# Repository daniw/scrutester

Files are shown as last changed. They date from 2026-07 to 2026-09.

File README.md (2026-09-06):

# Scrutester
Battery powered tester for electrical inspection in formula student. 

## Functions
* Voltage source 0 .. 60V, 1A max
* Current source 0 .. 10A, 5V max
* Milliohm resistance measurement with 4 wire connection, 1A measurement current
* Isolation resistance measurement with adjustable test voltage up to 1000V DC
* Voltmeter &pm; 1000V
* Amperemeter &pm; 10A
* Charging from output terminals

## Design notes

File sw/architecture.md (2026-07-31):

# BatSource — Firmware Architecture

> Lives in this repo (moved from the older `bat_Source` checkout) so it travels
> with the code it describes. If you change firmware structure, change this file
> in the same commit.

## 1. Hardware Platform

### Microcontroller
**STM32G474VET6** (Arm Cortex-M4, 170 MHz)
- Selected for its High-Resolution Timer (HRTIM, 217 ps resolution) needed for precise converter PWM
- 512 KB flash, 128 KB SRAM
- 5× ADC, 2× DAC, HRTIM, I2C, SPI, UART, QUADSPI, RTC

### Key External ICs

| IC | Role | Interface |
|----|---|---|
| BQ76905 (TI) | Battery Management System — 4-cell LiFePO₄ monitoring, protection, passive balancing | I2C4 (0x08) |
| ADS131M04 (TI) | 4-ch precision sigma-delta ADC for isolation current measurement | SPI3 |
| LMG2100R044 ×2 (TI) | GaN half-bridge drivers for primary buck-boost converter | HRTIM GPIO |
| 1EDN7512B | Gate driver for HV flyback primary switch | HRTIM GPIO |
| W25N01GV | 1 Gbit QSPI NAND flash — menu icon store, intended for data logging | QUADSPI |
| ZD24C02B | 2 kbit I2C EEPROM for calibration / ID data | I2C4 (0x50) |
| TCA9554 (PCA9554) | I2C I/O expander — hardware ID reading | I2C4 (0x20) |
| LP5817 / LP5816 | LED drivers — status LEDs and LCD backlight on UI board | I2C4 (0x2D / 0x2C) |
| OPT3004 | Ambient light sensor — automatic backlight control | I2C4 (0x44) |
| LCD (240×320 TFT) | Display — sunlight-readable, replaces original OLED | SPI4 (bit-banged) |

### Battery
4× Tenpower IFR26700-45HE LiFePO₄ cells in series (~14.4 V nominal, 56.96 Wh).
The BQ76905 monitors each cell, measures pack current via a 5 mΩ shunt, and controls charge/discharge MOSFETs.

---

## 2. Power Conversion Topology

### Primary Converter (LV — PS1-1BA)
- **Topology**: 4-switch synchronous buck-boost
- **Switches**: 2× LMG2100R044 GaN half-bridges (44 mΩ R_DS(on), 35 A rated)
- **Switching frequency**: 1 MHz (high-speed mode) / 50 kHz (low-speed mode)
- **Modes**: Battery charging, 60 V voltage out, 10 A current out, resistance measurement

### Secondary / HV Converter (PS1-1BA)
- **Topology**: Isolated flyback (final design)
- **Purpose**: Generate up to 500 V for insulation resistance testing
- **Primary switch**: 200 V MOSFET driven by 1EDN7512B gate driver
- **Transformer**: Custom RM5 core, 8-turn primary
- **Control**: PWM via HRTIM at 350 kHz, RCD snubber on primary switch node

### Output Stage
- Output relays K1/K2/K3 for galvanic isolation between measurement paths
- Gas discharge tubes (GDT) for transient suppression on output terminals
- Shrouded 4 mm safety jacks (Stäubli SLB4-F6.3)

---

## 3. Firmware Architecture

### Design Pattern
Bare-metal, **event-driven**, single-threaded. No RTOS.

```
┌──────────────────────────────────────────────┐
│                   main()                     │
│   peripheral init → main loop                │
│                                              │
│   while(1) {                                 │
│     cli_loop();                              │
│     process_event(event_Get());              │
│     HAL_Delay(1);                            │
│   }                                          │
└──────────────────────────────────────────────┘
         │
         ▼
┌────────────────────┐    ┌────────────────────────────┐
│   Event Queue      │    │  ADC1 DMA-complete ISR     │
│   (64 entries)     │    │  ~25 kHz (CTRL_FREQ)       │
│   event.h/.c       │    │  adc_convert_fast_data()   │
│                    │    │  ctrl_main_ctrl()          │
└────────────────────┘    └────────────────────────────┘
         │
         ▼
┌─────────────────────────────┐
│  State Machine (20 ms tick) │
│  statemachine.h/.c          │
│  Dispatches to mode modules │
└─────────────────────────────┘
```

### Event System (`event.h` / `event.c`)
- Circular queue of 64 `EVENT_STRUCT` items
- Each event carries: type (`EVENTS` enum), optional callback pointer, optional argument
- ISRs and peripheral callbacks post events; the main loop drains them
- `event_Add()` reserves, fills and publishes a slot inside one critical
  section. This is deliberate: filling then publishing lock-free is **not** safe
  here, because reading `head` and filling the slot are separate steps, and a
  producer preempted between them can clobber a slot another producer has
  already published.

| Event | Trigger |
|---|---|
| `EVENT_IIC_RX/TX` | I2C DMA transfer complete |
| `EVENT_IIC_ERROR` | I2C NACK / bus error |
| `EVENT_EEPROM_READ` | EEPROM read complete |
| `EVENT_EEPROM_TIMEOUT` | EEPROM no-response |
| `EVENT_SM_STEP` | State-machine timer tick (20 ms) |
| `EVENT_BMS_TIMER` | BMS polling timer (1 s) |

### State Machine (`statemachine.h` / `statemachine.c`)
Step period: **20 ms** (`STATEMACHINE_STEP_PERIOD_mS`), driven from TIM2 via the
software timer list in `timer.c`. Handles UI menu navigation, output enable
logic, and the protection interlock.

| Mode | Description |
|---|---|
| `STATEMACHINE_IDLE` | Startup / menu navigation |
| `STATEMACHINE_MODE_60V_OUT` | 60 V regulated voltage output (hold OUT to enable) |
| `STATEMACHINE_MODE_10A_OUT` | 10 A regulated current output (hold OUT to enable) |
| `STATEMACHINE_MODE_RESISTANCE_1A` | Milliohmmeter, 1 A pulsed excitation |
| `STATEMACHINE_MODE_RESISTANCE_1mA` | Ohmmeter, 1 mA excitation |
| `STATEMACHINE_MODE_ISOMETER` | Insulation resistance test (HV flyback active) |
| `STATEMACHINE_MODE_VOLTMETER` | Passive voltage measurement |
| `STATEMACHINE_MODE_AMPMETER` | Passive current measurement (SEK half-bridge shorted) |
| `STATEMACHINE_MODE_SETTINGS` | Settings menu |
| `STATEMACHINE_MODE_SHUTDOWN` | Controlled power-down sequence |
| `STATEMACHINE_MODE_CHARGE` | Internal battery charging — auto-entered from IDLE when a 15–24 V supply is detected, not user-selectable |

Settings sub-modes (`statemachine_settings_modes_t`): `MENU`, `BMS`,
`DISPLAY`, `CALIBRATION`, `ABOUT`.

Per-mode data (control mode, relay/shunt mask, enable GPIO, entry flags, ADC
trigger) is centralised rather than duplicated across `statemachine.c`,
`ctrl_main.c`, `adc.c` and `aux_io_ctrl.c` — see `mode_table.c`.

### Control Loop (`ctrl_main.h/c`, `ctrl_PID_control.h/c`)

Executed from the **ADC1 DMA-complete interrupt**, not directly from HRTIM.
The chain is: HRTIM timer period → HRTIM ADC trigger (with post-scaler) → ADC
conversion → DMA → `HAL_ADC_ConvCpltCallback()`, which acts only for `hadc1`
and decimates by 2 (`adc_interrupt_cnt`). With the converter at 1 MHz and an
HRTIM ADC post-scaler of ÷20, that lands at **25 kHz = `CTRL_FREQ`**.

`CTRL_FREQ` is what every integral gain and startup ramp is scaled by, so any
change to switching frequency or post-scaler changes the effective loop tuning.

**PID controller** (`ctrl_PID_control.h`): generic P/I/D with integrator-
clamping anti-windup and configurable saturation limits. The D term is compiled
out (`NO_D_PART`); all loops run as PI.

**Tunable loops** — `ctrl_pid_table[]` in `ctrl_main.c` is the single source of
truth. Each row carries the live controller, its EEPROM-backed calibration
fields, its defaults and its duty saturation limits. `ctrl_main_init()`,
`config_store_setDefaults()` and the CLI's `setPI` / `saveEEPROM` /
`readEEPROM` all iterate it, so adding a loop means adding one row.

| # | Name | Used for |
|---|---|---|
| 0 | Buck | Buck voltage (resistance modes) |
| 1 | Boost | 60 V output |
| 2 | Current | 10 A output |
| 3 | BoostIoutLimit | Output current limiter on the boost path |
| 4 | ChargeCurrent | CC phase of charging |
| 5 | ChargeVoltage | CV tail of charging |
| 6 | HVVoltage | ISOMETER HV flyback voltage |
| 7 | HVCurrent | ISOMETER leakage-current limiter |

**Key parameters** (`ctrl_param.h`):

| Parameter | Value |
|---|---|
| `CTRL_FREQ` | 25 000 Hz |
| `CTRL_PARAM_SW_FREQ_HIGH` | 1 000 000 Hz |
| `CTRL_PARAM_SW_FREQ_LOW` | 50 000 Hz |
| `CTRL_PARAM_SW_FREQ_HV` | 350 000 Hz |
| `CTRL_PARAM_CHARGE_CURRENT_mA` | 1000 mA |
| `CTRL_PARAM_CHARGE_END_VOLTAGE_mV` | 14 200 mV (3550 mV × 4) |
| `CTRL_PARAM_CHARGE_TAPER_CURRENT_mA` | 225 mA |

> **Note**: PID gains remain initial/placeholder values. No tuning has been
> performed — see Known Issues.

### Charging (CC/CV)
Auto-entered from IDLE when the terminal voltage is 15–24 V, no BMS fault is
latched, and the pack is below the end voltage minus a restart margin. Runs
constant-current until the end voltage, then latches (one-way) into a
constant-voltage tail. The cycle completes once the pack is at the end voltage
**and** current has tapered below `CTRL_PARAM_CHARGE_TAPER_CURRENT_mA`.

---

## 4. Peripheral Map

### ADC
| Instance | DMA | Role |
|---|-----|---|
| ADC1 | DMA1_Channel2 | `I_OUT` — **carries the control loop** |
| ADC2 | DMA1_Channel3 | `V_TERM` |
| ADC3 | DMA1_Channel4 | `V_IN` |
| ADC4 | DMA1_Channel5 | `V_OUT` / `V_HV` (channel switched per mode) |
| ADC5 | DMA1_Channel1 | 12-channel scan: rails, NTCs, VBAT, VREFINT; plus an injected group for `I_ISO` / `I_BAT` |

ADC5 uses 256× hardware oversampling with 4-bit right shift (effective 16-bit result).

`adc_configure_mode()` re-points triggers and channels per operating mode.
HRTIM ADC triggers: TRG1 ← Timer B (PRIM, ÷20), TRG2 ← Timer C (HV, ÷15),
TRG3 ← Timer E (SEK, ÷20).

**Concurrency**: `adc_data.raw` is DMA-written and declared `volatile`.
`adc_data.converted` is computed in the ISR into a private instance and copied
into the globally visible one as a single snapshot under a critical section,
once per state-machine tick (`adc_snapshot_converted()`), so main-context
readers never see a torn mix of two sample instants. `ctrl_main_ctrl()` takes
`const ADC_CONVERTED_DATA *` so it cannot reach for raw or calibration fields
that the ISR-side instance does not populate.

### Interrupt Priorities (`irq_priority.h`)
`HAL_Init()` sets `NVIC_PRIORITYGROUP_4` and `__NVIC_PRIO_BITS` is 4, so all
four bits are preemption priority (range 0–15, no subpriority). Lower = more
urgent.

| Tier | Value | IRQs |
|---|---|---|
| `IRQ_PRIO_CTRL_LOOP` | 0 | DMA1_Channel2 (ADC1) — the control loop, and only this |
| `IRQ_PRIO_EXT_ADC` | 4 | Other ADC DMA channels, SPI3 + its DMA, EXTI2 (ADS131M04 DRDY) |
| `IRQ_PRIO_AUX` | 8 | I2C4, SPI4/LCD, TIM2 (state machine), TIM6 |

SysTick stays at 15 (`TICK_INT_PRIORITY`).

Because the control loop can now preempt `statemachine_step()`,
`ctrl_main_stop_control()` clears `mode` **before** disabling PWM and
`ctrl_main_start_ctrl()` assigns `mode` **last**. That ordering is load-bearing
— a preempting tick must see either `CTRL_MODE_OFF` or a fully configured mode,
never a half-built one.

### DAC
| Channel | Signal | Purpose |
|---|---|---|
| DAC1_CH1 (PA4) | `VREF_2_UC` | Analog reference voltage |
| DAC1_CH2 (PA5) | `I_1A_REF` | 1 A current reference for resistance mode; driven as a 1 Hz / 50 % square wave via TIM6 so the milliohm reading can be gated to the on-phase |

### I2C (I2C4: SCL=PC6, SDA=PC7)
All slaves share one bus. Transactions are queued and asynchronous (DMA +
event-driven); the queue is guarded against the I2C ISR and drops with
`ERROR_IIC_OVF` when full rather than blocking.

### SPI
- **SPI3** (PA10/11/12, CS=PA15): ADS131M04 external ADC. DRDY_N interrupt on PD2; Sync/Reset on PD0.
- **SPI4** (PE2–6): LCD display — software bit-bang due to PCB layout constraint.

### HRTIM
| Macro | Timer | `sTimerxRegs[]` index | Role |
|---|---|---|---|
| `HRTIM_CHANNEL_PRIM` | Timer B | 1 | Primary buck-boost |
| `HRTIM_CHANNEL_HV` | Timer C | 2 | HV flyback |
| `HRTIM_CHANNEL_SEK` | Timer E | 4 | Secondary winding |
| `HRTIM_CHANNEL_ALL` | — | 0xFF (sentinel) | "all channels", disable only |

`hrtim_set_freq()` and `hrtim_set_duty()` reject invalid channels and clamp the
period / compare value to `[0x60, 0xFFDF]`, the window the HRTIM imposes.

### UART (USART2: TX=PD5, RX=PD6)
CLI debug interface — calibration, diagnostics, parameter read/write. Polled,
no interrupt. Includes a keyboard-control mode (`control`) that drives the
on-device encoder/buttons from the terminal, for UI work without the display
board attached.

### QUADSPI
W25N01GV NAND flash (CS=PA2, CLK=PA3, IO=PA6/7/PB0/1). Holds the menu icon
store (`icon_store.c`, seeded from `icon_seed_data.c` via the `flashIcons` CLI
command). Data logging not yet wired up.

### Key GPIO Groups
| Group | Signals | Notes |
|---|---|---|
| Converter control | `CONV_CTRL_EN`, `CONV_CTRL_PRIM_L/H`, `CONV_CTRL_SEC_L/H`, `HV_CTRL_PRIM/EN` | Enable/disable half-bridge legs |
| Output switching | `OUT_SEL_ISO`, `OUT_SEL_HV`, `SHUNT_EN`, `SHUNT_ISO_EN` | Route signal paths, driven per mode from `mode_table[]` |
| Protection | `OVP_N`, `OVP_RESET`, `OCP_N`, `DISCHARGE_N` | Latch reset and discharge control |
| BMS | `BMS_CTRL_WAKEUP` (PF9) | Wake BQ76905 from low-power state |
| UI inputs | `BUTTON_ESC` (PD4), `BUTTON_OUT` (PB9), `BUTTON_OK` (PE1), `ENCODER_A/B` | User controls |
| UI detect | `UI_PRESENT` | Detects whether display board is connected |

---

## 5. Configuration, Calibration and Protection

### Persistent config (`config_store.c`, `eeprom.c`)
Versioned layout on the 256-byte I2C EEPROM: an 8-byte header (`psvn`), a
16-byte `hardware_data` block (serial number) and a 192-byte `calibration`
block, each with its own CRC32. A block is adopted only if its CRC checks out,
so a corrupt block falls back to defaults rather than leaving garbage in a live
calibration value. Loaded at boot before `adc_init()` and `ctrl_main_init()`.

Holds ADC offset/gain trims for six internal channels plus their external-ADC
counterparts, all 16 PID gains, pack capacity, and the 1 A reference DAC code.

### Calibration (`calibration.c`)
Six calibratable channels (`V_TERM`, `V_SENS`, `V_OUT`, `V_HV`, `I_OUT`,
`I_ISO`), each with a zero step and an optional gain step. Reachable from both
the Settings > Calibration screen and the CLI (`zeroCal`, `gainCal`,
`setOffset`, `setGain`). Persists immediately on each step.

### Protection (`protection.c`)
Polled once per state-machine tick. Classifies the four external NTC
temperatures into OK / WARNING / ERROR with hysteresis, and latches the `OVP_N`
and `OCP_N` hardware fault pins as ERROR. `OCP_N` is only evaluated in ISOMETER
mode, where it is meaningful.

An ERROR-level fault forces the converter output off from `statemachine_step()`
regardless of mode. Button-gated modes require the OUT button to be released
and pressed again before resuming; CHARGE drops back to IDLE and re-enters on
its own if the supply is still present.

---

## 6. Source Module Reference

| File (Core/Src/) | Role |
|---|---|
| `main.c` | Peripheral init, main event loop |
| `statemachine.c` | 11-mode FSM, UI navigation, protection interlock |
| `mode_table.c` | Per-mode descriptor table — single source of truth for mode data |
| `ctrl_main.c` | Control mode dispatch, per-mode PI loops, PID registry |
| `ctrl_PID_control.c` | Generic PI with integrator-clamping anti-windup |
| `adc.c` | ADC config per mode, scaling, ISR conversion + snapshot |
| `protection.c` | OVP/OCP and temperature supervision |
| `config_store.c` | Versioned, CRC'd EEPROM configuration store |
| `eeprom.c` | ZD24C02B I2C EEPROM driver |
| `calibration.c` | Per-channel offset/gain calibration |
| `event.c` | 64-entry event queue |
| `timer.c` | Software millisecond timers on TIM2 |
| `list.c` | Fixed-pool list used by `timer.c` |
| `error.c` | Error code ring buffer (persistence not implemented) |
| `bq76905.c` | BMS driver (I2C, voltage/current/temp, balancing, SoC) |
| `ads131m04.c` | External 4-ch ADC driver (SPI, CRC, gain config) |
| `hrtim.c` | HRTIM init, frequency/duty helpers, SEK short for AMPMETER |
| `dac.c` | DAC reference output, 1 Hz square wave for milliohm mode |
| `temp_conv.c` | NTC resistance → temperature conversion |
| `display.c` | Screen layout and rendering (calls µGUI) |
| `menu.c` | Menu tree: order, names, accent colours, procedural icons |
| `icon_store.c` | Menu icon bitmaps in QSPI flash, with procedural fallback |
| `input.c` | Encoder/button abstraction with debounce; HW or CLI-simulated |
| `ui_ctrl.c` | Status LEDs and ambient-adaptive backlight |
| `opt3004.c` | Ambient light sensor |
| `lp581x.c` | LP5816/LP5817 LED driver |
| `driver_pca9554.c` | I/O expander for hardware ID reading |
| `w25n01gv.c` | QSPI NAND flash driver |
| `cli.c` | UART command parser (calibration / diagnostics / keyboard control) |
| `aux_io_ctrl.c` | Relay and GPIO output helpers |

---

## 7. Build and Verification

Built with STM32CubeIDE (managed build, `-Os`). The bundled ARM toolchain lives
under `/opt/st/stm32cubeide_*/plugins/…gnu-tools-for-stm32.*/tools/bin/`.

There is no unit test harness and no host build. The automated check available
is **`sw/bat_source/tools/check.sh`**, which syntax-compiles every
`Core/Src/*.c` with `-Wall -Wextra` using the same flags as `.cproject` and
diffs the diagnostics against `tools/warnings.baseline`. New warnings fail;
resolved ones are reported as progress. `--update` regenerates the baseline.

Run it after every change. It compares on (file, diagnostic text) and ignores
line numbers, so unrelated edits above a warning do not perturb it. It does not
link, so section sizes and stack headroom still need a full CubeIDE build.

---

## 8. Error Handling

**Error codes** (`error.h`):

| Code | Cause |
|---|---|
| `ERROR_IIC_READCONF` | I2C config read failed |
| `ERROR_IIC_INIT` | I2C init failed |
| `ERROR_IIC_SELFTEST` | I2C self-test failed |
| `ERROR_IIC_OVF` | I2C queue overflow |
| `ERROR_TTC_OVF` | Timer queue overflow |
| `ERROR_EVENT_OVF` | Event queue overflow |
| `ERROR_EEPROM_TIMEOUT` | EEPROM did not acknowledge |

Errors are queued but **not persisted** — `error_Write()` is an unimplemented
stub. The queue is guarded against ISR / main-context races.

**Hardware protection layers:**
1. **BMS** (BQ76905) — over/under-voltage, over-current, over-temperature per cell; watchdog
2. **OCP latch** — analog overcurrent detection via shunt; blocks gate driver via `OCP_N`
3. **OVP crowbar** — shorts converter secondary when output voltage exceeds threshold; latch requires explicit `OVP_RESET`
4. **Active discharge** — MOSFET Q18 safely dissipates stored energy on shutdown
5. **Firmware** — `protection.c` plus the interlock in `statemachine_step()` (see §5)

---

## 9. UI & Display

- **Display**: 240×320 TFT LCD, driven via µGUI + custom LCD driver (`Library/LCD/`)
- **Backlight**: LP5816 LED driver, brightness faded toward an OPT3004-derived target
- **Controls**: Rotary encoder (quadrature) + 3 pushbuttons (ESC, OUT, OK), debounced in `input.c`
- **Icons**: bitmaps from QSPI flash when available, procedural vector glyphs otherwise
- **Display boards**: Isolated supply from a forward converter on PS1-1BA; PS1-2BA carries the display, encoder, and LED driver ICs

---

## 10. Known Issues & Open Items

| # | Area | Issue |
|---|---|---|
| 1 | Power-on | Inrush current (~26 A) triggers BMS overcurrent at startup — precharge circuit needs redesign |
| 2 | GaN drivers | Bootstrap capacitor discharge limits maximum converter on-time at low duty cycles |
| 3 | I2C | Level shifter outputs 2.4 V instead of 3.3 V — marginal for some slaves |
| 4 | Current meas. | ~100 mA noise floor on instrumentation amp output |
| 5 | Isolation meas. | 129 µA offset on isolation current channel (op-amp input leakage) |
| 6 | Voltage ref | Reference rail requires output load capacitor for stability |
| 7 | PID tuning | **All PID gains are placeholder values; no tuning has been performed.** This matters more than it used to: the HV loops previously defaulted to zero gain, which silently disabled ISOMETER. They now default to real (untuned) values, so ISOMETER will actually drive the flyback. Treat the first run as a bench bring-up. |
| 8 | ISOMETER ADC | `adc_configure_mode()` does not assign the shared hadc1..4 trigger for ISOMETER, so its control-loop rate inherits whatever mode ran before it — while `CTRL_FREQ`-scaled gains assume 25 kHz. Deferred pending bench validation. |
| 9 | Ohmmeter ADC | `RESISTANCE_1mA`'s case label in `adc_configure_mode()` is commented out, so it gets no ADC trigger **and** no hadc4 configure/start — yet its buck loop regulates on `converted.v_out`, which hadc4 supplies. Deferred pending bench validation. |
| 10 | Charge thresholds | The CC→CV latch tests the internal, uncalibrated `v_in`, while cycle termination tests the BMS `StackVoltage`. Same threshold, two different sensors. |
| 11 | Calibration UI | The Settings > Calibration screen re-runs `adc_configure_mode()` and blocking delays every tick, and does not restore the previous mode's ADC routing on exit. |
| 12 | Data logging | QSPI flash driver exists and holds the icon store, but logging is not wired into the application |
| 13 | Error log | `error_Write()` is an unimplemented stub, so queued errors are discarded |

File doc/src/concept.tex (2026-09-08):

\section{Concept}
\label{sec:concept}

\subsection{Charging}
The user must be able to recharge the internal energy source. Multiple concepts are discussed: 

\begin{itemize}
    \item Integrated power supply with mains connector
        \\
        The device is connected to mains for charging. The integrated power supply provides the protective insulation. 
    \item Charging through output plugs
        \\
        A DC voltage is applied to the output pins when the device is switched of, which powers the charger. No insulation is necessary, because no electrically conductive parts are exposed. 
    \item Wireless charging
        \\
        The charger is powered with an alternating magnetic field that is applied from outside the device enclosure, similar to Qi chargers for phones. This might lead to a increased heat output when charging inside the storage enclosure. 
    \item External power supply with integrated charger
        \\
        An external power supply provides the power for charging. Depending on the selected connector type, protective insulation on the charging input or output port might be required. 
\end{itemize}

\subsection{Energy source}
To select an energy source, the following requirements have to be considered: 
\begin{itemize}
    \item \ReqRef{R:Battery} (Internally powered)
    \item \ReqRef{R:Bat_Replace} (Battery replacable)
    \item \ReqRef{R:Endurance} (Runtime)
    \item \ReqRef{R:60V} (Output voltage in voltage mode)
    \item \ReqRef{R:60V_Current} (Output current in voltage mode)
    \item \ReqRef{R:BSPD_Current} (Output current in current mode)
    \item \ReqRef{R:BSPD_Voltage} (Output voltage in current mode)
\end{itemize}

Based on these requirements, the power (\autoref{eq_bat_pow_req}) and energy (\autoref{eq_bat_energy_req}) requirements can be extracted by using an estimated overall efficiency of 0.8. 
\begin{align}
    P_{volt_{max}}
    = U_{volt_{max}} \cdot I_{volt_{max}}
    = \qty{60}{\volt} \cdot \qty{1}{\ampere}
    = \qty{60}{\watt}
\end{align}
\begin{align}
    P_{current_{max}}
    = U_{current{max}} \cdot I_{current{max}}
    = \qty{5}{\volt} \cdot \qty{10}{\ampere}
    = \qty{50}{\watt}
\end{align}
\begin{align}
    \label{eq_bat_pow_req}
    P_{Bat_{max}}
    = \dfrac{max\left(P_{volt_{max}}, P_{current_{max}}\right)}{\eta}
    = \dfrac{\qty{60}{\watt}, \qty{50}{\watt}}{\qty{0.8}{}}
    = \qty{75}{\watt}
\end{align}
\begin{align}
    \label{eq_bat_energy_req}
    E_{Bat_{max}}
    = P_{Bat_{max}} \cdot t_{run}
    = \qty{75}{\watt} \cdot \qty{0.5}{\hour}
    = \qty{37.5}{\watt\hour}
\end{align}

\begin{itemize}
    \item Lead
        \\
        Heavy, low power density, availability questionable due to new european battery regulation
    \item NiMH
        \\
    \item LiIon
        \\
        Very high power- and energy density
    \item LiFePO4
        \\
        High power- and energy density
\end{itemize}

\ReqRef{R:Bat_Replace} requires the battery to be replacable without the need of special tools. For PCB-mounted batteries, a socket should be used, as soldering is considered as using special tools. 

\subsection{User interface}
The user must be able to set the operation mode and adjust the output current. The output voltage and current should be shown to the user. \\
If the cover of the enclosure is transparent, the display can be placed inside the enclosure, which allows for an inherent water proof construction. 

\subsubsection{User interaction}
\begin{itemize}
     \item Touch control
        \\
        Multiple touch sensors can be implemented that can be actuated through the enclosure. No tactile feedback is provided unless an additional actuator is implemented. 
    \item Hall sensors with external magnet
        \\
        Hall sensors can be integrated inside the enclosure which can be actuated by a magnet from outside the enclosure, which would inherently provide ingress protection. A magnet is needed to operate the device, which must always be kept close to the device and there is no tactile feedback as well. 
    \item Buttons / switches
        \\
        Depending of the type of button / switch selected, this provides feedback to the user. The buttons / switches must include ingress protection as they protrude through the enclosure. 
    \item Rotary encoder
        \\
        A rotary encoder with integrated push-button can be used. This solution will provide feedback to the user. The encoder must include ingress protection for water. 
\end{itemize}

\subsubsection{Display type}
\begin{itemize}
     \item 7-segment
        \\
    \item 13-segment
        \\
    \item Alphanumeric
        \\
    \item Dot marix
        \\
    \item Graphical
        \\
\end{itemize}

\subsubsection{Display technology}
\begin{itemize}
     \item \acs{LED}
        \\
        A \ac{LED} display is self-illuminating and therefore especially good readable in low-light conditions. For readability in sunlight, the brightness of the display must be sufficiently high. An automatic adjustment of the brighness might be beneficial. 
    \item \acs{LCD}
        \\
        \acp{LCD}
    \item \acs{TFT}
        \\
    \item \acs{OLED}
        \\
    \item \acs{VFD}
        \\
    \item E-paper display
        \\
\end{itemize}

\subsubsection{Calibration}
\ReqRef{R:Calibration} requires a means to calibrate the output values of the tester. Therefore a communication interface must be implemented to allow sending and receiving commands and measurement values. 

\begin{itemize}
    \item User interface
        \\
        The values are entered through the user interface. This eliminates the need for additional hardware for the calibration procedure. 
    \item Wired connection
        \\
        A wired conections (\ac{USB}, RS232, Ethernet) allows easy connection to the device, but might require additional galvanic isolation between the interface and the output terminals. 
    \item Optical
        \\
        An optical interface (eg. IRDa) allows for wireless communication with inherent galvanic insulation. As it requires line-of-sight to the device, it can not be accessed from large distances or connected to the wrong device, when handling multiple devices. 
    \item Radio
        \\
        Radio communication (Wifi, Bluetooth, \ldots) allows for wireless communication with inherent galvanic insulation. The range allows for a very flexible setup for calibration. 
    \item Magneto-optic
        \\
        An assymmetric interface with a magnetic field for one direction and optical communication for the oposite direction allows for wireless communication with inherent galvanic insulation. As this would be a custom interface, the implementation will require more effort. The magnetic field might interfere with the measurements during calibration. 
\end{itemize}

\FloatBarrier
\subsection{Mechanical Design}
\todo[inline]{Check which parts belong to the hardware / mechanical section rather than concept}

\subsubsection{Enclosure}
An off-the-shelf enclose CSACTT04 manufactured by Camdenboss is used to house all components. The variant with a transparent lid is used. 

\subsubsection{Battery}
The battery cells are mechanically mounted using a battery holder that is produced using additive manufacturing. \todo{better word for 3D-printing?} 
Nickel strips are spot-welded to the cell tabs and soldered into the PCB. The nickel strips have a width of \qty{6}{\milli\meter} and a thickness of \qty{0.3}{\milli\meter}. 
The battery holder and the \ac{PCB} are mounted to the mounting posts of the enclosure using four screws. 

\subsubsection{Output terminals}
Shrouded \qty{4}{\milli\meter} plugs SLB4-F6.3 produced by Stäubli are used for the output terminals. Due to space constraints on the main PCB, the plugs are moved outside the enclosure by \qty{100}{\milli\meter} \todo{Add actual spacing} by an additively manufactured spacer. The spacer is glued to the enclosure. \todo{Specify glue?} The plugs need to be pushed into the spacer from the outside and fastened from the inside. Because the original tool \todo{better name?} is too long for use inside the enclosure, a custom nut is manufactured to tighten the plugs. 

\subsubsection{User interface}
The user interface PCB is mounted to the lid of the enclosure using screws and spacers. The buttons must be mounted to the lid before soldering them on the PCB. 

\subsubsection{Ingress protection}

\FloatBarrier
\subsection{EMI Concept}

\FloatBarrier
\subsection{Interfaces}

\FloatBarrier
\subsection{Cost estimation}
\todo[inline]{Check if the table is still required and remove it if not needed any longer. Otherwise consider updating it. }
%\STautoround*{2}

% Output Converter: 
% - Inductor Boost 22uH, Buck 820nH-1.3uH
% Think abour PCB integrated winding --> Check 10A capability
% L =1.50 Fr
% MOSFETs: ca 1Fr pro Stück

% Enclosure (CHDX6-321C): 8.85

%% Alternative zu Display: 
% - 4x 7-Segment: 1.- mit Schieberegister 0.80 Fr und ein paar LEDs --> 2.20Fr

%% Alternative zum teueren Halter: 
% 36-246-ND Benötigt 2 pro Zelle -> 1.00 Fr pro Akku

\nprounddigits2
\begin{table}[h!]
    \centering
    \begin{spreadtab}{{zebratabular}{p{0.27\linewidth}lN{3}{2}n{5}{2}p{0.4\linewidth}}}
        \rowcolor{gray}
        @ Component                     & @ Qty & @ Cost    & @ Total cost              & @ Comment \\
        \rowcolor{gray}
        @                               & @     & @{[CHF]}  & @{[CHF]}                  & @  \\
        @ Battery                       & 4     & 3.00      & [-2,0]*[-1,0]   & @ LiFePO4 26650 \\
        @ Battery holder                & 4     & 3.00      & [-2,0]*[-1,0]   & @ Alternative: 36-246-ND $\to$ 2.00 CHF \\
        @ BMS                           & 1     & 1.00      & [-2,0]*[-1,0]   & @ TI BQ77905 \\
        @ ON/OFF controller             & 1     & 1.00      & [-2,0]*[-1,0]   & @  \\
        @ Output converter              & 1     & 6.00      & [-2,0]*[-1,0]   & @ Boost Inductor: \qty{22}{\micro\henry}, Buck Inductor: \qty{820}{\nano\henry} \ldots \qty{1.3}{\micro\henry}, consider PCB-integrated winding (check 10A capability), L = 1.50CHF, MOSFET: 1 CHF per piece \\
        @ Internal supply               & 1     & 3.00      & [-2,0]*[-1,0]   & @  \\
        @ Voltage measurement           & 2     & 0.30      & [-2,0]*[-1,0]   & @  \\
        @ Current measurement           & 2     & 0.80      & [-2,0]*[-1,0]   & @  \\
        @ Output terminal               & 2     & 3.50      & [-2,0]*[-1,0]   & @ Stäubli 23.3000-21 / 23.3000-22 or Stäubli 23.3060-21 / 23.3060-22 \\
        @ Cables                        & 1     & 0.10      & [-2,0]*[-1,0]   & @  \\
        @ Overvoltage protection        & 1     & 0.50      & [-2,0]*[-1,0]   & @  \\
        @ Reverse polarity protection   & 1     & 3.00      & [-2,0]*[-1,0]   & @ Fuse: 3AB, 3AG ($\frac{1}{4}$" x $1 \frac{1}{4}$") \\
        @ Discharge                     & 1     & 2.00      & [-2,0]*[-1,0]   & @  \\
        @ Microcontroller               & 1     & 3.00      & [-2,0]*[-1,0]   & @  \\
        @ Voltage reference             & 1     & 1.00      & [-2,0]*[-1,0]   & @  \\
        @ Display                       & 1     & 5.00      & [-2,0]*[-1,0]   & @ E-paper, Alternative to display: 4x 7-segment with shift-register and some leds $\to$ 2.20 CHF \\
        @ Button                        & 1     & 4.00      & [-2,0]*[-1,0]   & @ 7346710 \\
        @ Rotary encoder                & 1     & 2.00      & [-2,0]*[-1,0]   & @ Bourns PAC18R / Bourns 3315 \\
        @ LED                           & 1     & 0.20      & [-2,0]*[-1,0]   & @  \\
        @ Enclosure                     & 1     & 8.85      & [-2,0]*[-1,0]   & @ CHDX6-321C \\
        @ Label                         & 1     & 2.00      & [-2,0]*[-1,0]   & @  \\
        @ Seal                          & 1     & 0.00      & [-2,0]*[-1,0]   & @  \\
        @ Lightguide                    & 1     & 0.10      & [-2,0]*[-1,0]   & @  \\
        @ PCB                           & 1     & 1.30      & [-2,0]*[-1,0]   & @  \\
        @                               & 0     & 0.00      & [-2,0]*[-1,0]   & @  \\
        \rowcolor{gray}
        @ Total                         &       &           & sum(d2:[0,-1])            & @
    \end{spreadtab}
    \caption{Cost estimation}
    \label{tab:cost_estimation}
\end{table}

\subsection{Standards}

\subsubsection{IEC 61010-2-34}
SAFETY REQUIREMENTS FOR ELECTRICAL EQUIPMENT FOR MEASUREMENT, CONTROL, AND LABORATORY USE – Part 2-034: Particular requirements for measurement equipment for insulation resistance and test equipment for electric strength

\FloatBarrier

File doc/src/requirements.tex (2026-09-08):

\section{Requirements}

\subsection{Functional requirements}
\begin{table}[h!]
    \begin{ReqTable}
    \ReqHeader
    \ReqItem{R:Battery}{The tester is internally powered. The internal energy source can be recharged. }
    \ReqItem{R:Charger}{The device includes a charger. }
    \ReqItem{R:Charger_enclosure}{The device can be charged inside the storage enclosure. }
    \ReqItem{R:Bat_Status}{An indicator provides information about the state of charge. }
    \ReqItem{R:Bat_Replace}{The internal energy source can be easily replaced using basic tools. Screwdrivers and pliers are considered basic tools. A soldering iron is considered a special tool, therefore no soldering must be required to replace the energy source. }
    \ReqItemMM{R:Chargingtime}{Charging time: }{}{$\qty{4}{\hour}$}
    \ReqItemMM{R:Endurance}{Runtime at maximum power output: }{$\qty{30}{\min}$}{}
    \ReqItem{R:60V}{Output mode to provide 60V}
    \ReqItemMM{R:60V_Tolerance}{Allowed deviation from target voltage in voltage mode: }{}{$\qty{1}{\percent}$}
    \ReqItemMM{R:60V_Current}{Output current in voltage mode: }{$\qty{1}{\ampere}$}{}
    \ReqItem{R:BSPD}{Output mode to provide an adjustable current}
    \ReqItemMM{R:BSPD_Current}{Maximum output current in current mode}{$\qty{10}{\ampere}$}{}
    \ReqItemMM{R:BSPD_Tolerance}{Allowed deviation from target output current in current mode: }{}{$\qty{1}{\percent}$}
    \ReqItemMM{R:BSPD_Voltage}{Maximum output voltage in current mode}{$\qty{5}{\volt}$}{}
    \ReqItem{R:Output}{The output terminals must be shrouded \qty{4}{\milli\meter} jacks. }
    \ReqItem{R:Calibration}{A means to calibrate the output values is provided. }
    \ReqItemMM{R:Temp_Operation}{Operating temperature}{\qty{0}{\celsius}}{\qty{50}{\celsius}}
    \ReqItemMM{R:Temp_Storage}{Storage temperature}{\qty{0}{\celsius}}{\qty{50}{\celsius}}
    \end{ReqTable}
\end{table}
\todo[inline]{Define operational temperature range.}
\todo[inline]{Define storage temperature range.}

%\clearpage

\subsection{Safety requirements}
\begin{table}[h!]
    \begin{ReqTable}
    \ReqHeader
    \ReqItem{R:Iso}{The device must provide galvanic isolation between the charging port and the output terminals. }
    \ReqItem{R:Overvolt}{The device must not be permanently damaged when connected to \qty{600}{\volt}. }
    \ReqItemMM{R:Overvolt_CAT}{Overvoltage category}{CAT III \qty{600}{\volt}}{}
    \ReqItem{R:Short}{A short circuit of the battery or the charging port must be prevented. }
    \ReqItem{R:Overcurrent}{An overcurrent protection for the battery must be included. }
    \ReqItem{R:BMS}{The battery must be protected against deep-discharge, over-charge, overcurrent and over-temperature. }
    \ReqItemMM{R:Rain}{The device must be able to operate in rain. The enclosure fulfills an ingress protection of at least: }{IP54}{}
    \end{ReqTable}
\end{table}

\clearpage

\subsection{Optional requirements}
\begin{table}[h!]
    \begin{ReqTable}
    \ReqHeader
    \ReqItem{R:Disp}{Output voltage and / or current are displayed}
    \ReqItem{R:Disp_bright}{Display is readable in bright sunlight}
    \ReqItem{R:Disp_dark}{Display is readable in low-light conditions}
    \ReqItem{R:Res}{A constant current with low ripple is provided to measure low-value resistance. }
    \ReqItemMM{R:Res_current}{Measurement current range}{\qty{0}{\ampere}}{\qty{1}{\ampere}}
    \ReqItem{R:Res_kelvin}{Additional measurement inputs allow the measurement of resistor values using the 4-wire connection method (Kelving connection). }
    \ReqItem{R:Iso}{Insulation resistance measurement mode}
    \ReqItemMM{R:Iso_voltage}{Insulation resistance measurement test voltage}{\qty{50}{\volt}}{\qty{500}{\volt}}
    \end{ReqTable}
\end{table}

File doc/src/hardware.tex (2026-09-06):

\section{Hardware}

\FloatBarrier

\subsection{Overview}
\label{sec_hw_overview}
\begin{itemize}
    \item Block diagram
\end{itemize}

\FloatBarrier

\subsection{Battery}
\label{sec_battery}
For the cell chemistry, a \ac{LFP} battery is selectedi. This due to its rather high energy and power density and especially due to the safer handling compared with \ac{LiIon} and \ac{LiPo} batteries.  

To select a suitable cell, a market analysis is performed. 
\begin{table}[h!]
    %\begin{spreadtab}{{zebratabular}{p{0.27\linewidth}lN{3}{2}n{5}{2}p{0.4\linewidth}}}
    \begin{spreadtab}{{zebratabular}{llllllllllllll}}
        \rowcolor{gray}
        @Manufacturer,  Type                & @$C_{typ}$                & @$I_{max}$            & @Cells    & @$P_{max}$        & @$W_{max}$                 & @Cost per device & @Runtime      \\
        @Lithium Werks, ANR26650            & @\qty{2.6}{\ampere\hour}  & @\qty{50}{\ampere}    & @5        & @\qty{500}{\watt} & @\qty{40}{\watt\hour}      & @35.75           & @\qty{32}{\minute}    \\
        @JGNE,          HTPFR26650          & @\qty{3.0}{\ampere\hour}  & @\qty{30}{\ampere}    & @5        & @\qty{375}{\watt} & @\qty{46.4}{\watt\hour}    & @17.70           & @\qty{37.12}{\minute} \\
        @JGNE,          HTCFR26650          & @\qty{3.6}{\ampere\hour}  & @\qty{10.2}{\ampere}  & @4        & @\qty{375}{\watt} & @\qty{45.44}{\watt\hour}   & @8.60            & @\qty{36.352}{\minute} \\
        @JGNE,          HTCFR26650          & @\qty{3.8}{\ampere\hour}  & @\qty{11.4}{\ampere}  & @4        & @\qty{114}{\watt} & @\qty{48}{\watt\hour}      & @10.76           & @\qty{38.4}{\minute} \\
        @JGNE,          JGCFR26650-4\ldots  & @\qty{4.0}{\ampere\hour}  & @\qty{12}{\ampere}    & @3        & @\qty{90}{\watt}  & @\qty{37.92}{\watt\hour}   & @8.97            & @\qty{30.336}{\minute} \\
        @Tenpower,      IFR26700-45HE       & @\qty{4.5}{\ampere\hour}  & @\qty{9}{\ampere}     & @4        & @\qty{90}{\watt}  & @\qty{56.96}{\watt\hour}   & @7.80            & @\qty{45.568}{\minute} \\
        @Tenpower,      IFR26700-40HE       & @\qty{4.0}{\ampere\hour}  & @\qty{8}{\ampere}     & @4        & @\qty{80}{\watt}  & @\qty{50.56}{\watt\hour}   & @7.40            & @\qty{40.448}{\minute} \\
    \end{spreadtab}
    \caption{Cell selection}
    \label{tab_cell_selection}
\end{table}
The IFR26700-45HE made by Tenpower is selected as a compromise between low cost and reasonable margin in runtime and output power. 4 cells in series are used. The cells are mounted using custom cell holders. Nickel tabs are spot-welded to the cells and soldered to the \ac{PCB}. 
\todo[inline]{Description of cell holder}

\begin{figure}[h!]
    \centering
    
    \caption{\acs{BMS} - battery cells}
    \label{fig_bat_cells}
\end{figure}

The schematic is prepared for a configuration with 5 cells in series. To enable the 5S configuration, BAT5 to BAT9 are set to fitted, the text C3 is replaced with a matching net label and the connection between C2 and C3 is removed. If both, 4S and 5S should be possible with the same \ac{PCB}, BAT2 is replaced with the design item id BAT\_LFP-26700-4.5AH-2NEG. It includes an extra pad, which is shorted to the negative cell connection using the cell tab by bending it and soldering it to both pads. This extra pad is used to short BAT7, which is not used in 4S configuration. \autoref{fig_bat_2neg} demonstrates the use of this third pad. 
\begin{figure}[h!]
    \centering
    
    \caption{Visualisation of third pad which is bridged by the negative cell tab}
    \label{fig_bat_2neg}
\end{figure}

\FloatBarrier

\subsection{Battery Management System}
\label{sec_bms}
The battery must be protected against deep-discharge, over-charge, overcurrent and overtemperature. (\ReqRef{R:BMS})
This is implemented with the battery monitor and protector BQ76905. It is powered directly from the batteries and can be configured through its \ac{I2C} interface. The cells are connected to the battery monitor with a \qty{100}{\ohm} resistor for overcurrent protection. These resistors also limit the balancing current. 
\begin{align}
    I_{Bal} 
    = \dfrac{U_{Bal}}{R_{Bal}} 
    = \dfrac{n_{Bal} \cdot U_{cell}}{2 \cdot R_C + n_{Bal} \cdot R_{CB}}
    = \dfrac{n_{Bal} \cdot U_{cell}}{2 \cdot \qty{100}{\ohm} + n_{Bal} \cdot R_{CB}}
\end{align}
\begin{align}
    I_{Bal_{typ}} 
    = \dfrac{n_{Bal_{typ}} \cdot U_{cell_{typ}}}{2 \cdot R_C + n_{Bal_{typ}} \cdot R_{CB_{typ}}}
    = \dfrac{1 \cdot \qty{3.65}{\volt}}{2 \cdot \qty{100}{\ohm} + 1 \cdot \qty{93}{\ohm}}
    = \qty{12.46}{\milli\ampere}
\end{align}
\begin{align}
    I_{Bal_{min}} 
    = \dfrac{n_{Bal_{min}} \cdot U_{cell_{min}}}{2 \cdot R_C + n_{Bal_{min}} \cdot R_{CB_{max}}}
    = \dfrac{1 \cdot \qty{2.0}{\volt}}{2 \cdot \qty{100}{\ohm} + 1 \cdot \qty{200}{\ohm}}
    = \qty{5}{\milli\ampere}
\end{align}
\begin{align}
    I_{Bal_{max}} 
    = \dfrac{n_{Bal_{max}} \cdot U_{cell_{max}}}{2 \cdot R_C + n_{Bal_{max}} \cdot R_{CB_{min}}}
    = \dfrac{4 \cdot \qty{3.65}{\volt}}{2 \cdot \qty{100}{\ohm} + 4 \cdot \qty{53}{\ohm}}
    = \qty{35.44}{\milli\ampere}
\end{align}
\begin{align}
    P_{R_{C_{max}}} = I_{Bal_{max}} ^{2} \cdot R_{C} = \qty{35.44}{\milli\ampere} ^{2} \cdot \qty{100}{\ohm} = \qty{125.6}{\milli\watt}
\end{align}
All signals directly connected to the battery cells are assigned to the netclass BAT to enforce a minimum clearance. A capacitor with a value of \qty{100}{\nano\farad} is connected to each cell voltage measurement for filtering as recommended by the datasheet \cite{TI:BQ76905}. \autoref{fig_bms_volt} shows the cell connection to the \ac{BMS}. 

\begin{figure}[h!]
    \centering
    
    \caption{\acs{BMS} - battery voltage measurement}
    \label{fig_bms_volt}
\end{figure}

The temperature of the battery is measured with a \qty{10}{\kilo\ohm} \ac{NTC} thermistor with a B value of \qty{3380}{\kelvin}. The \ac{BMS} includes a pull-up resistor with a value of \qty{20}{\kilo\ohm}, therefore no external pull-up resistor is necessary. The temperature sensor is soldered to the bottom side of the PCB and glued to the cells using thermally conductive adhesive. A \qty{1}{\nano\farad} capacitor is connected in parallel to the thermistor for filtering. For testing purpose, an \ac{SMD} thermistor is placed on the PCB as well, which can be activated by bridging the solder-jumper J1. The temperature sensor is shown in \autoref{fig_bms_temp}. 

\begin{figure}[h!]
    \centering
    
    \caption{\acs{BMS} - battery temperature measurement}
    \label{fig_bms_temp}
\end{figure}

The \ac{BMS} can be woken up from deepsleep or shutdown mode by a rising edge on the pins TS or VC0. In order to allow the microcontroller to wake up the \ac{BMS}, a \ac{GPIO} pin is connected to the TS pin through a protection circuit (\autoref{fig_bms_wakeup}), which keeps the voltage on the TS pin within the absolute maximum ratings of \qty{2.1}{\volt}. \cite{TI:BQ76905}

\begin{figure}[h!]
    \centering
    
    \caption{\acs{BMS} - wakeup protection circuit}
    \label{fig_bms_wakeup}
\end{figure}

The battery current is measured with a \qty{5}{\milli\ohm} shunt resistor. The signal is filtered (2x \qty{100}{\ohm}, \qty{100}{\nano\farad}) and connected to the battery monitor. The voltage across the shunt resistor is also amplified by a difference amplifier and connected to the \ac{ADC} of the microcontroller for current control during battery charging. 

\begin{figure}[h!]
    \centering
    
    \caption{\acs{BMS} - current measurement for overcurrent protection and fuel gauge}
    \label{fig_bms_current_bms}
\end{figure}

\begin{figure}[h!]
    \centering
    
    \caption{\acs{BMS} - current measurement for the charge controller}
    \label{fig_bms_current_uc}
\end{figure}

The CHG and DSG signals connected to the on/off controller instead of directly controlling \acp{MOSFET}. As the low side is not switched, no \ac{I2C} isolator or level shifter is needed. 
The \ac{BMS} is supplied from the batteries through the pins BAT and REGSRC. Both pins are bypassed with a \qty{1}{\micro\farad} capacitor and individually connected to the top of the stack (\verb!VBAT!) through a shottky diode and a \qty{10}{\ohm} series resistor. The output of the internal voltage regulator (REGOUT) is made available for powering standby operations like buttons for powering on or an \ac{RTC} with a voltage of \qty{3.3}{\volt}. A standby battery voltage (\verb!VBAT_STBY!) is provided for the on/off controller. This voltage is available as long as all battery parameters are within the allowed range. 

\begin{figure}[h!]
    \centering
    
    \caption{\acs{BMS} - power supply}
    \label{fig_bms_power}
\end{figure}

\FloatBarrier

\subsection{On/off controller}
\label{sec_onoff}
The \ac{MOSFET} Q6 blocks any charging current to the battery when the \ac{BMS} does not allow charging. Q5 prevents discharge of the batteries and is the main power switch for the device. A precharge circuit is implemented parallel to Q5 to limit the inrush current. The precharge current is set to \qty{100}{\milli\ampere}. (\autoref{eq_i_precharge})The precharge current runs through the resistors R22 $\ldots$ R25. The \ac{BJT} Q4 pulls the gate of Q5 up when the voltage across the resistors reaches the base-emiter voltage of aproximately \qty{0.65}{\volt}. \autoref{fig_onoff_switch} shows the mains switch \acp{MOSFET} and the precharge circuit. 
\begin{align}
    \label{eq_i_precharge}
    I_{precharge} = \dfrac{U_{BE} \cdot n_{R_{Precharge}}}{R_{Precharge}}
    = \dfrac{\qty{0.65}{\volt} \cdot 4}{\qty{27}{\ohm}} = \qty{96.3}{\milli\ampere}
\end{align}

\begin{figure}[h!]
    \centering
    
    \caption{On/off controller - highside switch with precharge circuit}
    \label{fig_onoff_switch}
\end{figure}

The charging \ac{MOSFET} Q6 is directly controlled by the \ac{BMS} through the signal \verb!BMS_ON_OFF.CHG!, which is level-shifted and inverted with Q17. The discharging \ac{MOSFET} Q5 can be enabled by the signal \verb!UI_ON_OFF.ON! (Q14), which is active when any of the on-enabled buttons (see \secref{sec_ui}\todo{Consider more precise reference to buttons}) is pressed. The microcontroller is able to keep the device running by the signal \verb!ON_REQ! (Q15) which should be set high immediatelly after boot. To turn the device off, the microcontroller sets the signal \verb!ON_REQ! low. The on logic is only activated through Q16, when the signal \verb!BMS_ON_OFF.DSG! is active. After enabling the device, the precharge circuit is activated through R40. The gate voltage of the precharge \ac{MOSFET} Q3 is monitored by Q11. When precharge is completed, the current limiter is inactive, which causes the gate voltage to drop to 0, which enables the main \ac{MOSFET} Q5 through the level-shifter Q11 and Q10. 

\begin{figure}[h!]
    \centering
    
    \caption{On/off controller - logic}
    \label{fig_onoff_logic}
\end{figure}

\FloatBarrier

To disable the device when the microcontroller is unable to turn off the device, an emergency shut-off is implemented as shown in \autoref{fig_onoff_emergency_off}. Pressing the ESC button pulls the signal BUTTON\_OFF high. This charges the capacitor C17 through the level-shifter Q13, Q9. The comparator U3 compares the voltage across the capacitor with half of the supply voltage and disables the \ac{MOSFET} Q5 and the precharge Q3 through the level shifters Q12, Q7 and Q8. The comparator is primarilly supplied from the output of the on/off controller VIN through the diode D5. To keep the \ac{MOSFET} disabled until the ESC button is released, the comparator is also supplied with the BUTTON\_OFF signal through D7. Without that secondary supply, the ESC button would turn on the device when the supply of the comparator is discharged. 

\begin{figure}[h!]
    \centering
    
    \caption{On/off controller - emergency off circuit}
    \label{fig_onoff_emergency_off}
\end{figure}

\FloatBarrier

\subsection{Low voltage converter}
\label{sec_lv_converter}
\begin{itemize}
    \item Converter design
    \item Component selection
    \item Charging operation
\end{itemize}

Multiple output voltages are generated by the low voltage converter depending on the operating mode of the device. As the converter is also used to charge the battery from a voltage applied to the terminals, it must be bidirectional. All operating modes, in which the low voltage converter is runngin are listed in \autoref{tab_lv_conv_modes}. 
\begin{table}[h!]
    \begin{zebratabular}{llllp{0.25\textwidth}}
        \rowcolor{gray}
        operating mode          & input voltage             & output voltage            & output current                & remarks \\
        battery charging        & \qtyrange{5}{60}{\volt}   & \qtyrange{8}{14.4}{\volt} & \qtyrange{0}{4.5}{\ampere}    & reversed direction \\
        voltage supply          & \qtyrange{8}{14.4}{\volt} & \qtyrange{0}{60}{\volt}   & \qtyrange{0}{1}{\ampere}      & - \\
        current supply          & \qtyrange{8}{14.4}{\volt} & \qtyrange{0}{5}{\volt}    & \qtyrange{0}{10}{\ampere}     & - \\
        resistance measurement  & \qtyrange{8}{14.4}{\volt} & \qtyrange{0}{5}{\volt}    & \qtyrange{0}{1}{\ampere}      & current controlled by linear current controller \\
        current measurement     & n/a                       & \qty{0}{\volt}            & \qtyrange{0}{10}{\ampere}     & secondary half-bridge shorted to minimize voltage drop across terminals \\
        overvoltage protection  & n/a                       & \qty{0}{\volt}            & \qtyrange{0}{10}{\ampere}     & secondary half-bridge shorted to lower power dissipation in crowbar \\
    \end{zebratabular}
    \caption{Operating modes of the low voltage converter}
    \label{tab_lv_conv_modes}
\end{table}

The low voltage converter is a 4-switch buck-boost converter. It is supplied from the battery voltage directly after the on/off controller. The power stage is build with two \ac{GaN} half bridges LMG2100R044 from Texas Instuments. The LMG2100R044 continains two \ac{GaN} \acp{FET} with gate driver. They offer a typical $R_{DS_{ON}}$ of \qty{44}{\milli\ohm}, a maximum supply voltage of \qty{90}{\volt} and a maximum continuous drain current of \qty{35}{\ampere}. The half bridges are connected by an inductor. The input and output are stabilized with ceramic capacitors. The converter is operated at a switching frequency of \qty{1}{\mega\hertz}. 
\todo[inline]{Design of inductor and DC-link capacitors}
The integrated low side gate driver is supplied with \qty{5}{\volt}. The high side gate driver is supplied by an integrated bootstrap diode, which charges the bootstrap capacitor C39 / C40. The discharge of the bootstrap capacitor limits the maximum on-time of the high-side switch as by \autoref{eq_bootstrap_ton}. 
\begin{align}
    \label{eq_lv_conv_sup_bypass}
    C_{VCC} 
    \geq \dfrac{2 \cdot Q_{G} + Q_{RR}}{\Delta V} 
    = \dfrac{2 \cdot \qty{9.3}{\nano\coulomb} + \qty{2}{\nano\coulomb}}{\qty{100}{\milli\volt}} 
    = \qty{206}{\nano\farad}
\end{align}
\begin{align}
    \label{eq_bootstrap}
    C_{BST} = \dfrac{Q_{G} + Q_{RR} + I_{HB} \cdot t_{ON_{max}}}{\Delta V}
\end{align}
\begin{align}
    \label{eq_bootstrap}
    t_{ON_{max}} 
    = \dfrac{C_{BST} \cdot \Delta V - Q_{G} - Q_{RR}}{I_{HB}}
    = \dfrac{\qty{1}{\micro\farad} \cdot \qty{100}{\milli\volt} - \qty{9.3}{\nano\coulomb} - \qty{2}{\nano\coulomb}}{\qty{4.5}{\milli\ampere}}
    = \qty{19.7}{\micro\second}
\end{align}
The control signals are blocked by an enable logic which stops the converter from running when the enable signal from the microcontroller is missing or when the \ac{OVP} latch is active. The \ac{OVP} latch only blocks the primary side. This allows the microcontroller to activte both \acp{FET} on the secondary stage in shoot-through to prevent overheating of the thyristor during continuous crowbar activation. This is possible as the gate driver of the half bridge does not include any shoot-through protection. See \secref{sec_ovp} for detailed operation of the crowbar. The secondary half bridge is olso activated in shoot-through for current measurement. The measurement funcionallity is explained in \secref{sec_meas}. The half bridge with the enable logic is shown in \autoref{fig_lv_conv_powerstage}. 

\begin{figure}[h!]
    \centering
    
    \caption{Low voltage converter - power stage with logic}
    \label{fig_lv_conv_powerstage}
\end{figure}

When the converter is not in use, the output can be discharged with the discharge circuit shown in \autoref{fig_lv_conv_discharge}. The current through the discharge \ac{MOSFET} Q18 is measured with the shunt resistor R59 and controlled by the \ac{BJT} Q20. The discharge circuit can be deactivated with the signal \verb!DISCHARGE/! and Q19. 
\begin{align}
    \label{eq_lv_discharge_current}
    I_{Dsg} 
    = \dfrac{V_{Q20_{BE}}}{R59}
    = \dfrac{\qty{0.6}{\volt}}{\qty{30}{\ohm}}
    = \qty{20}{\milli\ampere}
\end{align}
\begin{align}
    \label{eq_lv_discharge_power}
    P_{Dsg_{max}} 
    = I_{Dsg} \cdot V_{LV_{max}}
    = \dfrac{V_{Q20_{BE}}}{R59} \cdot V_{LV_{max}}
    = \dfrac{\qty{0.6}{\volt}}{\qty{30}{\ohm}} \cdot \qty{60}{\volt}
    = \qty{1.2}{\watt}
\end{align}
\begin{figure}[h!]
    \centering
    
    \caption{Low voltage converter - discharge}
    \label{fig_lv_conv_discharge}
\end{figure}

The temperature of the inductor and the two half bridges are measured with the \ac{NTC} thermistors R54, R55 and R56 as per \autoref{fig_lv_conv_temperature}. \autoref{f:temp_ntc} The thermistors are placed as close as possible to the components which are measured. 
\begin{align}
    \label{f:temp_ntc}
    R_{NTC} 
    = R_{N} \cdot e^{B \cdot \left(\dfrac{1}{\vartheta} - \dfrac{1}{\vartheta_{N}}\right)}
    = \qty{10}{\kilo\ohm} \cdot e^{\qty{3380}{\kelvin} \cdot \left(\dfrac{1}{\vartheta} - \dfrac{1}{\qty{25}{\celsius}}\right)}
\end{align}
\begin{align}
    V_{NTC} 
    = V_{Ref} \cdot \dfrac{R_{NTC}}{R_{pullup} + R_{NTC}}
    = V_{Ref} \cdot \dfrac{R_{NTC}}{\qty{10}{\kilo\ohm} + R_{NTC}}
\end{align}
\begin{align}
    \dfrac{V_{NTC}}{V_{Ref}}
    = \dfrac{R_{NTC}}{R_{pullup} + R_{NTC}}
    = \dfrac{1}{\dfrac{R_{pullup}}{R_{NTC}} + 1}
\end{align}
\begin{align}
    \dfrac{V_{Ref}}{V_{NTC}} - 1
    = \dfrac{R_{pullup}}{R_{NTC}}
\end{align}
\begin{align}
    R_{NTC}
    = \dfrac{R_{pullup}}{\dfrac{V_{Ref}}{V_{NTC}} - 1}
\end{align}
\begin{align}
    \vartheta
    = \dfrac{1}{\dfrac{1}{\vartheta_{N}} + \dfrac{ln\left(\dfrac{R_{NTC}}{R_{N}}\right)}{B}}
    = \dfrac{1}{\dfrac{1}{\vartheta_{N}} + \dfrac{ln\left(\dfrac{R_{pullup}}{\left(\dfrac{V_{Ref}}{V_{NTC}} - 1\right) \cdot {R_{N}}}\right)}{B}}
\end{align}

\begin{figure}[h!]
    \centering
    
    \caption{Low voltage converter - temperature measurement}
    \label{fig_lv_conv_temperature}
\end{figure}

\FloatBarrier

\subsection{High voltage converter}
\label{sec_hv_converter}
\begin{itemize}
    \item Topology
    \item Converter design
    \item Component selection
    \item Transformer design
\end{itemize}

Insulation resistance measurement requires a test voltage of \qty{500}{\volt}. This voltage is generated by the high voltage converter. It is a flyback converter as shown in \autoref{fig_hv_conv}. A \ac{MOSFET} (Q21) drives the primary side of the transformer. It has a breakdown voltage of \qty{200}{\volt}, which is required due to the genereated reverse voltage of the flyback converter. The ringing of the switch node is reduced with a RCD \todo{Is RCD the correct name for this kind of snubber?} snubber consisting of a shottky diode (D9), which charges a capacitor (C22) with the energy of the overshoot and a resistor (R62), which discharges the capacitor within a switching cycle. 
A gate driver 1EDN7512B is used to drive the switching \ac{MOSFET}. The gate driver includes an inverting and a non-inverting input. The non-inverting input is used for the \ac{PWM} to drive the \ac{MOSFET}. The inverting input is used to block the converter from operating, when no enable signal is present, or when an overcurrent is detected. For a detailed description of the overcurrent detection see \secref{sec_ocp}. 
\begin{figure}[h!]
    \centering
    
    \caption{High voltage converter}
    \label{fig_hv_conv}
\end{figure}

The transformer is custom-made and includes one primary winding, three secondary windings and a PCB with rectification, dc-link capacitors and discharge resistors. 
The transformer is based on a RM5 coil former with two chambers \todo{check teminlology} and ferrite core set. The primary winding is wound on the lower half of the coil former and has 8 turns \todo{Check transformer terminology (coil, winding, turn, $\ldots$)} of enameled \todo{Check spelling} wire with a diameter of \qty{0.5}{\milli\meter}. The secondary windings have 80 turns each of enameled wire and are connected to the transformer PCB PS1-100, which includes a rectifier diode with a blocking voltage of \qty{1}{\kilo\volt}, a \qty{33}{\nano\farad} capacitor and a discharge resistor with a total resistance of \qty{30}{\mega\ohm} for each secondary winding. The capacitors are connected in series, which allows the use of diodes with a blocking voltage equal to the output voltage. 
The three dc link capacitors are connected in series. 
\begin{figure}[h!]
    \centering
    
    \caption{High voltage converter - flyback transformer \acs{PCB}}
    \label{fig_hv_convtrafo_pcb}
\end{figure}

The output current is limited by a \ac{MOSFET} in linear operation for user safety. The minimum required output current can be determined from the \ac{FSG} rules. \cite[EV 1.2.1]{FSG:Rules_2026} The rules state a minimum isolation resistance of \qty{500}{\ohm\per\volt}, which results in a current of \qty{2}{\milli\ampere}. 

\begin{align}
R_{Lim} \leq \dfrac{V_{Z_{min}} - V_{GS_{th_{max}}}}{I_{Lim}}
    = \dfrac{\qty{12.35}{\volt} - \qty{5.0}{\volt}}{\qty{2}{\milli\ampere}}
    = \qty{3.675}{\kilo\ohm}
    \to \qty{3.6}{\kilo\ohm}
\end{align}
\begin{align}
I_{Lim_{min}} = \dfrac{V_{Z_{min}} - V_{GS_{th_{max}}}}{R_{Lim_{max}}}
    = \dfrac{\qty{12.35}{\volt} - \qty{5.0}{\volt}}{1.01 \cdot \qty{3.6}{\kilo\ohm}}
    = \qty{2.021}{\milli\ampere}
\end{align}
\begin{align}
I_{Lim_{max}} = \dfrac{V_{Z_{max}} - V_{GS_{th_{min}}}}{R_{Lim_{min}}}
    = \dfrac{\qty{13.65}{\volt} - \qty{2.5}{\volt}}{0.99 \cdot \qty{3.6}{\kilo\ohm}}
    = \qty{3.129}{\milli\ampere}
\end{align}

\begin{figure}[h!]
    \centering
    
    \caption{High voltage converter - current limiter}
    \label{fig_hv_conv_i_lim}
\end{figure}

\FloatBarrier

\subsection{Overvoltage protection}
\label{sec_ovp}

The low voltage converter is protected by a crowbar, implemented with a thyristor (D14) which is triggered by a zener diode (D13). 
\todo[inline]{Calculation of trigger voltage, tested: \qty{79.8}{\volt}}

\begin{figure}[h!]
    \centering
    
    \caption{Overvoltage protection - crowbar}
    \label{fig_overvoltage_prot_crowbar}
\end{figure}

The current in the crowbar is measured by the shunt resistor R92. The signal is amplified by 100 with a difference amplifier implemented with U8. 
\begin{align}
G = \dfrac{R85 // R90}{R88}
    = \dfrac{R95}{R94}
    = \dfrac{\qty{100}{\kilo\ohm}}{\qty{1}{\kilo\ohm}}
    = 100
\end{align}

The comparator U9 is setup as latch with a trigger value of: 
\begin{align}
V_{th} 
    = \dfrac{V_{+3V3\_A} \cdot \dfrac{1}{\dfrac{1}{R96} + \dfrac{1}{R86 + R91 + R93}}}{R84 + \dfrac{1}{\dfrac{1}{R96} + \dfrac{1}{R86 + R91 + R93}}} 
    + \dfrac{\left(V_{+3V3\_A} - V_{f_{D16}}\right) \cdot \dfrac{1}{\dfrac{1}{R84} + \dfrac{1}{R96}}}{R86 + R91 + R93 + \dfrac{1}{\dfrac{1}{R84} + \dfrac{1}{R96}}}
\end{align}
\begin{align}
V_{th} 
    = \dfrac{V_{+3V3\_A} \cdot \dfrac{1}{\dfrac{1}{\qty{10}{\kilo\ohm}} + \dfrac{1}{\qty{10}{\kilo\ohm} + \qty{100}{\kilo\ohm} + \qty{2}{\kilo\ohm}}}}{\qty{6.8}{\kilo\ohm} + \dfrac{1}{\dfrac{1}{\qty{10}{\kilo\ohm}} + \dfrac{1}{\qty{10}{\kilo\ohm} + \qty{100}{\kilo\ohm} + \qty{2}{\kilo\ohm}}}} 
    + \dfrac{\left(V_{+3V3\_A} - V_{f_{D16}}\right) \cdot \dfrac{1}{\dfrac{1}{\qty{6.8}{\kilo\ohm}} + \dfrac{1}{\qty{10}{\kilo\ohm}}}}{\qty{10}{\kilo\ohm} + \qty{100}{\kilo\ohm} + \qty{2}{\kilo\ohm} + \dfrac{1}{\dfrac{1}{\qty{6.8}{\kilo\ohm}} + \dfrac{1}{\qty{10}{\kilo\ohm}}}}
\end{align}
\begin{align}
V_{th} = \qty{1.9882}{\volt}
\end{align}
\begin{align}
I_{th} = \dfrac{V_{th} - \frac{V_{+3V3\_A}}{2}}{R_{shunt} \cdot G}
    = \dfrac{\qty{1.9882}{\volt} - \frac{\qty{3.3}{\volt}}{2}}{\qty{5}{\milli\ohm} \cdot 100}
    = \qty{0.6764}{\ampere}
\end{align}
\todo[inline]{Consider recalculating threshold for new trigger value of \qty{1}{\ampere}}
\begin{align}
V_{th} 
    = \dfrac{V_{+3V3\_A} \cdot \dfrac{1}{\dfrac{1}{\qty{10}{\kilo\ohm}} + \dfrac{1}{\qty{10}{\kilo\ohm} + \qty{100}{\kilo\ohm} + \qty{2}{\kilo\ohm}}}}{\qty{5.1}{\kilo\ohm} + \dfrac{1}{\dfrac{1}{\qty{10}{\kilo\ohm}} + \dfrac{1}{\qty{10}{\kilo\ohm} + \qty{100}{\kilo\ohm} + \qty{2}{\kilo\ohm}}}} 
    + \dfrac{\left(V_{+3V3\_A} - V_{f_{D16}}\right) \cdot \dfrac{1}{\dfrac{1}{\qty{5.1}{\kilo\ohm}} + \dfrac{1}{\qty{10}{\kilo\ohm}}}}{\qty{10}{\kilo\ohm} + \qty{100}{\kilo\ohm} + \qty{2}{\kilo\ohm} + \dfrac{1}{\dfrac{1}{\qty{5.1}{\kilo\ohm}} + \dfrac{1}{\qty{10}{\kilo\ohm}}}}
\end{align}
\begin{align}
V_{th} = \qty{2.1990}{\volt}
\end{align}
\begin{align}
I_{th} = \dfrac{V_{th} - \frac{V_{+3V3\_A}}{2}}{R_{shunt} \cdot G}
    = \dfrac{\qty{2.1990}{\volt} - \frac{\qty{3.3}{\volt}}{2}}{\qty{5}{\milli\ohm} \cdot 100}
    = \qty{1.0981}{\ampere}
\end{align}

The output of the comparator is latched with R93, which pulls the reference lower than \qty{0}{\ampere}. The latch can be reset by the signal \verb!OVP_RESET!, which activates Q25, which pulls the reference above \qty{0}{\ampere} with R82. At startup, C51 activates Q25 to ensure, that the latch is reset at startup. The red \ac{LED} D12 indicates an activeated latch. The output of the latch blocks the primary half bridge of the low voltage converter and is also read by the microcontroller, which can activate both \ac{MOSFET} of the secondary half bridge (See \secref{sec_lv_converter}), to reduce the power dissipation of the thyristor. 

\begin{figure}[h!]
    \centering
    
    \caption{Overvoltage protection - logic}
    \label{fig_overvoltage_prot_logic}
\end{figure}

\FloatBarrier

\subsection{Overcurrent protection}
\label{sec_ocp}

\begin{figure}[h!]
    \centering
    
    \caption{Overcurrent protection}
    \label{fig_overcurrent_prot_crowbar}
\end{figure}

\FloatBarrier

\subsection{Terminals}
\label{sec_terminal}

\begin{figure}[h!]
    \centering
    
    \caption{Output terminals with \acs{GDT} and voltage detection}
    \label{fig_terminals}
\end{figure}

\begin{figure}[h!]
    \centering
    
    \caption{Output relais}
    \label{fig_output_relais}
\end{figure}

\begin{figure}[h!]
    \centering
    
    \caption{Shunt resistors for current measurement}
    \label{fig_shunt}
\end{figure}

\FloatBarrier

\subsection{Current controller}
\label{sec_i_ctrl}

\begin{figure}[h!]
    \centering
    
    \caption{Current controller - feedback and control}
    \label{fig_i_ctrl_feedback}
\end{figure}

\begin{figure}[h!]
    \centering
    
    \caption{Current controller - limiter and feedforward}
    \label{fig_i_ctrl_feedforward}
\end{figure}

\begin{figure}[h!]
    \centering
    
    \caption{Current controller - temperature measurement}
    \label{fig_i_ctrl_temp}
\end{figure}

\FloatBarrier

\subsection{Measurement}
\label{sec_meas}
\begin{itemize}
    \item ADC
    \item Output voltage
    \item 4-wire voltage
    \item Output current
\end{itemize}

\begin{figure}[h!]
    \centering
    
    \caption{Measurement - terminal voltage}
    \label{fig_meas_term_volt}
\end{figure}

\begin{figure}[h!]
    \centering
    
    \caption{Measurement - output current}
    \label{fig_meas_out_current}
\end{figure}

\begin{figure}[h!]
    \centering
    
    \caption{Measurement - sens voltage}
    \label{fig_meas_sens_volt}
\end{figure}

\begin{figure}[h!]
    \centering
    
    \caption{Measurement - isolation current}
    \label{fig_meas_iso_current}
\end{figure}

\begin{figure}[h!]
    \centering
    
    \caption{Measurement - \acs{ADC}}
    \label{fig_meas_adc}
\end{figure}

\begin{figure}[h!]
    \centering
    
    \caption{Measurement - Terminal voltage for controller}
    \label{fig_meas_term_volt_uc}
\end{figure}

\begin{figure}[h!]
    \centering
    
    \caption{Measurement - current high range for controller}
    \label{fig_meas_out_current_uc}
\end{figure}

\begin{figure}[h!]
    \centering
    
    \caption{Measurement - current low range for controller}
    \label{fig_meas_iso_current_uc}
\end{figure}

\FloatBarrier

\subsubsection{Voltage measurement}
\label{sec_volt_meas}
\begin{itemize}
    \item Voltage divider
    \item Differential amplifier
\end{itemize}

\FloatBarrier

\subsubsection{Current measurement}
\label{sec_cur_meas}
\begin{itemize}
    \item Shunt selection
    \item Amplifier selection
\end{itemize}

\FloatBarrier

\subsection{Output terminals}
\label{sec_out_term}
\begin{itemize}
    \item Crowbar
    \item Fuse
    \item Reverse polarity protection
    \item current controller
\end{itemize}

\FloatBarrier

\subsection{Connection to user interface}

\begin{figure}[h!]
    \centering
    
    \caption{User interfae - button protection}
    \label{fig_ui_button_prot}
\end{figure}

\begin{figure}[h!]
    \centering
    
    \caption{User interfae - button level shifter}
    \label{fig_ui_button_levelshifter}
\end{figure}

\begin{figure}[h!]
    \centering
    
    \caption{User interfae - button on / off logic}
    \label{fig_ui_button_onoff}
\end{figure}

\begin{figure}[h!]
    \centering
    
    \caption{User interfae - connector, supply and presence detection}
    \label{fig_ui_connector}
\end{figure}

\begin{figure}[h!]
    \centering
    
    \caption{User interfae - \acs{SPI} protection}
    \label{fig_ui_spi}
\end{figure}

\begin{figure}[h!]
    \centering
    
    \caption{User interfae - encoder filtering and protection}
    \label{fig_ui_encoder}
\end{figure}

\begin{figure}[h!]
    \centering
    
    \caption{User interfae - \ac{I2C} protection}
    \label{fig_ui_i2c}
\end{figure}

\begin{figure}[h!]
    \centering
    
    \caption{User interfae - \acs{UART} and high voltage detection protection}
    \label{fig_ui_uart}
\end{figure}

\FloatBarrier

\subsection{Microcontroller}
\label{sec_microcontroller}
\begin{itemize}
    \item Microcontroller selection
    \item GPIO assignment
    \item Analog reference
\end{itemize}
The STM32F334series is selected as microcontroller. This controller is suited for controlling a DC/DC converter due to the inclusion of the \ac{HRTIM}, which allows \ac{PWM} generation with a resolution as low as \qty{217}{\pico\second}. The QFP-48 package is selected due to the solderability and number of \ac{GPIO} pins. For the prototype the mximum of \qty{64}{\kibi\byte} is selected. This leads to the selected device: STM32F334C8T

\begin{figure}[h!]
    \centering
    
    \caption{Microcontroller - \acs{RTC} crystal}
    \label{fig_uc_crystal}
\end{figure}

\begin{figure}[h!]
    \centering
    
    \caption{Microcontroller - supply}
    \label{fig_uc_supply}
\end{figure}

\begin{figure}[h!]
    \centering
    
    \caption{Microcontroller - reference voltage buffer}
    \label{fig_uc_ref_buf}
\end{figure}

\begin{figure}[h!]
    \centering
    
    \caption{Microcontroller - \acs{EEPROM}}
    \label{fig_uc_eeprom}
\end{figure}

\begin{figure}[h!]
    \centering
    
    \caption{Microcontroller - flash memory}
    \label{fig_uc_flash}
\end{figure}

\begin{figure}[h!]
    \centering
    
    \caption{Microcontroller - programming interface}
    \label{fig_uc_programming}
\end{figure}

\begin{figure}[h!]
    \centering
    %\includegraphics[page=14, scale=\schscale, trim=71 35 655 510, clip]{\schfilemain}
    
    \caption{Microcontroller - hardware identification}
    \label{fig_uc_hw_id}
\end{figure}

\begin{figure}[h!]
    \centering
    
    \caption{Microcontroller - \acs{I2C} pull-up}
    \label{fig_uc_i2c}
\end{figure}

\FloatBarrier

\subsubsection{Pinout and module usage}
\paragraph{Reference voltage}
The internal reference voltage is only directly accessible in the BGA package. To access the internal voltage reference, the output of the operational amplifier (OPAMP2\_VOUT) is used. For this the amplifiert must be configured to output the refernce voltage. (OPAMP2\_CSR: TSTREF) the referance voltage is then accessible on PA6. 

\subsubsection{Memory}
To store persistent data such as serial number or calibration data, an \ac{I2C} \ac{EEPROM} is used. 

\FloatBarrier

\subsection{\acs{I2C} address list}
All devices on the \ac{I2C} bus are listed in \autoref{tab_i2c_list} to avoid address conflicts. 
\begin{table}[h!]
    \begin{zebratabular}{lllllll}
        \rowcolor{gray}
        Function                & PCB             & Designator    & Device    & \multicolumn{2}{c}{Address}   & Supply voltage \\
        \rowcolor{gray}
                                &                 &               &           & binary    & hex               &                \\
        BMS                     &  Mainboard      & U1            & BQ76905   & 0b0001000 & 0x08              & +3V3\_STBY \\
        EEPROM                  &  Mainboard      & U25           & ZD24C02B  & 0b1010000 & 0x50              & +3V3 \\
        HW ID                   &  Mainboard      & U26           & TCA9554   & 0b0100000 & 0x20              & +3V3 \\
        LED driver              &  User interface & U7            & LP5817    & 0b0101101 & 0x2D              & VLED (UI) \\
        Ambient light sensor    &  User interface & U8            & OPT3004   & 0b1000100 & 0x44              & +3V3 (UI) \\
        Backlight driver        &  User interface & U9            & LP5816    & 0b0101100 & 0x2C              & VLED (UI) \\
    \end{zebratabular}
    \caption{\acs{I2C} address overview}
    \label{tab_i2c_list}
\end{table}

\FloatBarrier

\subsection{User interface}
\label{sec_ui}
A display shows the current operating mode and measurement values to the user. Initially an \ac{OLED} display was evaluated. During testing it was discovered, that the brightness of the display was insufficient for use in direct sunlight. 
\begin{itemize}
    \item Display
    \item Buttons
    \item Rotaty encoder
\end{itemize}

\begin{figure}[h!]
    \centering
    
    \caption{Isolated encoder}
    \label{fig_ui_endocer}
\end{figure}

\begin{figure}[h!]
    \centering
    
    \caption{Isolated encoder}
    \label{fig_ui_endocer}
\end{figure}

\begin{figure}[h!]
    \centering
    
    \caption{User interface connector}
    \label{fig_ui_connector}
\end{figure}

\begin{figure}[h!]
    \centering
    
    \caption{Terminal indicator \acsp{LED} with \ac{LED} driver}
    \label{fig_ui_led_driver}
\end{figure}

\begin{figure}[h!]
    \centering
    
    \caption{High voltage indicator}
    \label{fig_ui_hv_indicator}
\end{figure}

\begin{figure}[h!]
    \centering
    
    \caption{Display}
    \label{fig_ui_display}
\end{figure}

\begin{figure}[h!]
    \centering
    
    \caption{Ambient light sensor}
    \label{fig_ui_amb_light_sensor}
\end{figure}

\begin{figure}[h!]
    \centering
    
    \caption{Backlight driver}
    \label{fig_ui_backlight_driver}
\end{figure}

\FloatBarrier

\subsection{Power supply}
\label{sec_power_supply}
\begin{itemize}
    \item \qty{3.3}{\volt} supply
    \item Alternative charging power supply
\end{itemize}

\FloatBarrier

\subsubsection{Power supply VCC}
\label{sec_power_vcc}

\begin{figure}[h!]
    \centering
    
    \caption{Power - VCC high voltage buck converter}
    \label{fig_power_vcc}
\end{figure}

\begin{figure}[h!]
    \centering
    
    \caption{Power - VCC - logic}
    \label{fig_power_vcc_logic}
\end{figure}

\begin{figure}[h!]
    \centering
    
    \caption{Power - VCC - output or-ing}
    \label{fig_power_vcc_oring}
\end{figure}

\FloatBarrier

\subsubsection{Power supply 15\,V}
\label{sec_power_15v}

\begin{figure}[h!]
    \centering
    
    \caption{Power - \qty{15}{\volt} boost converter}
    \label{fig_power_15v}
\end{figure}

\FloatBarrier

\subsubsection{Power supply 5\,V}
\label{sec_power_5v}

\begin{figure}[h!]
    \centering
    
    \caption{Power - \qty{5}{\volt} buck converter}
    \label{fig_power_5v}
\end{figure}

\FloatBarrier

\subsubsection{Power supply 3.3\,V}
\label{sec_power_3v3}

\begin{figure}[h!]
    \centering
    
    \caption{Power - \qty{3.3}{\volt} buck converter}
    \label{fig_power_3v3}
\end{figure}

\FloatBarrier

\subsubsection{Power supply analog 3.3\,V}
\label{sec_power_3v3_a}

\begin{figure}[h!]
    \centering
    
    \caption{Power - analog \qty{3.3}{\volt} \acs{LDO} regulator}
    \label{fig_power_3v3_a}
\end{figure}

\FloatBarrier

\subsubsection{Power supply VLED}
\label{sec_power_vled}

\begin{figure}[h!]
    \centering
    
    \caption{Power - VLED}
    \label{fig_power_vled}
\end{figure}

\FloatBarrier

\subsubsection{Power supply 3.3\,V UI}
\label{sec_power_3v3_ui}

\begin{figure}[h!]
    \centering
    
    \caption{Power - \qty{3.3}{\volt} UI buck converter}
    \label{fig_power_3v3_ui}
\end{figure}

\FloatBarrier

\subsubsection{Power supply isolated 3.3\,V UI}
\label{sec_power_3v3_iso}

\begin{figure}[h!]
    \centering
    
    \caption{Power - isolated \qty{3.3}{\volt} UI forward converter - primary side}
    \label{fig_power_3v3_iso_prim}
\end{figure}

\begin{figure}[h!]
    \centering
    
    \caption{Power - isolated \qty{3.3}{\volt} UI forward converter - secondary side}
    \label{fig_power_3v3_iso_sec}
\end{figure}

\FloatBarrier

\subsection{Layout}
\label{sec_layout}

\FloatBarrier

\subsubsection{Layer stack}
\label{sec_leayout_stack}

\FloatBarrier

\subsubsection{Clearance}
\label{sec_layout_cleraance}
All signals directly connected to the battery are assignet to the netclass BAT to enforce a minumum clearance of \qty{0.5}{\milli\meter}. An exception is implemented for the gate of Q5 and I2C.SCL. This is necessary due to the low clearance of the packages of the \ac{MOSFET} Q5 and the \ac{BMS} U1. 

\FloatBarrier

\subsubsection{Component placement}
\label{sec_layout_placement}

\FloatBarrier

\subsection{Testing}
\label{sec_testing}
\begin{itemize}
    \item Automatic testing
    \item Testpoints
    \item Calibration
\end{itemize}

\FloatBarrier

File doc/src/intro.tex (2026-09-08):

\section{Introduction}
\todo[inline]{Introduction to the project, reasoning behind, $\ldots$}

\subsection{Definitions}

\subsubsection{Units}
\ac{SI} units are used in this document. 

\FloatBarrier

\subsubsection{\acs{I2C} address}
The adress of \ac{I2C} devices consists of 7 bit. On the bus, the R/W bit is appended after the \ac{LSB} of the address, which shifts the address to the left by one bit. This is shown in \autoref{fig:intro_i2c_address}. 

\begin{figure}[h!]
    \centering
    \begin{tikztimingtable}[
        % For labelled L, see:
        % https://tex.stackexchange.com/questions/37254/tikz-timing-text-labels-in-symbols-other-than-d-and-time-axis-discontinuities
        timing/metachar={{K}[2]{#1l !{++(0,+.5\yunit)} N[rectangle,scale=.6]{#2} !{++(0,-.5\yunit)} #1l}},
        timing/metachar={{J}[2]{#1h !{++(0,-.5\yunit)} N[rectangle,scale=.6]{#2} !{++(0,+.5\yunit)} #1h}},
        ]
        SDA & 2H4K{Start}4D{A6}4D{A5}4D{A4}4D{A3}4D{A2}4D{A1}4D{A0}4D{R/W}4K{Stop}2H \\
        SCL & 5H9{2L2H}3H \\
    \end{tikztimingtable}
    \caption{\acs{I2C} address}
    \label{fig:intro_i2c_address}
\end{figure}

In this documentation each \ac{I2C} address is represented without the R/W bit and right-aligned (\ac{LSB}-aligned). 

\FloatBarrier

\subsection{Directory structure}
\dirtree{%
.1 scrutester/\DTcomment{Project root}.
.2 doc/\DTcomment{Documentation}.
.3 appendix/\DTcomment{Appendix}.
.3 bib/\DTcomment{Bibliography}.
.3 img/\DTcomment{Graphics and images}.
.3 layout/\DTcomment{Package to define document layout}.
.3 obj/\DTcomment{Documentation output}.
.3 src/\DTcomment{Documentation source}.
.3 test/\DTcomment{Test protocol}.
.2 hw/\DTcomment{Hardware}.
.3 Assembly/\DTcomment{Multiboard assembly}.
.3 ST1-1/\DTcomment{Mainbard}.
.3 ST1-2/\DTcomment{User interface PCB}.
.3 ST1-3/\DTcomment{Programming adapter}.
.3 ST1-100/\DTcomment{Transformer rectifier PCB}.
.3 sim/\DTcomment{Scripts and simulations}.
.2 mech/\DTcomment{Mechanics}.
.2 sw/\DTcomment{Software}.
}
\todo{Software directory structure}
\acresetall

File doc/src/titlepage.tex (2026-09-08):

\begin{titlepage}

    %\vspace{4mm}

    \begin{center}
        %\includegraphics[height=0.5\textheight]{img/2026-03-06_Bat_Source_Multiboard_Render.png}
        
        \addcontentsline{lof}{figure}{Title image}
    \end{center} 

    \vspace{2mm}

    \begin{center}
        \rule{\textwidth}{2pt}
    \end{center}

    \vspace{2mm}

    \begin{center}
        \huge{\textbf{Scrutester}}\\
        \vspace{4mm}
        \LARGE{\textbf{Battery powered tester for electrical inspection in formula student}}\\
        \vspace{4mm}
        \Large{Technical documentation}
    \end{center}
    
    \vspace{2mm}

    \begin{center}
        \rule{\textwidth}{2pt}
    \end{center}

    \vspace{4mm}

    \begin{center}
        Authors:\\
        \large{\makeatletter \@author \makeatother}\\
        \vspace{4mm}
    \end{center}

    \vspace{3mm}

    \begin{center}
        Schwyz, \today
    \end{center}

\end{titlepage}
\clearpage

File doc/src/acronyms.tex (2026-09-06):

\section*{Acronyms}
%\addcontentsline{toc}{section}{Abkürzungen}
\begin{acronym}[Acronyms]
    \acro{ADC}{analog digital converter}
    \acro{BJT}{bipolar junction transistor}
    \acro{BMS}{battery management system}
    \acro{CRC}{cyclic reduncancy check}
    \acro{CMOS}{complementary metal oxide semiconductor}
    \acro{FEM}{finite element method}
    \acro{DeltaSigma}[$\Delta\Sigma$]{delta-sigma}
    \acro{DUT}{device under test}
    \acro{EEPROM}{electrically erasable programmable read only memory}
    \acro{ESD}{electro static discharge}
    \acro{ESR}{equivalent series resistor}
    \acro{FET}{field effect transistor}
    \acro{FSG}{Formula Student Germany}
    \acro{GaN}{gallium nitride}
    \acro{GDT}{gas discharge tube}
    \acro{GPIO}{general purpose input output}
    \acro{GUI}{Graphical User Interface}
    \acro{HRTIM}{high-resolution timer}
    \acro{I2C}[I$^{2}$C]{inter-integrated circuit}
    \acro{IC}{integrated circuit}
    \acro{IO}[I/O]{input output}
    \acro{LCD}{liquid crystal display}
    \acro{LDO}{low dropout}
    \acro{LED}{light emitting diode}
    \acro{LFP}{lithium ferrite phosphate}
    \acro{LiIon}{lithium ion}
    \acro{LiPo}{lithium polymer}
    \acro{LSB}{least significant bit}
    \acro{MOSFET}{metal oxide semiconductor field effect transistor}
    \acro{NTC}{Negative Temperature Coefficient Thermistor}
    \acro{OLED}{organic light emitting diode}
    \acro{OVP}{overvoltage protection}
    \acro{PCB}{printed circuit board}
    \acro{PWM}{pulse width modulation}
    \acro{RMS}{root-mean square}
    \acro{RTC}{real time clock}
    \acro{SAR}{successive approximation register}
    \acro{SoC}{State of Charge}
    \acro{SI}{système international d'unités}
    \acro{SMD}{surface mount device}
    \acro{SMT}{surface mount technology}
    \acro{SNR}{signal-to-noise ratio}
    \acro{SPI}{serial peripheral interface}
    \acro{TFT}{thin film transistor}
    \acro{THD}{through-hole mounted device}
    \acro{THT}{through-hole technology}
    \acro{TI}{Texas Instruments}
    \acro{UART}{universal asynchronous receiver - transmitter}
    \acro{UI}{user interface}
    \acro{USB}{universal serial bus}
    \acro{VFD}{vacuum fluorescent display}
\end{acronym}

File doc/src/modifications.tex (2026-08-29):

\section{Modification history}

\subsection{PS1-1 - Mainboard}

\subsubsection{Modifications PS1-1AA $\to$ AB}

\begin{ModTable}

\ModItemDone
{BMS wakeup from shutdown}
{When the \ac{BMS} enters shutdown mode, it can only be brought back to normal mode by a rising edge on the TS or VC0 pin. The shutdown mode is entered when sending the SHUTDOWN() command twice or when a low battery voltage is detected. After deep-discharging the battery it is not possible to charge the batteries because the \ac{BMS} remains in shutdown mode. }
{The TS pin should therefore be connected to a GPIO pin (PF0, pin 5) of the microcontroller with a wire to allow wakeup from shutdown mode. }
{daniw}
{2025-07-02}

\ModItemDone
{BMS wakeup from shutdown}
{When the \ac{BMS} enters shutdown mode, it can only be brought back to normal mode by a rising edge on the TS or VC0 pin. The shutdown mode is entered when sending the SHUTDOWN() command twice or when a low battery voltage is detected. After deep-discharging the battery it is not possible to charge the batteries because the \ac{BMS} remains in shutdown mode. }
{The TS pin should be connected to a GPIO pin (PF0, pin 5) of the microcontroller with a wire to allow wakeup from shutdown mode. }
{daniw}
{2025-07-02}

\ModItemDone
{Relay footprint mirrored}
{The footprint of the relais is mirrored. }
{The pins of the relay must be bent and extended to fit the footprint. This correction increases the height of the PCB stack by about \qty{2}{\milli\meter}, due to which the enclosure cannot be completely closed. }
{daniw}
{2025-07-02}

\ModItemDone
{Undefined signal CONF\_ISO when microcontroller not programmed or in reset}
{The signal CONF\_ISO has no defined state when it is not driven. This can happen, when the microcontroller is not programmed or held in reset. This can lead to the relays K2 and K3 to flatter when the device is powered from the output plugs. }
{A pull-down resistor to GND should be manually placed between gate and source of Q13. }
{daniw}
{2025-07-02}

\ModItemDone
{Voltage drop on UI supply}
{The voltage drop of the supplies on the user interface is too large. }
{R188 and R189 should be replaced with 0R/0603. }
{daniw}
{2025-07-02}

\ModItemDone
{High voltage detection always active when battery powered}
{The high voltage detection is always active when the device is battery-powered. This is independent of the voltage across the output plugs. It is caused by leakage current from the PRIM\_ZERO pin to the V\_OUT signal through the microcontroller. }
{Pin 2 (cathode) of D11 and D14 are lifted and connected to the respective pad using a \qty{100}{\kilo\ohm} resistor. A \qty{2.2}{\volt} Zener diode is placed between pin 2 (cathode) and pin 1 (anode) of each diode D11 and D14. }
{daniw}
{2025-07-02}

\ModItemDone
{Inrush current at startup}
{The inrush current at startup is \qty{26}{\ampere}. This triggers the \ac{BMS}, which disables the device. }
{A temporary workaround is to keep the startup button pushed until the \ac{BMS} resets. The \ac{BMS} switches the \acp{MOSFET} much slower which leads to a lower inrush current of approximately \qty{0.7}{\ampere}. }
{daniw}
{2025-07-02}

\ModItemDone
{Low resolution for battery current measurement}
{The resolution of the battery current measurement is \qty{16}{\milli\ampere} with a range of $\pm$\qty{33}{\ampere}. A current range of $\pm$\qty{10}{\ampere} is sufficient. }
{By increasing R19 and R22 to \qty{330}{\kilo\ohm}, the range is changed to $\pm$\qty{10}{\ampere} with a resolution of \qty{4.88}{\milli\ampere}. }
{daniw}
{2025-07-02}

\end{ModTable}

\FloatBarrier

\subsubsection{Modifications PS1-1AB $\to$ AC}

\begin{ModTable}

\ModItemDone
{Converter not working}
{The parasitic inductance is too large for proper operation of the flyback converter. To allow a demonstration of the \qty{60}{\volt} output, the converter is modified to a boost topology. }
{The primary windings (PS1-102) the high-voltage winding (PS1-124) are removed from the transformer. The relais K1 to K3 are removed and bridged with the \qty{0}{\ohm} resistors R65 and R78. T\_S2 is connected to VIN with a wire. A diode STPS40150CG-TR is soldered from T\_S0 (anode) to R78 (cathode). }
{daniw}
{2025-09-03}

\ModItemDone
{Zero-crossing detection not needed for demonstration device}
{The zero-crossing detection is not needed for the demonstration device and can therefore be disabled. }
{Remove R69 and R79. }
{daniw}
{2025-09-03}

\ModItemDone
{Charging not possible with boost converter}
{As the boost converter is non-synchronous and therefore unidirectional, the device can not be charged thtough the output terminals. The sense terminals are not used for the demonstration devices and can be adapted for battery charging. }
{Connect MEAS- to GND using a wire. Also connect MEAS+ to VIn through a diode. (anode MEAS+, cathode VIN)}
{daniw}
{2025-09-03}

\end{ModTable}

\FloatBarrier

\subsubsection{Modifications PS1-1AA $\to$ BA}

\begin{ModTable}

\ModItemDone
{BMS wakeup from shutdown}
{When the \ac{BMS} enters shutdown mode, it can only be brought back to normal mode by a rising edge on the TS or VC0 pin. The shutdown mode is entered when sending the SHUTDOWN() command twice or when a low battery voltage is detected. After deep-discharging the battery it is not possible to charge the batteries because the \ac{BMS} remains in shutdown mode. }
{The TS pin should be connected to a GPIO pin of the microcontroller to allow wakeup from shutdown mode. }
{daniw}
{2025-09-10}

\ModItemDone
{Relay footprint mirrored}
{The footprint of the relais is mirrored. }
{The footprint must be corrected. }
{daniw}
{2025-09-12}

\ModItemDone
{Undefined signal CONF\_ISO when microcontroller not programmed or in reset}
{The signal CONF\_ISO has no defined state when it is not driven. This can happen, when the microcontroller is not programmed or held in reset. This can lead to the relays K2 and K3 to flatter when the device is powered from the output plugs. }
{A pull-down resistor to GND should be placed on the signal CONF\_ISO. }
{daniw}
{2025-09-11}

\ModItemDone
{Voltage drop on UI supply}
{The voltage drop of the supplies on the user interface is too large. }
{R188 and R189 should be replaced with 0R/0603. }
{daniw}
{2025-09-10}

\ModItemDone
{Insufficient memory}
{The flash memory of the microcontroller is barely sufficient. As the \ac{OLED} display is replaced with a color LCD, additional memory is needed. }
{It should be considered to replace the microcontroller with a similar type that includes more flash memory. The STM32G474 series seems to be suitable. An external \ac{QSPI} flash memory should be connected to the microcontroller. }
{daniw}
{2025-12-19}

\ModItemDone
{High voltage detection always active when battery powered}
{The high voltage detection is always active when the device is battery-powered. This is independent of the voltage across the output plugs. It is caused by leakage current from the PRIM\_ZERO pin to the V\_OUT signal through the microcontroller. }
{The clamping circuit must be modified to clamp to a lower voltage than the supply voltage. }
{daniw}
{2025-09-11}

\ModItemDone
{Inrush current at startup}
{The inrush current at startup is \qty{26}{\ampere}. This triggers the \ac{BMS}, which disables the device. }
{A precharge circuit should be added to the on/off controller to limit the inrush current. }
{daniw}
{2025-12-19}

\ModItemDone
{Low resolution for battery current measurement}
{The resolution of the battery current measurement is \qty{16}{\milli\ampere} with a range of $\pm$\qty{33}{\ampere}. A current range of $\pm$\qty{10}{\ampere} is sufficient. }
{By increasing R19 and R22 to \qty{330}{\kilo\ohm}, the range is changed to $\pm$\qty{10}{\ampere} with a resolution of \qty{4.88}{\milli\ampere}. }
{daniw}
{2025-09-11}

\ModItemDone
{Clearance around battery terminals}
{The pull-up resistors for the I2C bus are very close to the battery terminals. This can lead to a short circuit and damage of components during assembly. }
{A clearance of a few millimeters around the battery terminals should be implemented. }
{daniw}
{2025-09-12}

\ModItemOpen
{\acs{UI} connector misplacement}
{During assembly of the lid, the \ac{UI} connector can be misplaced, which can lead to short circuits and damage of components. }
{The \ac{UI} connector should be replaced with a type that includes a mechanical guide. }
{}
{}

\ModItemDone
{Converter topology}
{Due to the excessive stray inductance, the flyback with switchable output range does not work as intended. The stray inductance causes overvoltage on the primary and secondary \ac{MOSFET}}
{The converter topology should be changed. A 4-switch buck-boost should work for the lower voltage ranges. A triple-output flyback similar to \url{https://www.analog.com/media/en/reference-design-documentation/design-notes/DN1047.pdf} could be used for the high voltage range. }
{daniw}
{2025-09-17}

\ModItemDone
{Noise on \acs{ADC} measurements}
{The power supply for the \ac{ADC} contains noise. This is caused by the high peak supply current of the display, as well as the converter. This is especially critical, as the reference voltage for the internal \ac{ADC} is derived from the analog supply voltage. }
{A separate supply voltage for the analog circuitry should be implemented using a linear regulator. }
{daniw}
{2025-12-19}

\ModItemDone
{High voltage detection sensitive to current from GPIO}
{The high voltage detection can easily be influenced by current from the microcontroller \ac{GPIO}. }
{A unity-gain amplifier should be added between the high voltage detection voltage divider and the \ac{GPIO}. }
{daniw}
{2025-10-06}

\ModItemDone
{Unreliable overvoltage latch without reset}
{The latch of the overvoltage protection circuit is unreliable and cannot be reset by the microcontroller. }
{Adjust the upper resistor of the reference voltage divider to \qty{6.8}{\kilo\ohm} and the feedback resistor to \qty{2}{\kilo\ohm}. Add \ac{MOSFET} pulldown to startup reset circuit to allow latch reset by the microcontroller. }
{daniw}
{2025-10-06}

\ModItemDone
{Insufficient fuse rating}
{the voltage rating of the fuse is \qty{500}{\volt}, which is insufficient for connecting it to a tractive system with a voltage of \qty{600}{\volt}. }
{The fuse should be replaced with a type that has a voltage rating of at least \qty{600}{\volt}DC. As the maximum tractive system voltage might be increased in a few years, a rating of \qty{1000}{\volt}DC should be considered. }
{daniw}
{2025-10-07}

\ModItemDone
{Battery terminal slot size}
{The slot for the battery terminals has a length of \qty{6}{\milli\meter} which is too short for the cell tab, which also has a width of \qty{6}{\milli\meter}. }
{The length of the slot for the battery terminals should be increased to \qty{8}{\milli\meter}. }
{daniw}
{2025-10-16}

\ModItemDone
{Incorrect gain of the V\_Sens measurement channel. }
{The gain of the V\_Sens \ac{ADC} channel is too low by a factor of 6. This is caused by the voltage divider being loaded by the input impedance of the \ac{ADC} which is \qty{300}{\kilo\ohm}. }
{An amplifier should be added between the voltage divider and the \ac{ADC}. }
{daniw}
{2025-12-19}

\ModItemDone
{Voltage dependence of isolation current limit}
{The isolation measurement current limit using resistors is proportional to the voltage drop across it. }
{A controlled current limiter should be implemented for the isolation measurement. }
{daniw}
{2025-12-19}

\end{ModTable}

\FloatBarrier

\subsubsection{Modifications PS1-1BA $\to$ BB}

\begin{ModTable}

\ModItemOpen
{Buck boost inductor clearance}
{The overlapping footprints of the buck boost inductor variants could potentially create a short circuit between the switch nodes and the core of the inductor PQ2012J. }
{It is highly recommended to inspect the insulation between the switch nodes and the core of the inductor and add insulating kapton tape if neccessary. }
{}
{}

\ModItemDone
{Swapped supply pins of U17 and U20}
{The supply pins of the operational amplifiers U17 and U20 are swapped, which leads to them being reverse-polarity powered. }
{The trace between the bypass capacitors (C75 and C84) and the V- pins (2) of the operational amplifiers U17 and U20 must be cut. The now disconnected pins must be connected to the GND side of the bypass capacitors using enameled wire. \newline The supply pins (5) of the operational amplifiers U17 and U20 should be lifted and connected to the +3V3\_A side of the bypass capacitors using enameled wire. }
{daniw}
{2026-05-19}

\ModItemDone
{Insufficient \ac{I2C} level}
{The high level of the \ac{I2C} signals is only \qty{2.4}{\volt} instead of the expected \qty{3.3}{\volt}. \newline This is caused by the reverse voltage of the zener diodes D35 and D36 at low current. }
{The zener diodes D35 and D36 should be removed. \newline \textbf{Caution!} This removes the overvoltage protection from the \ac{I2C} signals. }
{daniw}
{2026-05-19}

\ModItemDone
{Inaccurate voltage reference buffer output}
{The voltage reference buffer output is inaccurate. The buffer requires an output capacity in the range of \qty{0.5}{\micro\farad} $\ldots$ \qty{1.5}{\micro\farad}. }
{A \qty{1}{\micro\farad} capacitor should be added between the input (pin 3) of the external reference voltage buffer (U22) and the GND pin of C146. }
{daniw}
{2026-05-19}

\ModItemDone
{On/off controller unable to turn on}
{While precharging V\_IN, Q12 turns the prescharge off due to the pull-up resistor R37 before the comparator U3 is operating, which stops the precharge from continuing. }
{A \qty{47}{\kilo\ohm} resistor should be added from the gate of Q12 to GND. }
{daniw}
{2026-05-19}

\ModItemDone
{On/off controller does not activate main discharge MOSFET}
{The precharge detection MOSFET Q11 is unable to detect the completion of the precharge due to the still too high voltage at its gate. }
{Change R40 to \qty{1}{\kilo\ohm} or add a \qty{1.1}{\kilo\ohm} resistor parallel to R40. }
{daniw}
{2026-05-19}

\ModItemDone
{Overvoltage protection latch reset}
{The overvoltage protection latch reset does not work due to insufficient voltage at the positive input of the latch comparator. }
{Change R82 to \qty{2.4}{\kilo\ohm}. }
{daniw}
{2026-05-19}

\ModItemDone
{Overcurrent protection always active}
{The overcurrent protection is always active because the threshold does not account for the offset $\frac{VREF}{2}$ on the current mesurement. }
{Change R105 to \qty{1}{\mega\ohm} and R106 to \qty{330}{\kilo\ohm}. }
{daniw}
{2026-05-19}

\ModItemDone
{Offset in isolation current measurement}
{The isolation current measurement has an offset of \qty{129}{\micro\ampere} due to the current introduced by U14A. }
{Remove R135. }
{daniw}
{2026-05-29}

\ModItemOpen
{Ringing in current controller at turn-on}
{When increasing the current from \qty{0}{\ampere} the current shows ringing before reaching the set value. }
{Check if adding \qty{1}{\micro\farad} parallel to R144 removes the ringing. }
{}
{}

\ModItemDone
{Current measurement noise}
{The noise of the current measurement is aproximately \qty{100}{\milli\ampere}, which is caused by the input noise of the instrumentation amplifier. }
{The instrumentation amplifier should be replaced by a current sense amplifier such as INA181. The battery current measurement and isolation current measurement could also be changed to using an INA181. }
{2026-05-22}
{}

\ModItemDone
{Unreliable QSPI operation}
{The level of the pins QSPI.IO2 and QSPI.IO3 is undefined in single and dual SPI mode, which can lead to the flash entering hold or write protect mode. }
{Pull- up resistors should be added to the QSPI.IO2 and QSPI.IO3 pins. It is recommended to add a pull-up resistor fo CS/ as well. }
{daniw}
{2026-05-20}

\ModItemDone
{No detection of open SENS wires}
{The device is unable to detect if the SENS wires are connected to the \ac{DUT}. }
{A pull-up resistor should be added to SENS+ and a pull-down resistor should be added to SENS-. Due to the high voltage that can be present at the terminals, the resistors must likely be implemented using multiple resistors in series. }
{daniw}
{2026-05-27}

\ModItemDone
{Incomplete precharge}
{With the LEDs and the LCD running, the current consumption is too high (\qty{115}{\milli\ampere}) for the precharge to complete. }
{The precharge current should be increased to $\geq$ \qty{180}{\milli\ampere}. This can be achieved by reducing the value of the precharge current resistors R22 \ldots R25 to \qty{15}{\ohm}. This results in a precharge current of ???. }
{daniw}
{2026-05-26}

\ModItemDone
{Display unreliable at maximum speed}
{When the display is run at the maximum clock speed of \qty{40}{\mega\hertz}, the communication is unreliable. }
{Change resistors R206, R208, R210, R211, R212, R213 and R215 to \qty{47}{\ohm} or add \qty{62}{\ohm} in parallel. }
{daniw}
{2026-06-21}

\end{ModTable}

\FloatBarrier

\subsubsection{Modifications PS1-1BB $\to$ BC}

\begin{ModTable}

\ModItemDone
{High voltage converter relay coil polarity}
{The relay K2 does not operate due to incorrect polarity of the coil. }
{The traces between K2 and D20 must be cut and crossed using wire. }
{daniw}
{2026-08-21}

\end{ModTable}

\FloatBarrier

\subsubsection{Modifications PS1-1BC $\to$ BD}

\begin{ModTable}

\ModItemDone
{Insufficient current for isolation resistance measurement}
{The current limiter for the isolation resistance measurement is set to a value of \qty{1}{\milli\ampere}. The lowest allowed isolation resistance is \qty{500}{\ohm\per\volt}, which results in a current of \qty{2}{\milli\ampere}. }
{Change R74 to \qty{3.6}{\kilo\ohm} or add \qty{5.6}{\kilo\ohm} in parallel. }
{daniw}
{2026-08-29}

\end{ModTable}

\FloatBarrier

\subsubsection{Modifications PS1-1BA $\to$ CA}

\begin{ModTable}

\ModItemOpen
{Overvoltage category}
{The clearance is sufficient for \qty{600}{\volt} CAT II. But the formula student rules \cite{FSG:Rules_2026} require \qty{600}{\volt} CAT III for measurement equipment that is used for accumulator inspection. }
{The clearance should be increased to \qty{5.5}{\milli\meter} for basic insulation and \qty{11}{\milli\meter} for reinforced insulation to meet the criteria for \qty{600}{\volt} CAT III according to IEC 61010-1. }
{}
{}

\ModItemOpen
{Buck boost inductor selection}
{The overlapping footprints of the buck boost inductor variants could potentially create a short circuit between the switch nodes and the core of the inductor PQ2012J. }
{After testing, a single inductor type should be selected. }
{}
{}

\ModItemOpen
{Swapped supply pins of U17 and U20}
{The supply pins of the operational amplifiers U17 and U20 are swapped, which leads to them being reverse-polarity powered. }
{The supply pins of U17 and U20 must be swapped. \newline Additionally, renaming the supply pins of all operational amplifiers to V+ and V- is highly recommended for easier recognition of swapped supply pins during schematic review. }
{}
{}
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

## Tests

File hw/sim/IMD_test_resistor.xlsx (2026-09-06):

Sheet: Tabelle1
 | Voltage | BPR | 1 |  |  |  |  |  |  |  |  |  |  |  |  |  |  |  |  | Ohm | Kiloohm | Megaohm
Power 200V | 200 | 5000 | 0.09754610578 | 0.1903628792 | 0.3628117914 | 0.6611570248 | 1.111111111 | 1.632653061 | 1.975308642 | 1.893491124 | 1.451247166 | 0.9349890431 | 0.5377021634 | 0.2894454181 |  | R | 3 | 160 | 1 | 0.5
Power 400V | 400 | 10000 | 0.09876162185 | 0.1950922116 | 0.3807257585 | 0.7256235828 | 1.32231405 | 2.222222222 | 3.265306122 | 3.950617284 | 3.786982249 | 2.902494331 | 1.869978086 | 1.075404327 |  | S | 2 | 4 | 2 | 1
Power 600V | 600 | 15000 | 0.09917184621 | 0.1967078751 | 0.3869927439 | 0.749219563 | 1.40625 | 2.491349481 | 3.988919668 | 5.444234405 | 5.993756504 | 5.215029425 | 3.691716071 | 2.253410925 |  | P | 6 | 5 | 3 | 2
 |  |  |  |  |  |  |  |  |  |  |  |  |  |  |  |  |  |  | 4 | 4
 | 0805 | 0.125 | 1 | 2 | 4 | 6 | 12 | 20 | 32 | 44 | 48 | 42 | 30 | 19 |  | R tot | 1 | 128 | 5 | 8
 |  |  |  |  |  |  |  |  |  |  |  |  |  |  |  | n | 12 | 20 | 6 | 16
2s HV | 300V |  | 10R 4s + 7.5R 3s | 27R 3s + 22R 2s | 100R 5s2p | 1k 2s4p | 1k 4s4p | 10k 2s10p | 2k 8s4p | 24k 4s12p | 12k 4s12p | 16k 10s5p | 16k 12s3p | 160k 4s5p |  |  |  |  | 7 | 32
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

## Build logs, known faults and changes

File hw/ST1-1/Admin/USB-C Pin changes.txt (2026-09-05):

Additional pins for USB type C connection
=========================================

* USB Data
* CC pins
* DB (dead battery) implemented by external protection -> UCPD1_DBCC* signals not needed
* FRS (fast role swap) not supported -> UCPD1_FRST* pins not needed

New pins
========

USB_DP -> ADC.CLK (PA12, TIM16_CH1)
USB_DM -> CONV_CRTL_PRIM_H (PA11, HRTIM1_CHB2)

UCPD1_CC1 -> Encoder.B (PB6, TIM4_CH1)
UCPD1_CC2 -> Free

Resolution of pinout collisions
===============================

ENCODER.B => Encoder connected through I2C, pin no longer needed

ADC.CLK => TIM16_CH1 also available on free pins PB4 and PE0

CONV_CTRL_PRIM_H => Change CONV_CTRL_PRIM from CHB to CHA
-> collides with I_ISO and BMS_CTRL.I_BAT

I_ISO -> move to ADC3_IN2/4

BMS_CTRL.I_BAT -> move to ADC2_IN5 (OCP_N, fast ADC channel)
Move OCP_N to PF2

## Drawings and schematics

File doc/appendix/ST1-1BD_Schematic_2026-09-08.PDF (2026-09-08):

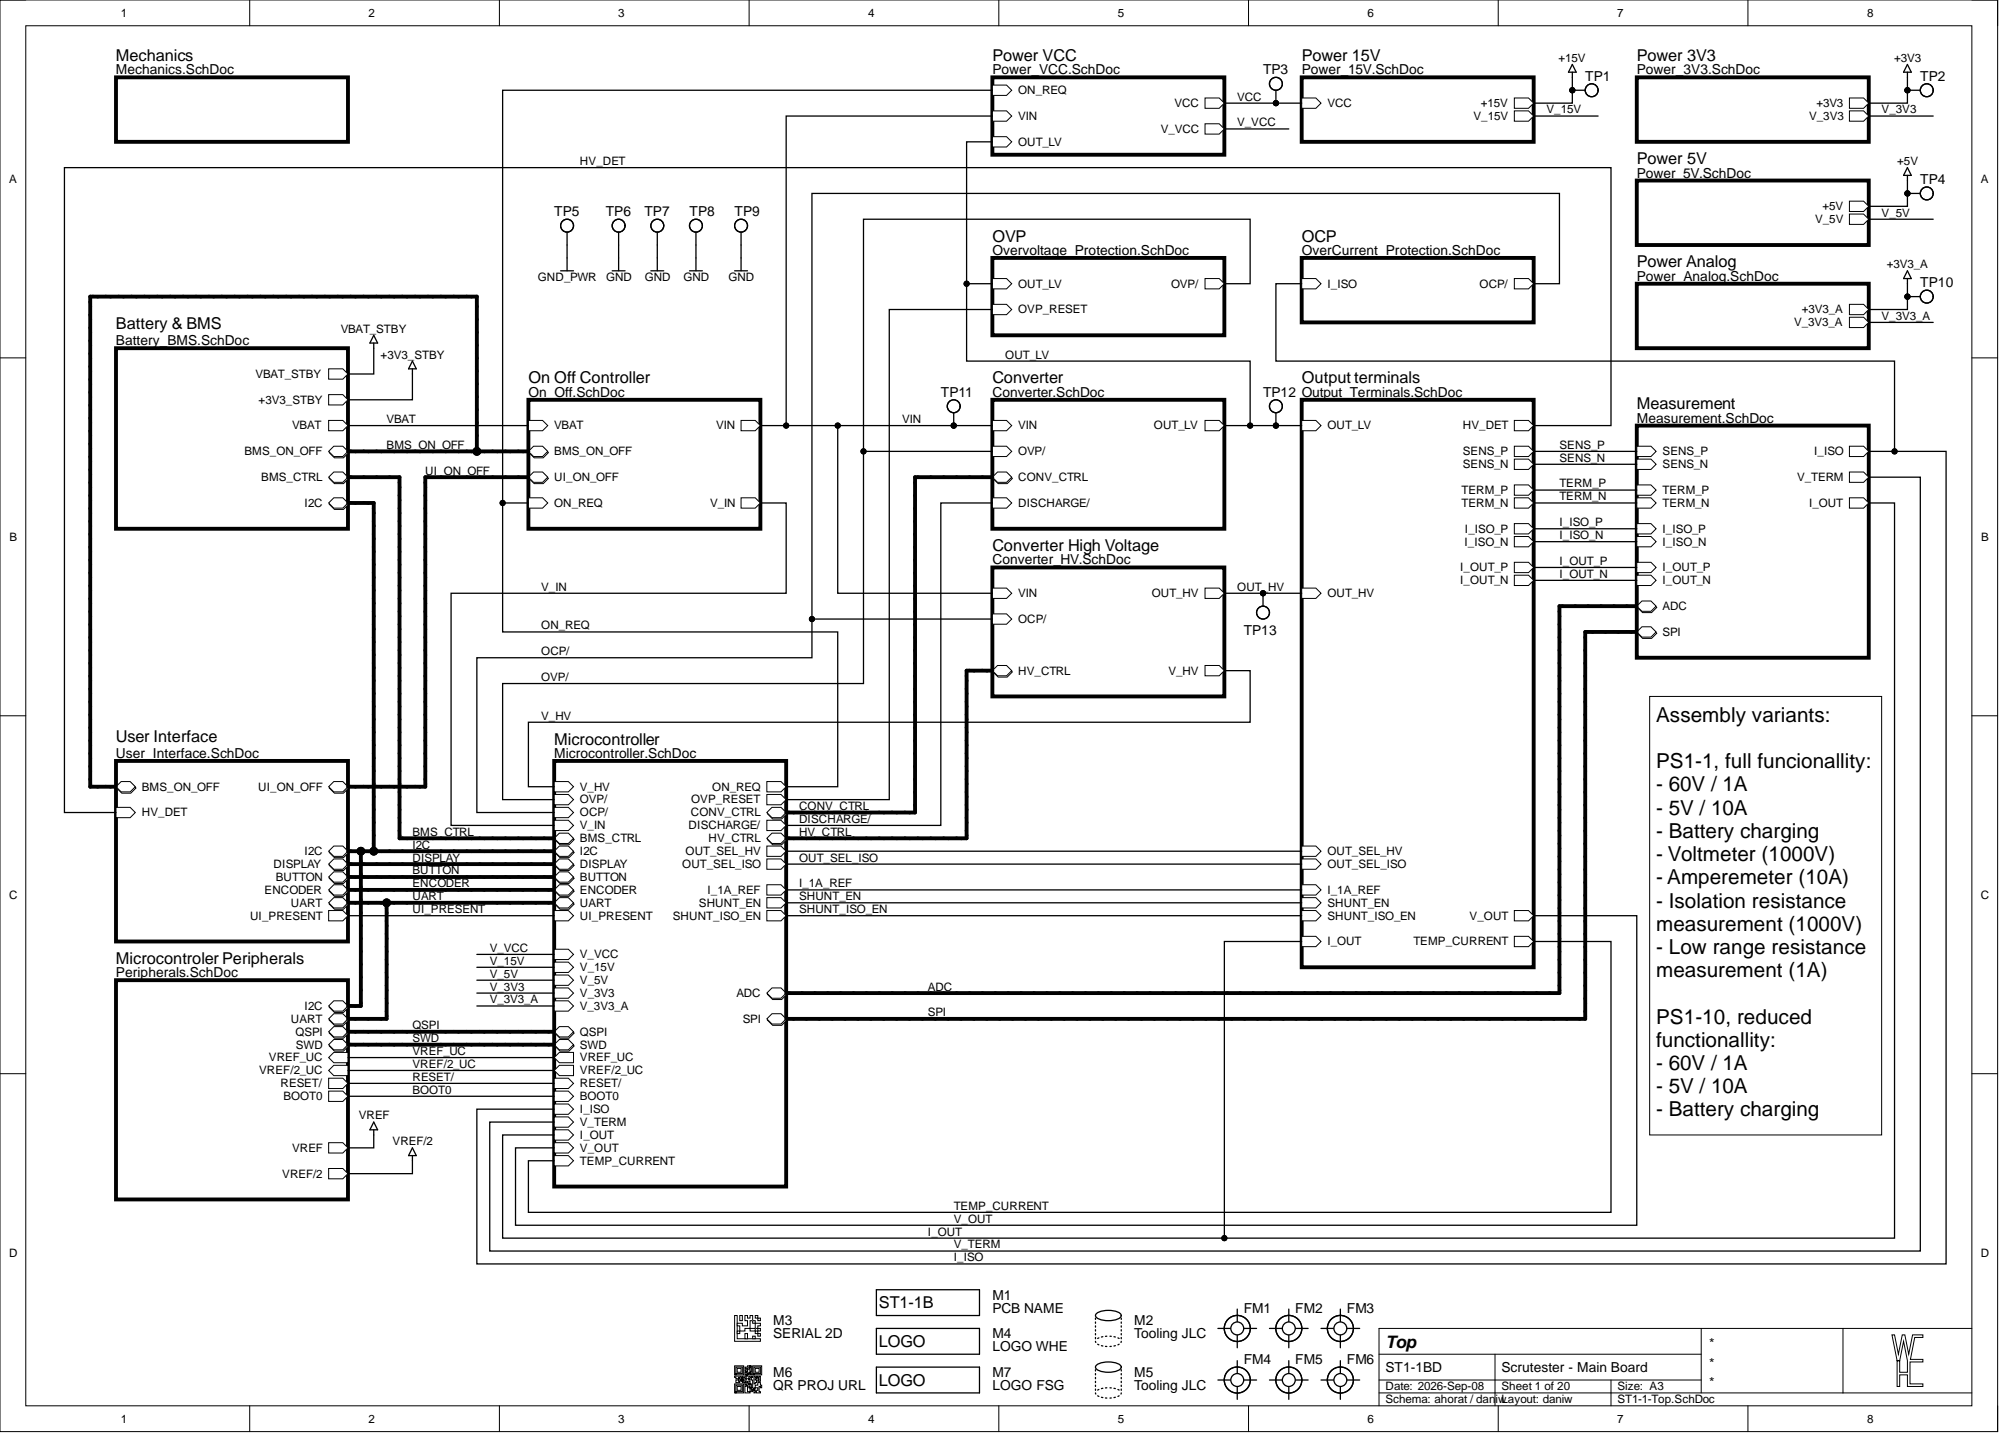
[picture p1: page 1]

BMS_ON_OFF | | SENS_P | SENS_P I_ISO SENS_N V_TERM TERM_P TERM_N I_OUT I_ISO_P I_ISO_N I_OUT_P I_OUT_N ADC SPI

Converter High Voltage Converter_HV.SchDoc

V_HV
Microcontroller Microcontroller.SchDoc

DISPLAY | | OUT_SEL_ISO
BUTTON | | I_1A_REF
ENCODER
UART | | SHUNT_EN
UI_PRESENT | | SHUNT_ISO_EN

V_VCC

2026-Sep-08
Schema: ahorat / daniwLayout: daniw

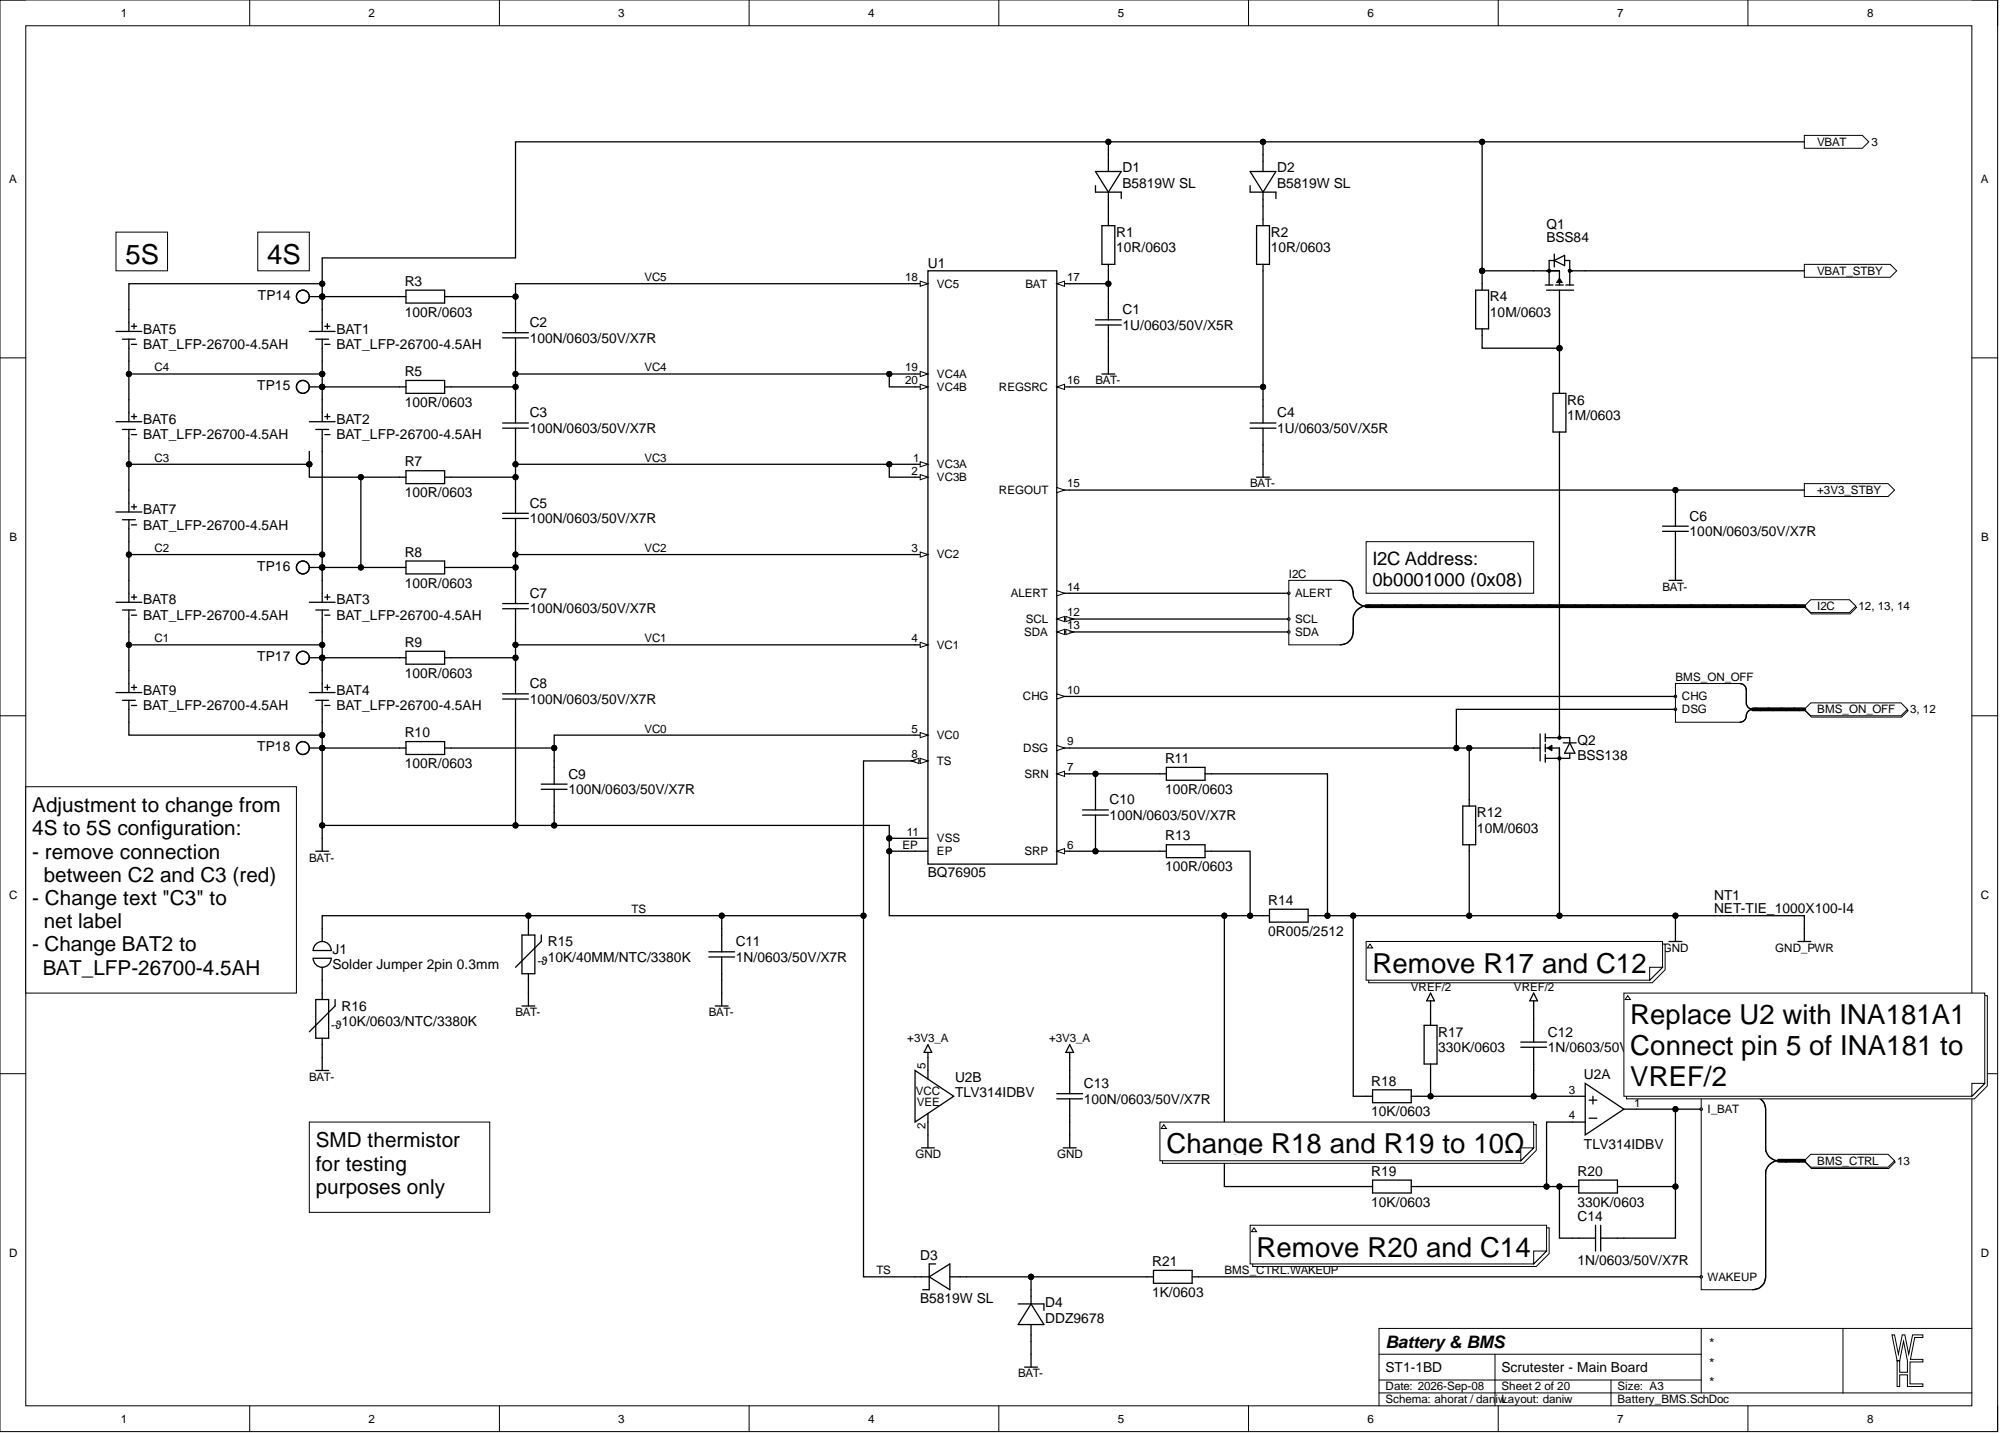
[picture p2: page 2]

Adjustment to change from
4S to 5S configuration:
- remove connection
between C2 and C3 (red)
- Change text "C3" to
net label
- Change BAT2 to

Replace U2 with INA181A1
Connect pin 5 of INA181 to
VREF/2

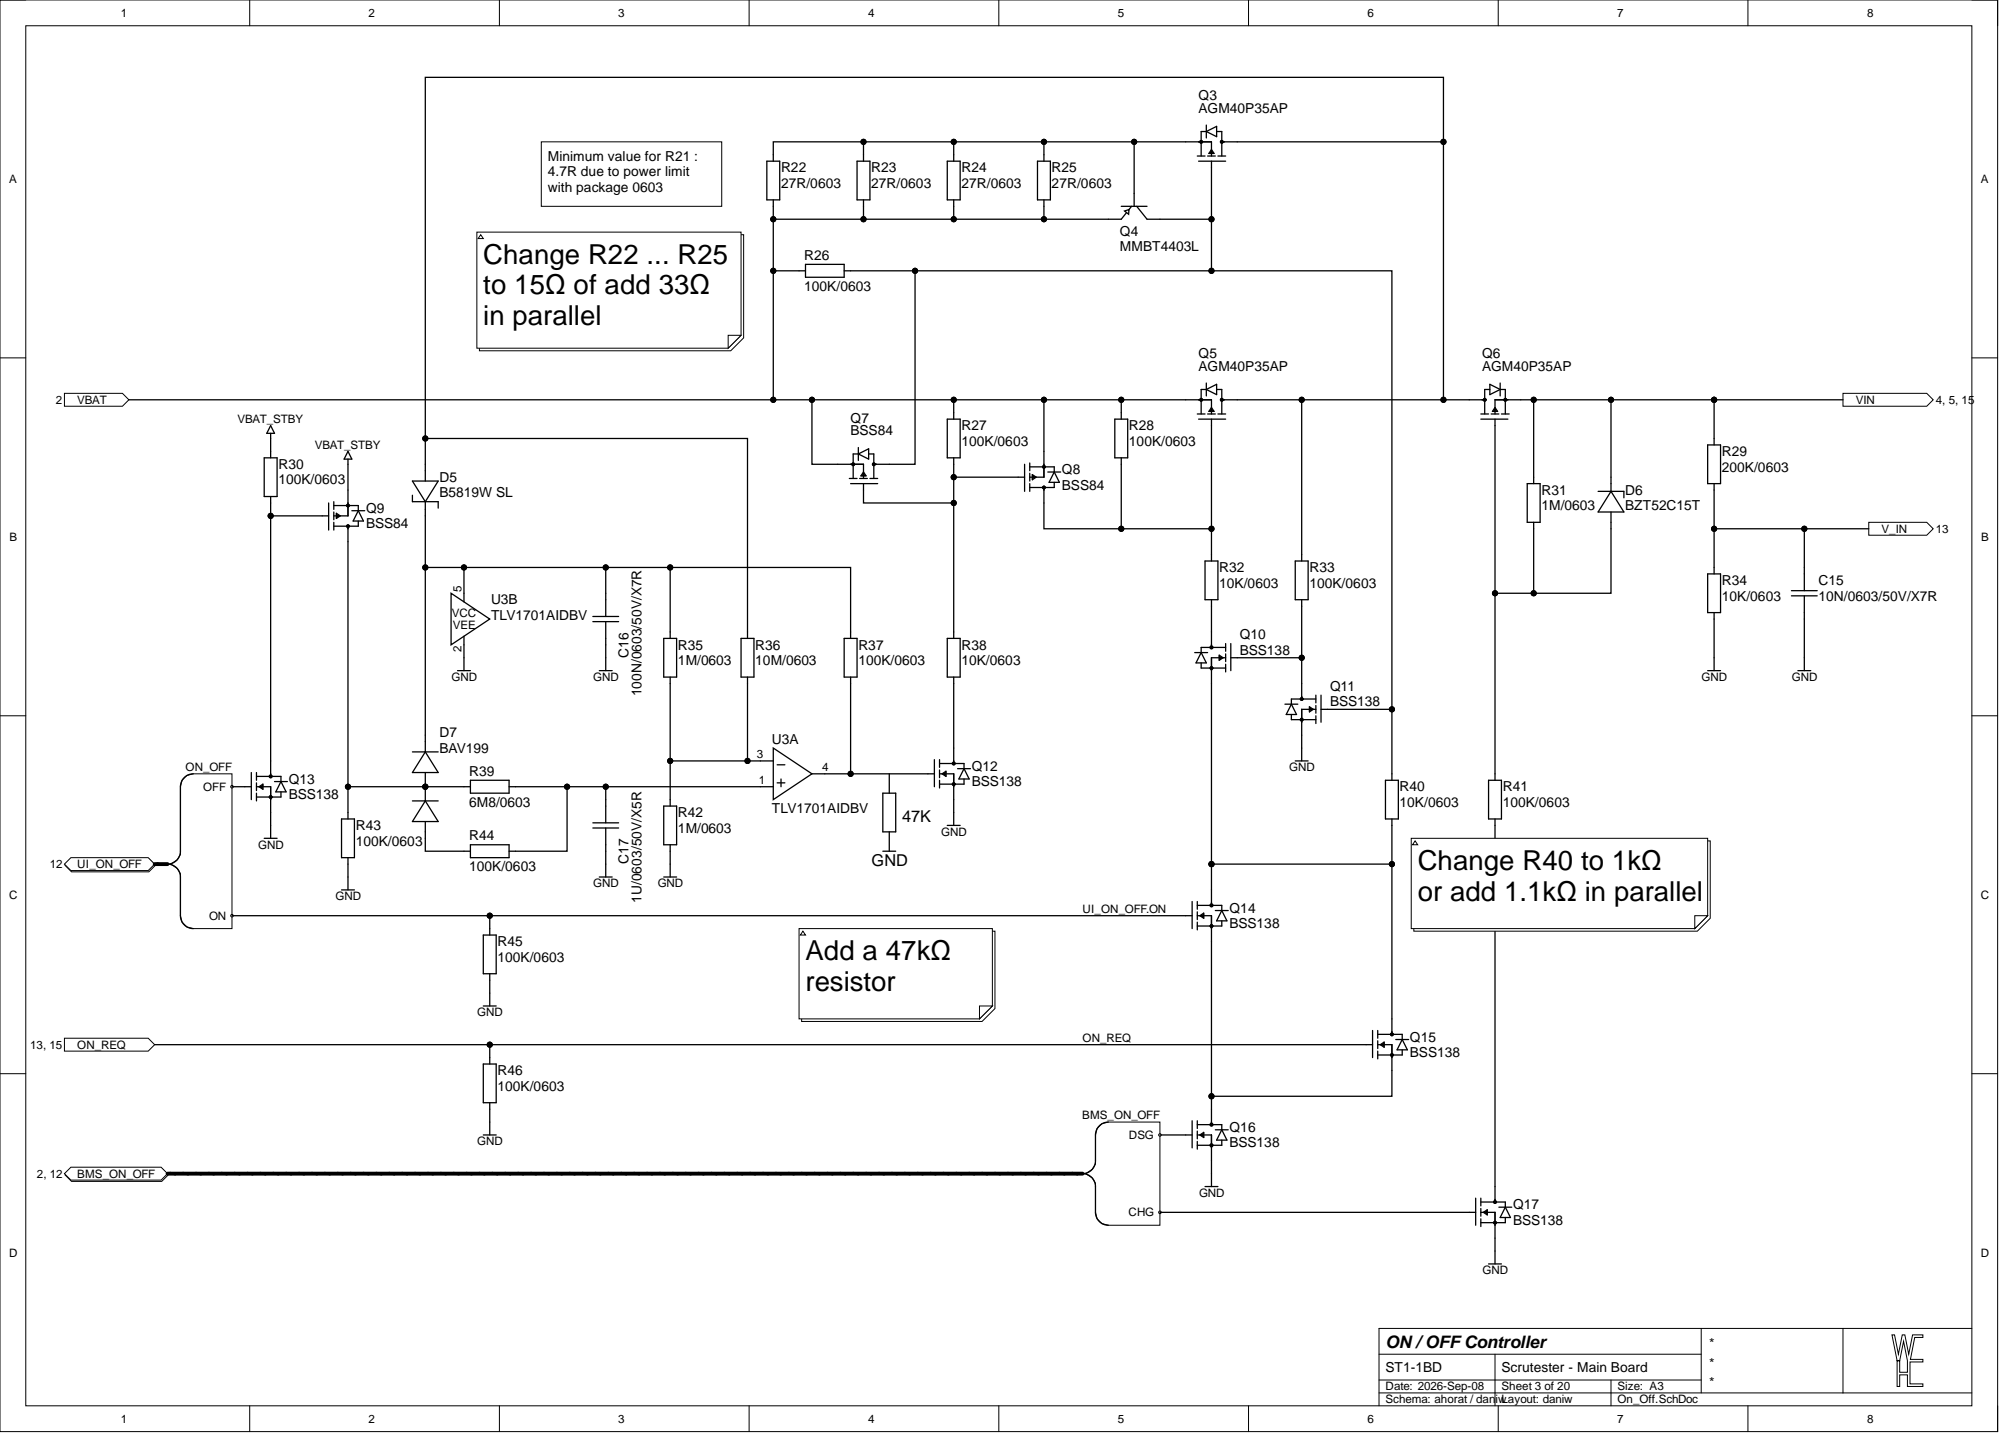
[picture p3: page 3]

Minimum value for R21 :
4.7R due to power limit
with package 0603

VEE2 VCC5

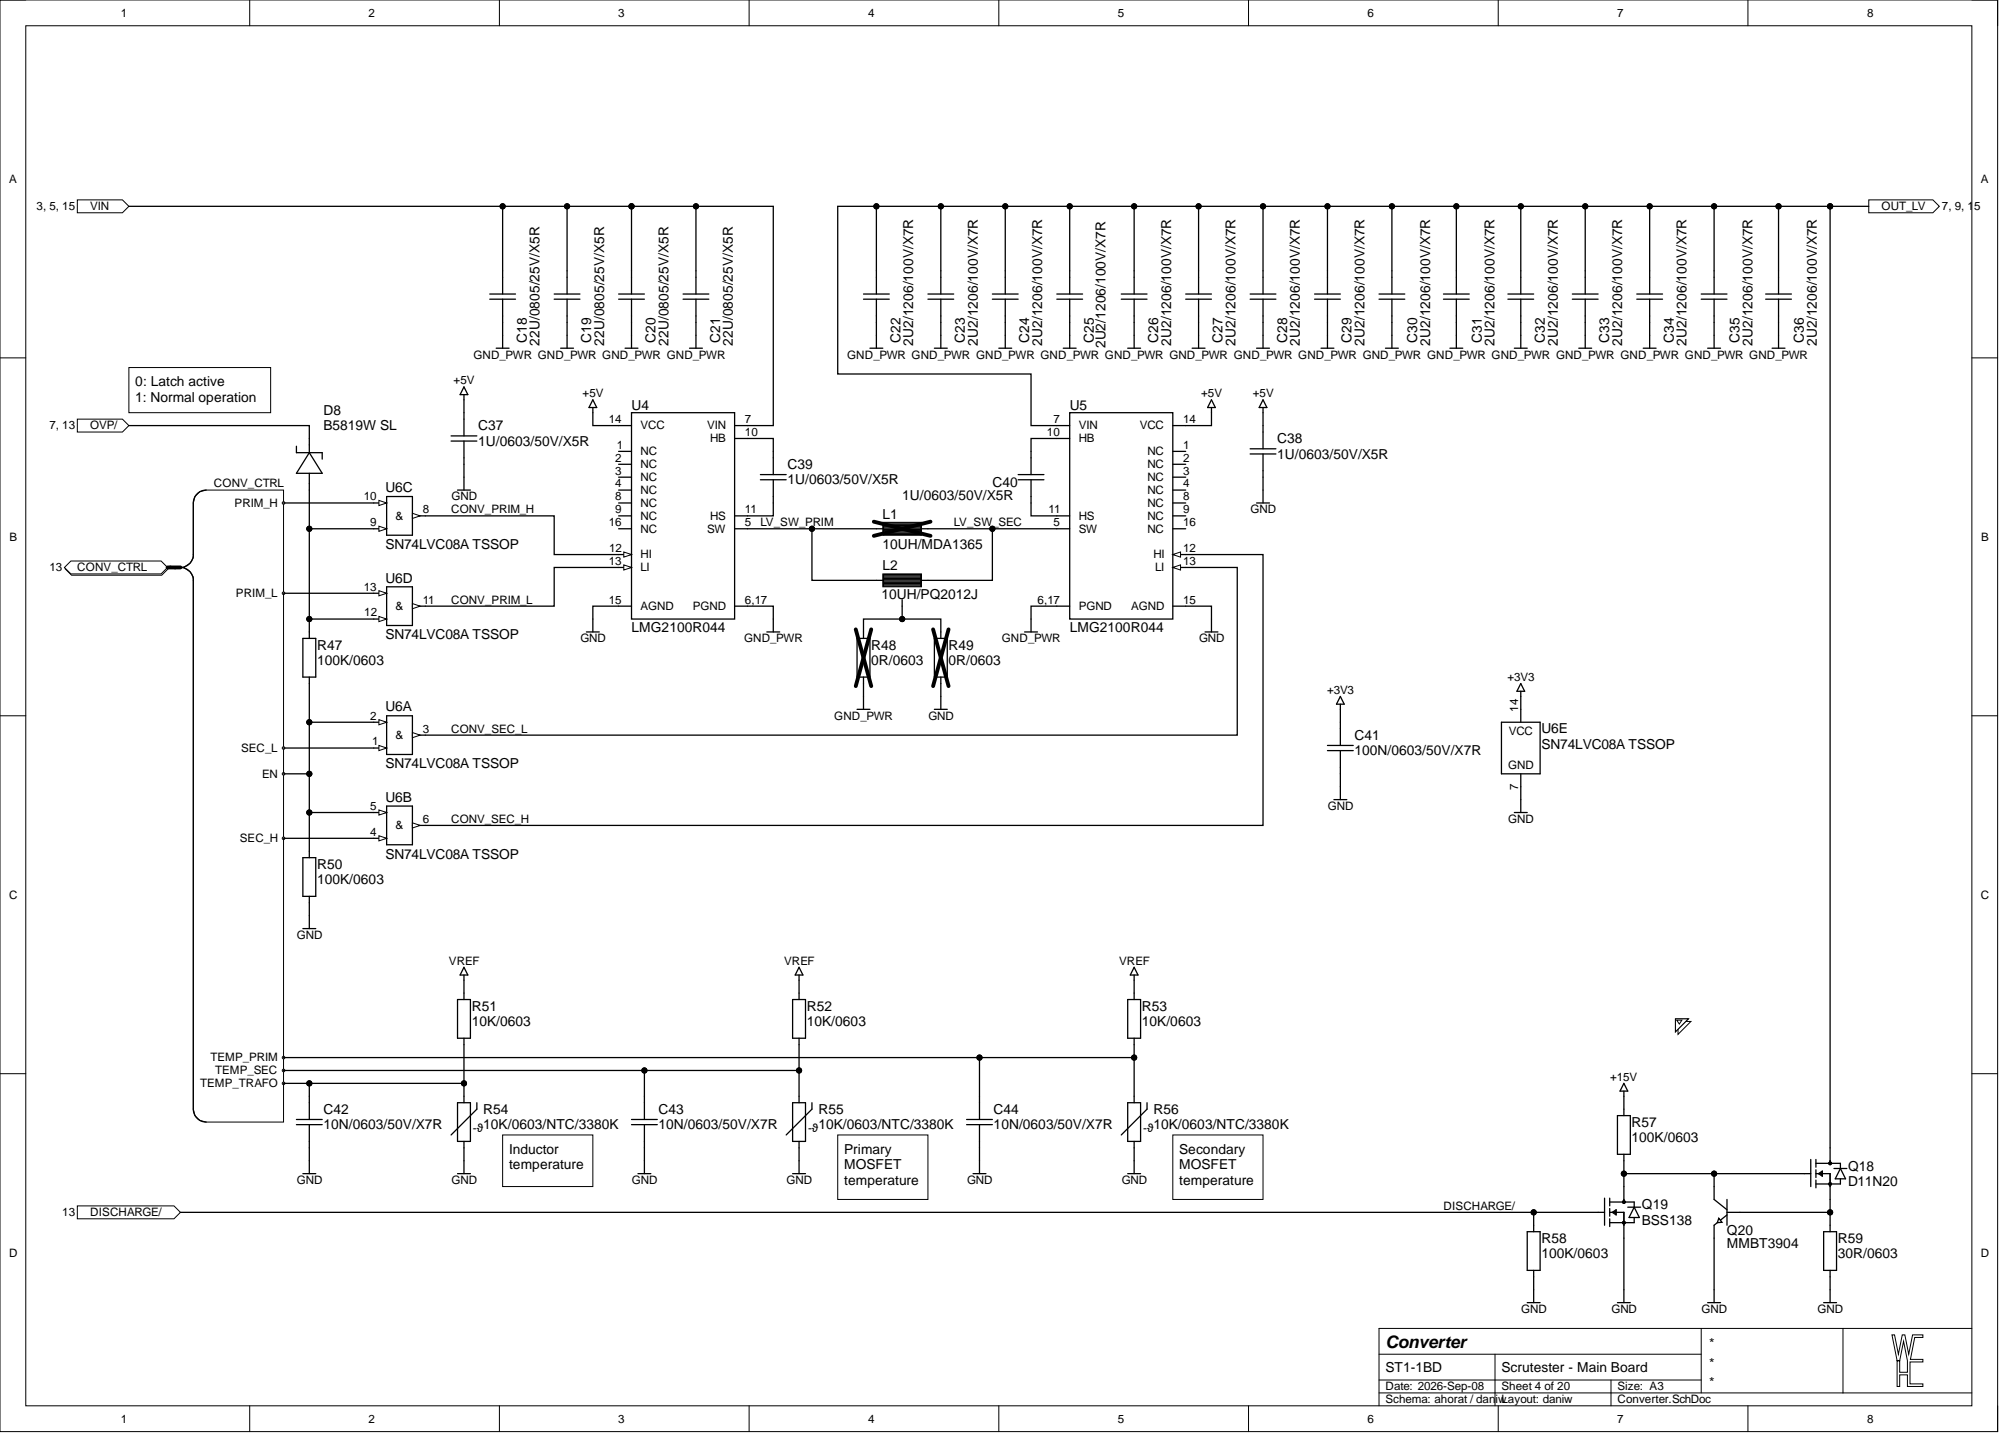
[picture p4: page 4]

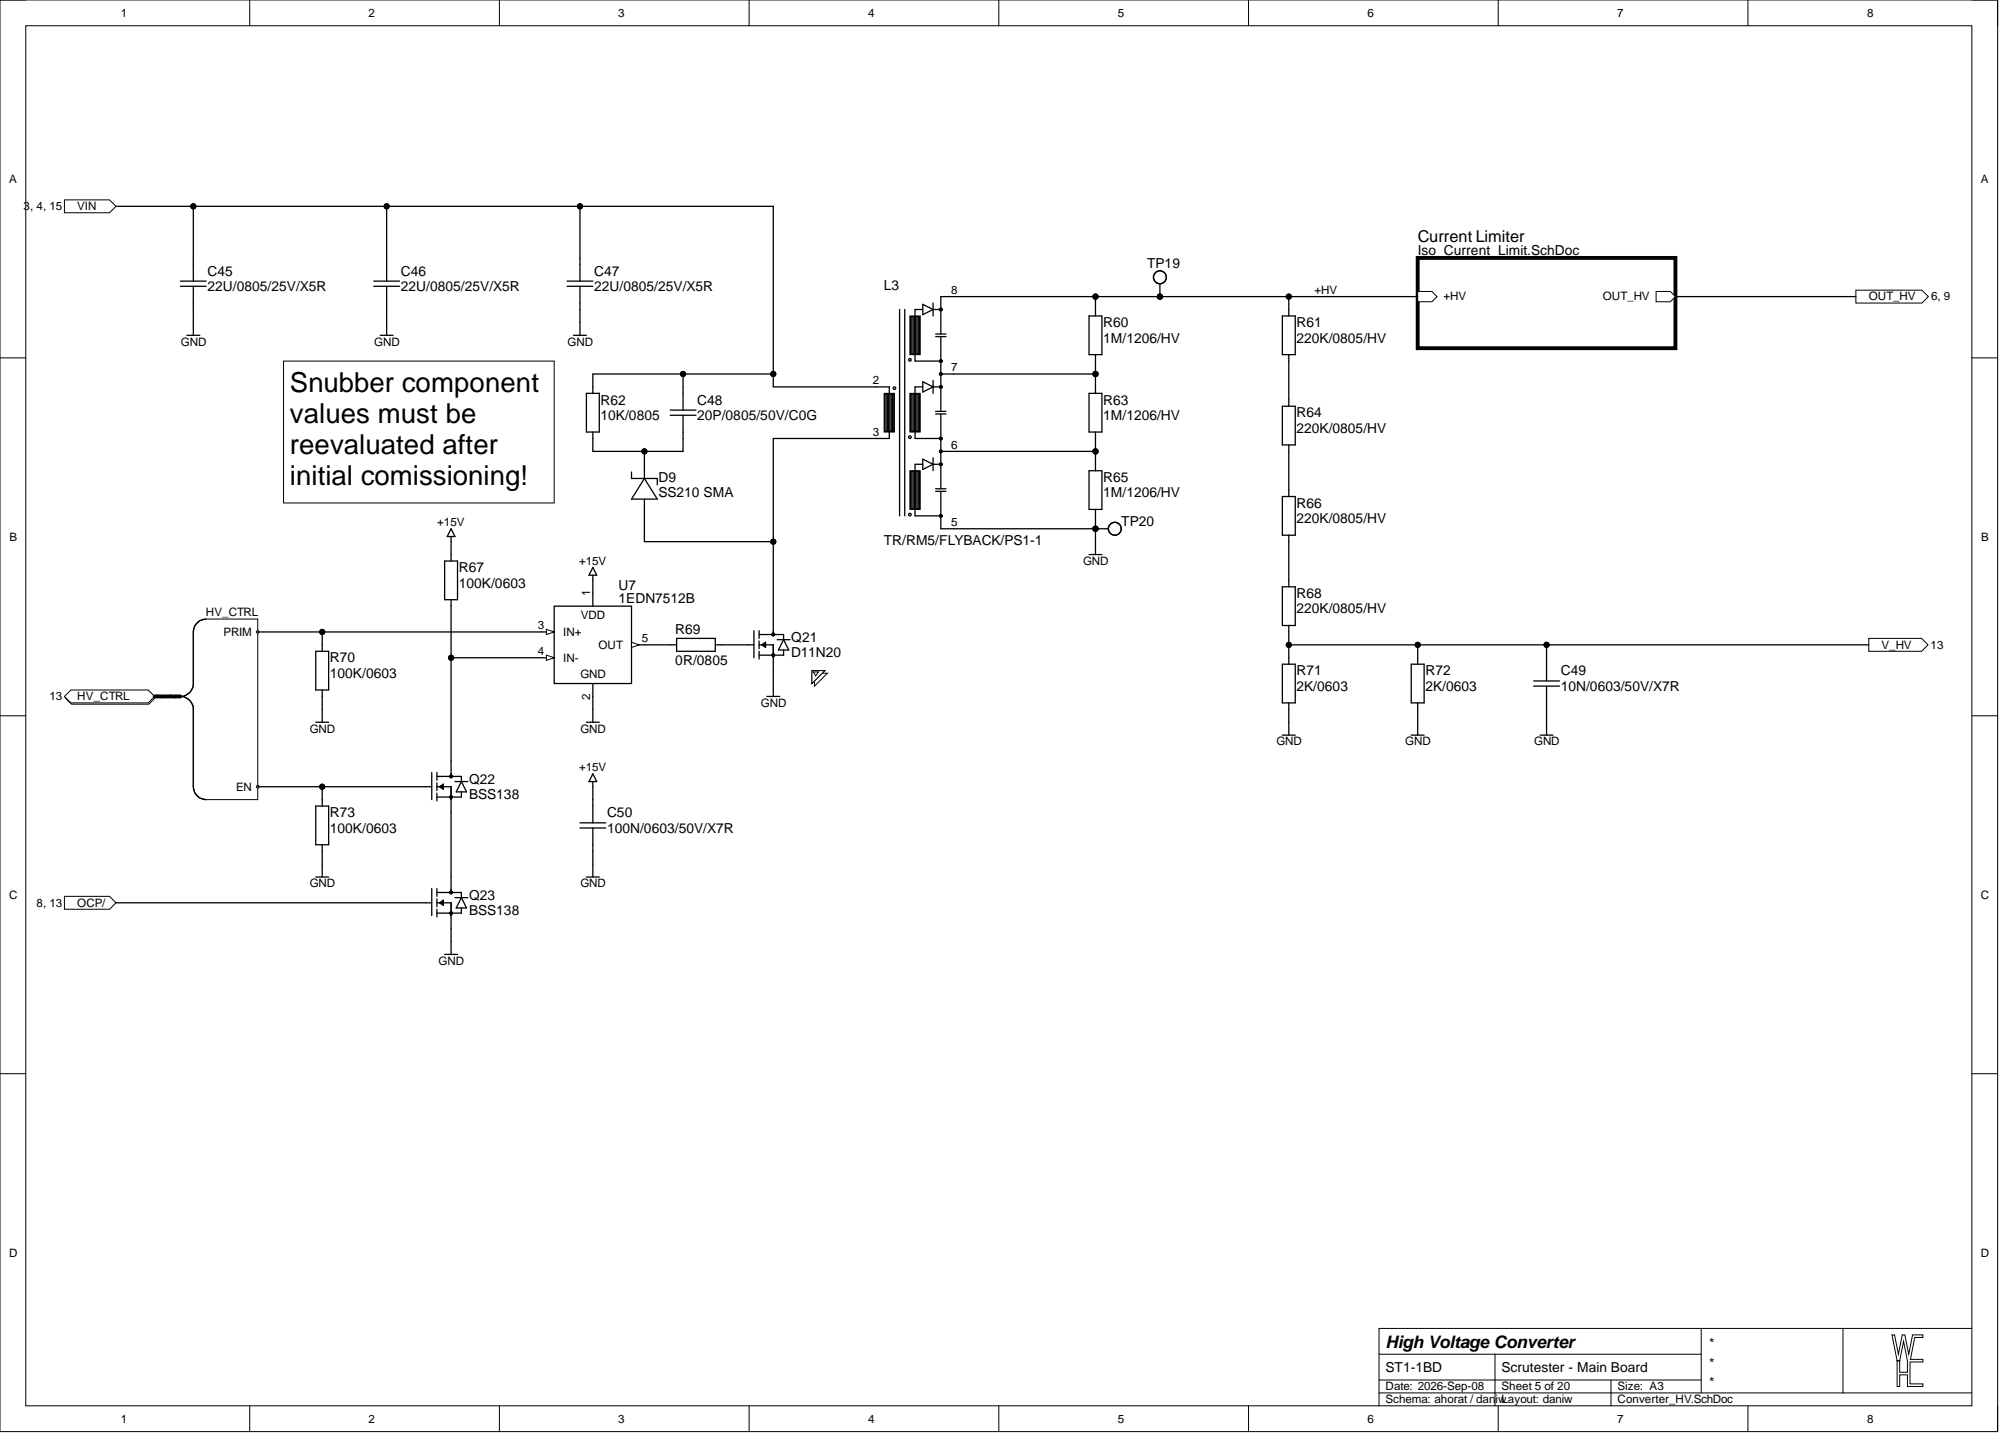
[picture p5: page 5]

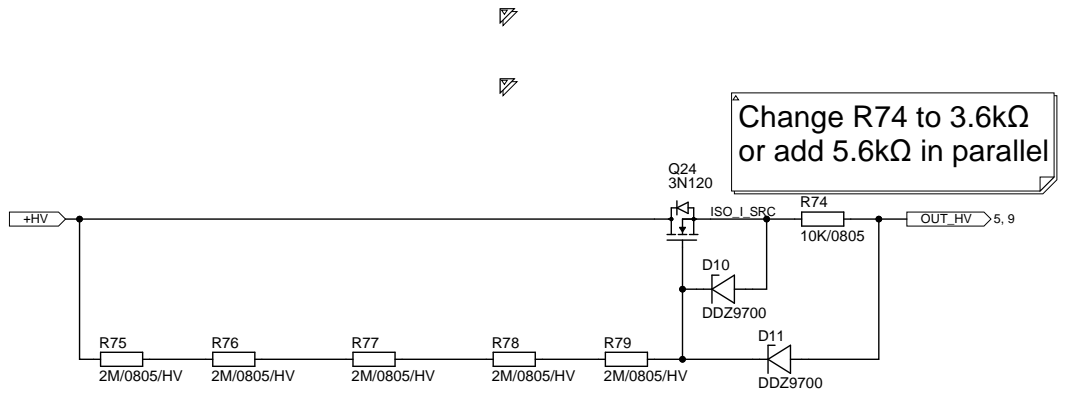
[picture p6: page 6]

Change R74 to 3.6kΩ
or add 5.6kΩ in parallel

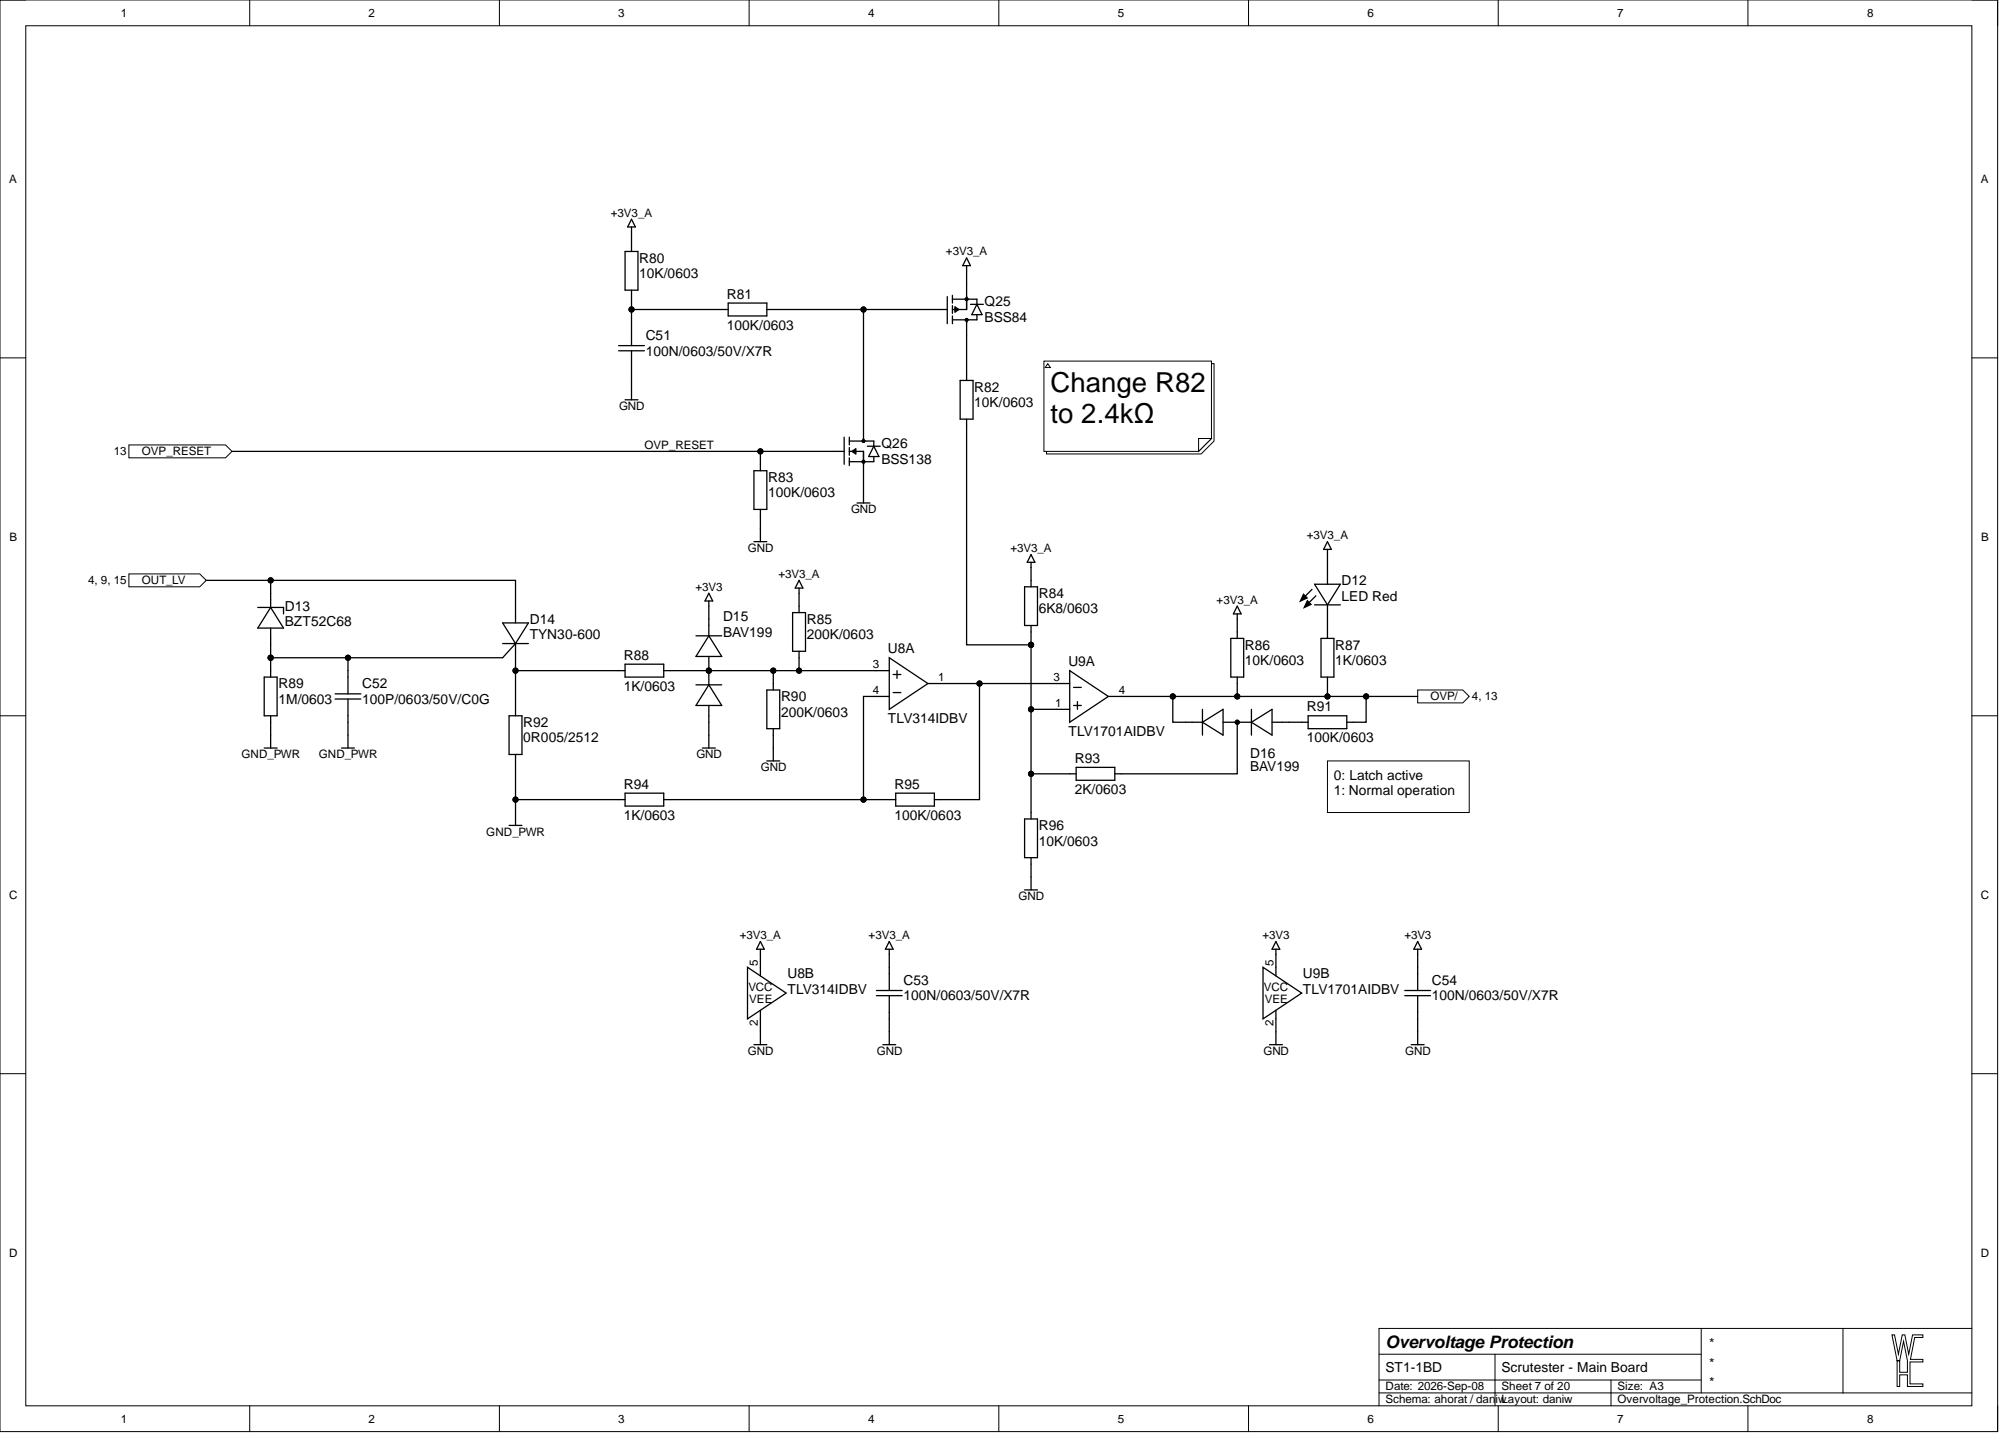
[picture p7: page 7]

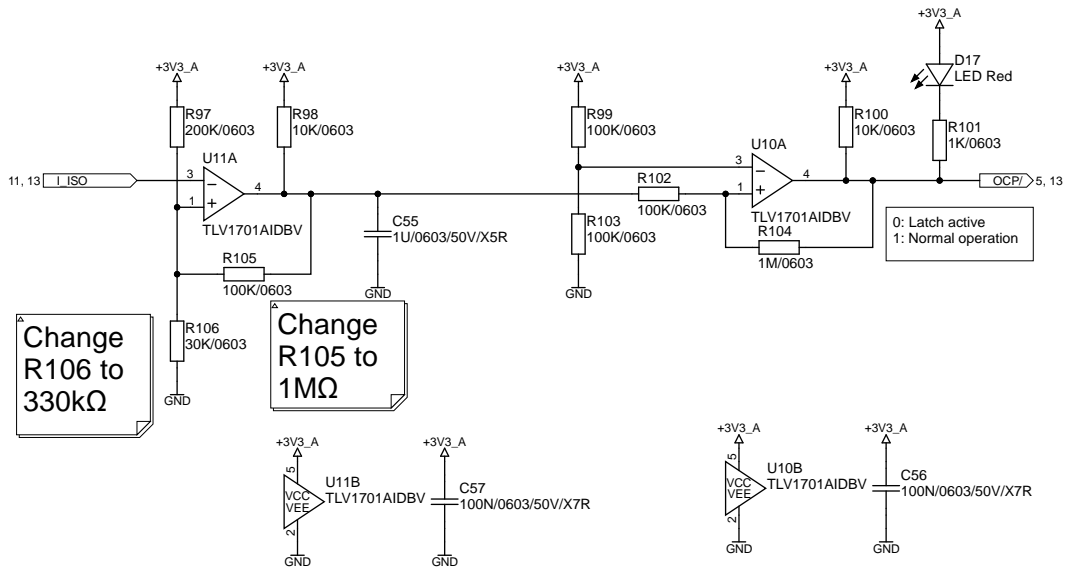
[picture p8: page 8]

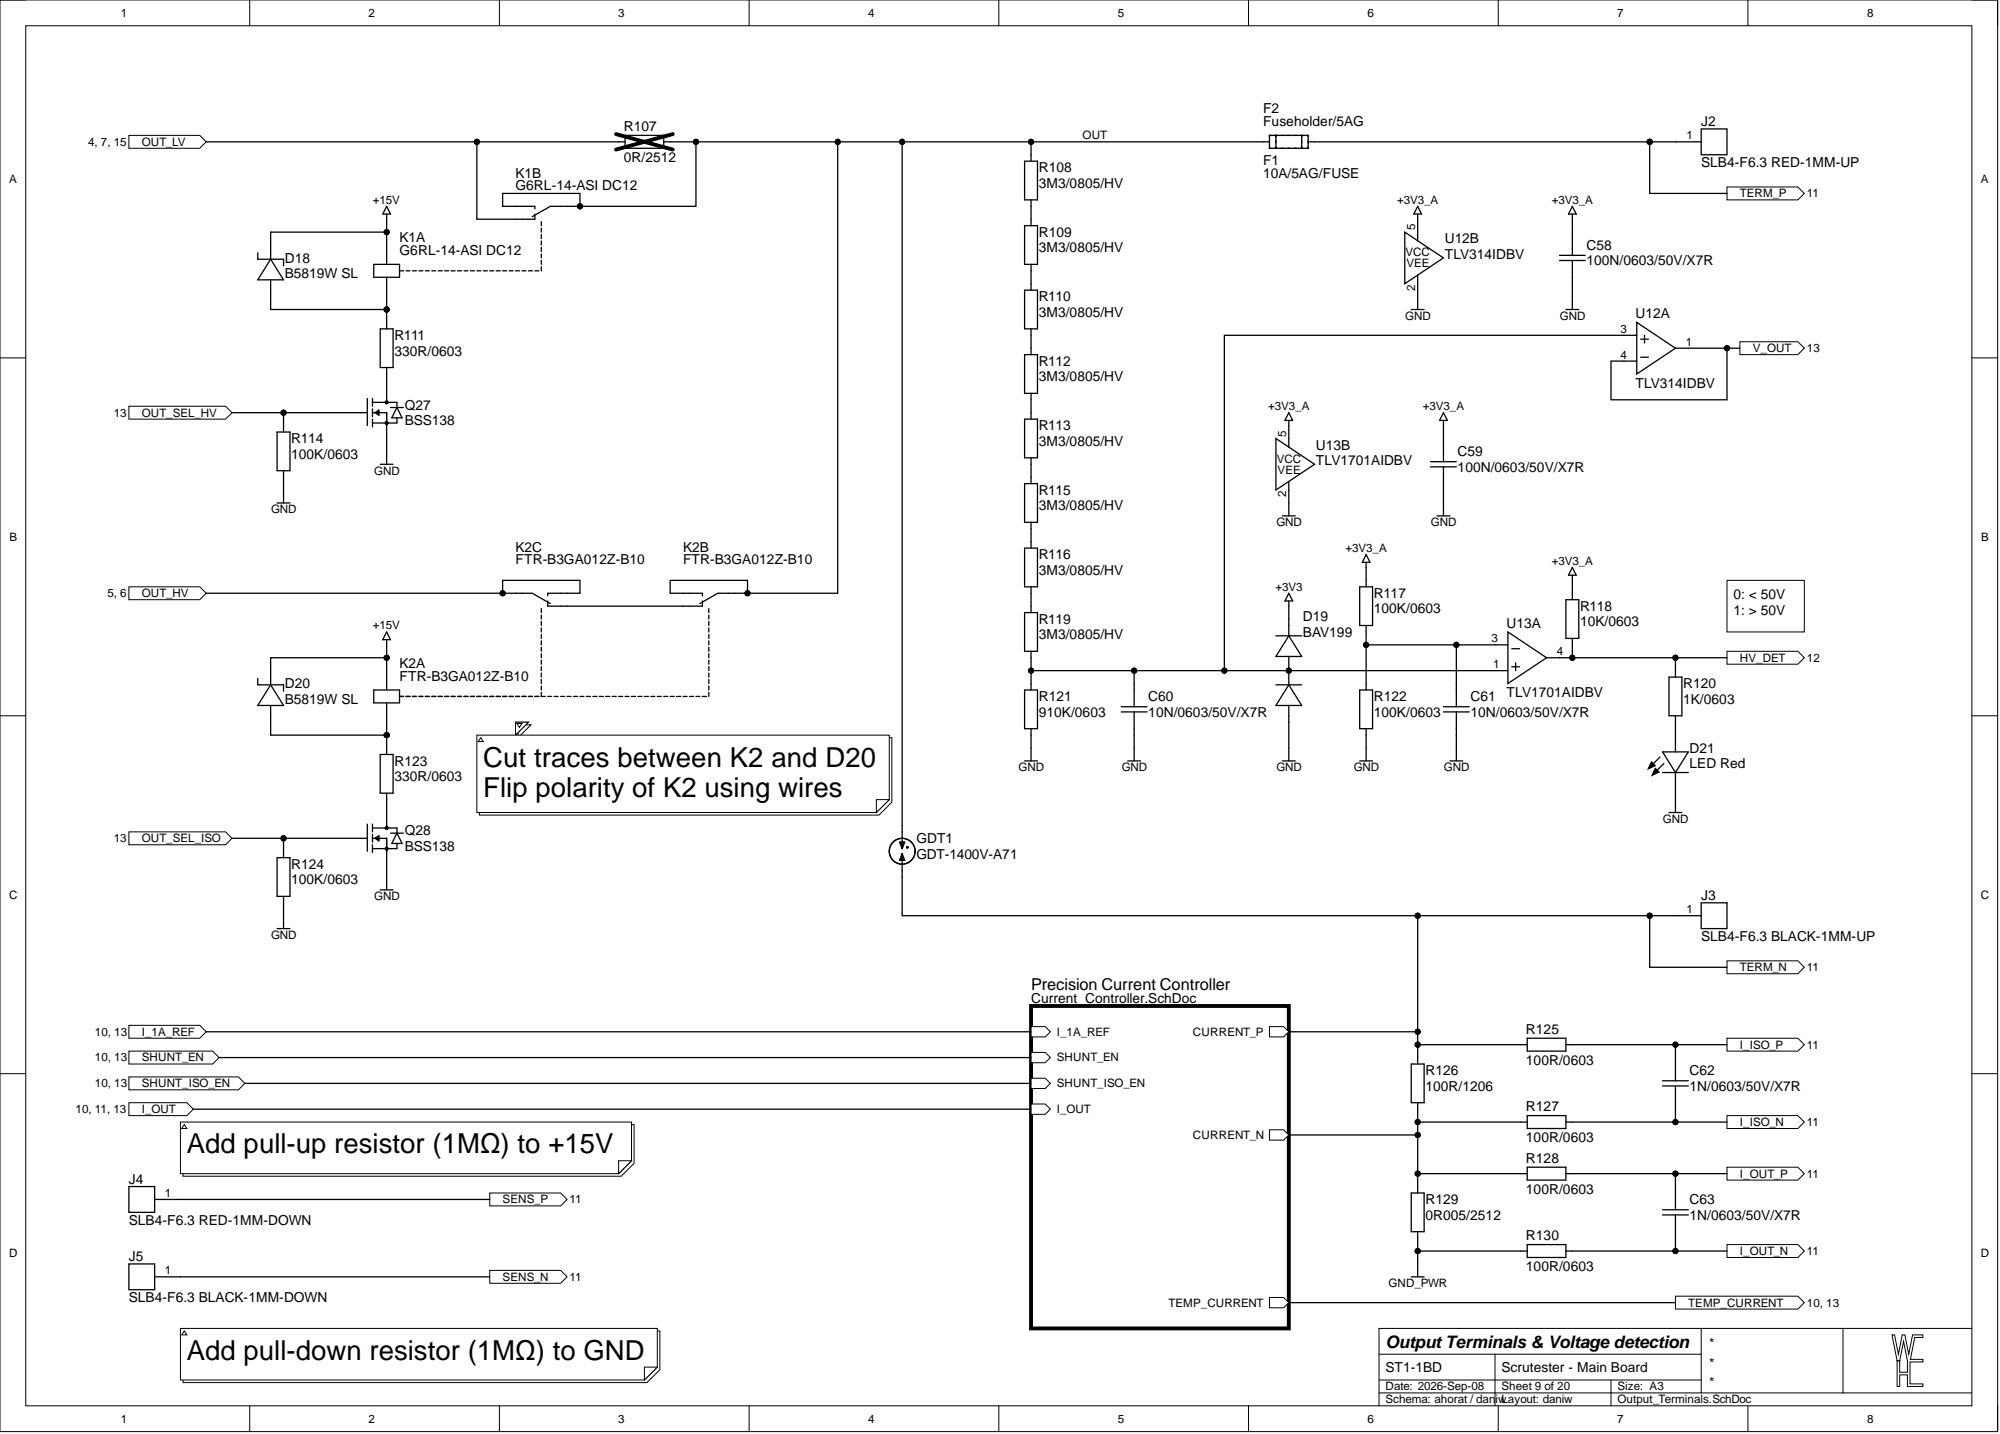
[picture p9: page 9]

Cut traces between K2 and D20
Flip polarity of K2 using wires

F6.3 BLACK
Add pull-down resistor (1M

Outp
ut Terminals & Voltage detectio

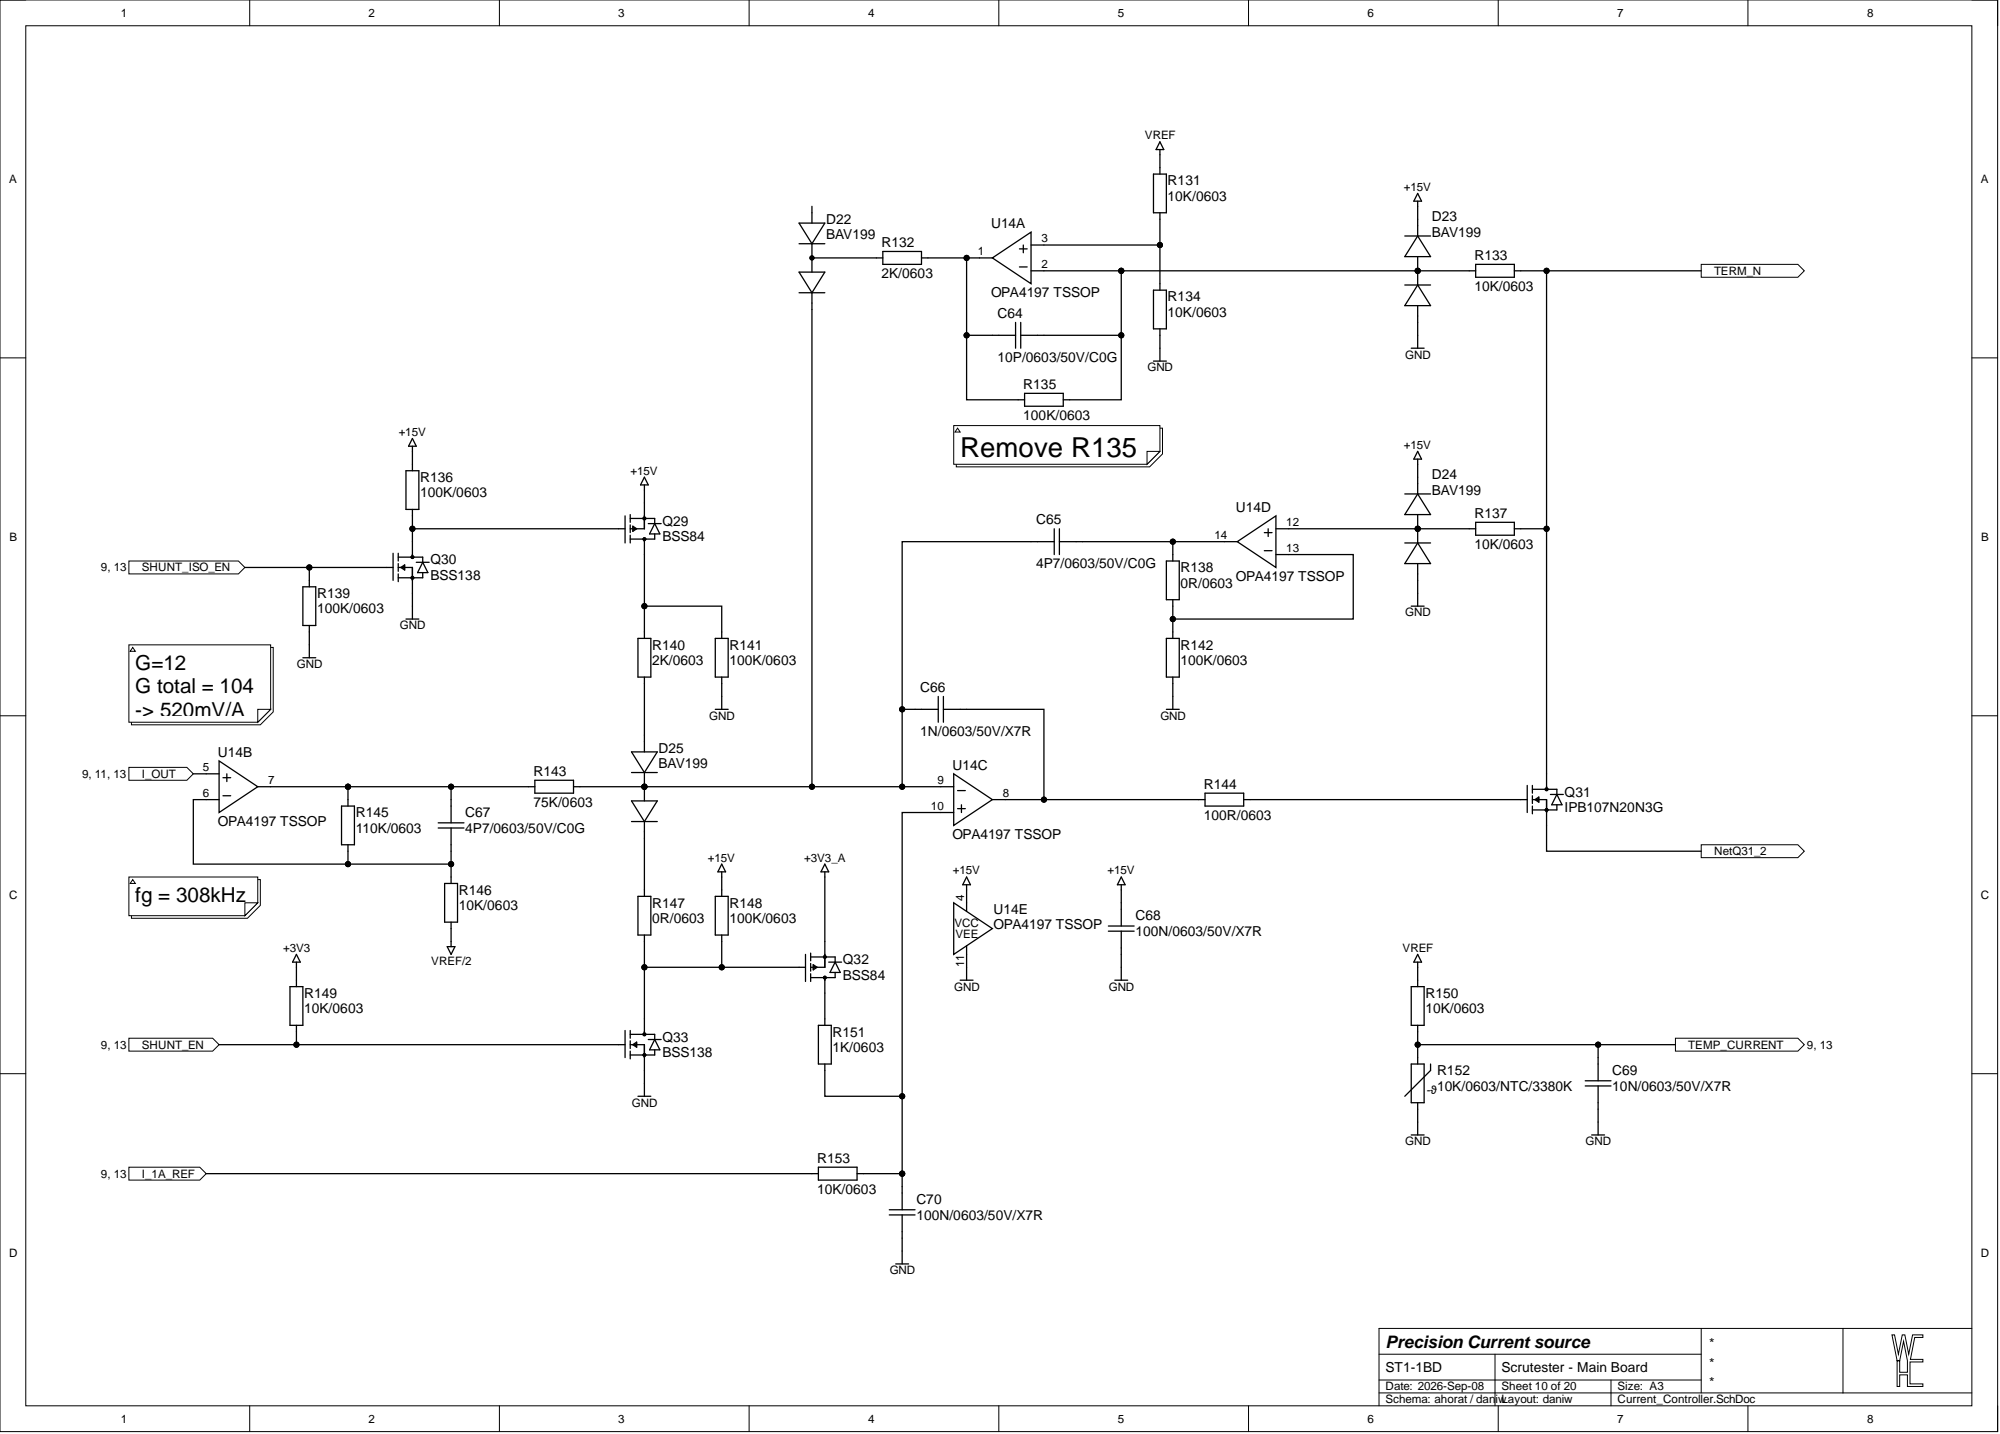
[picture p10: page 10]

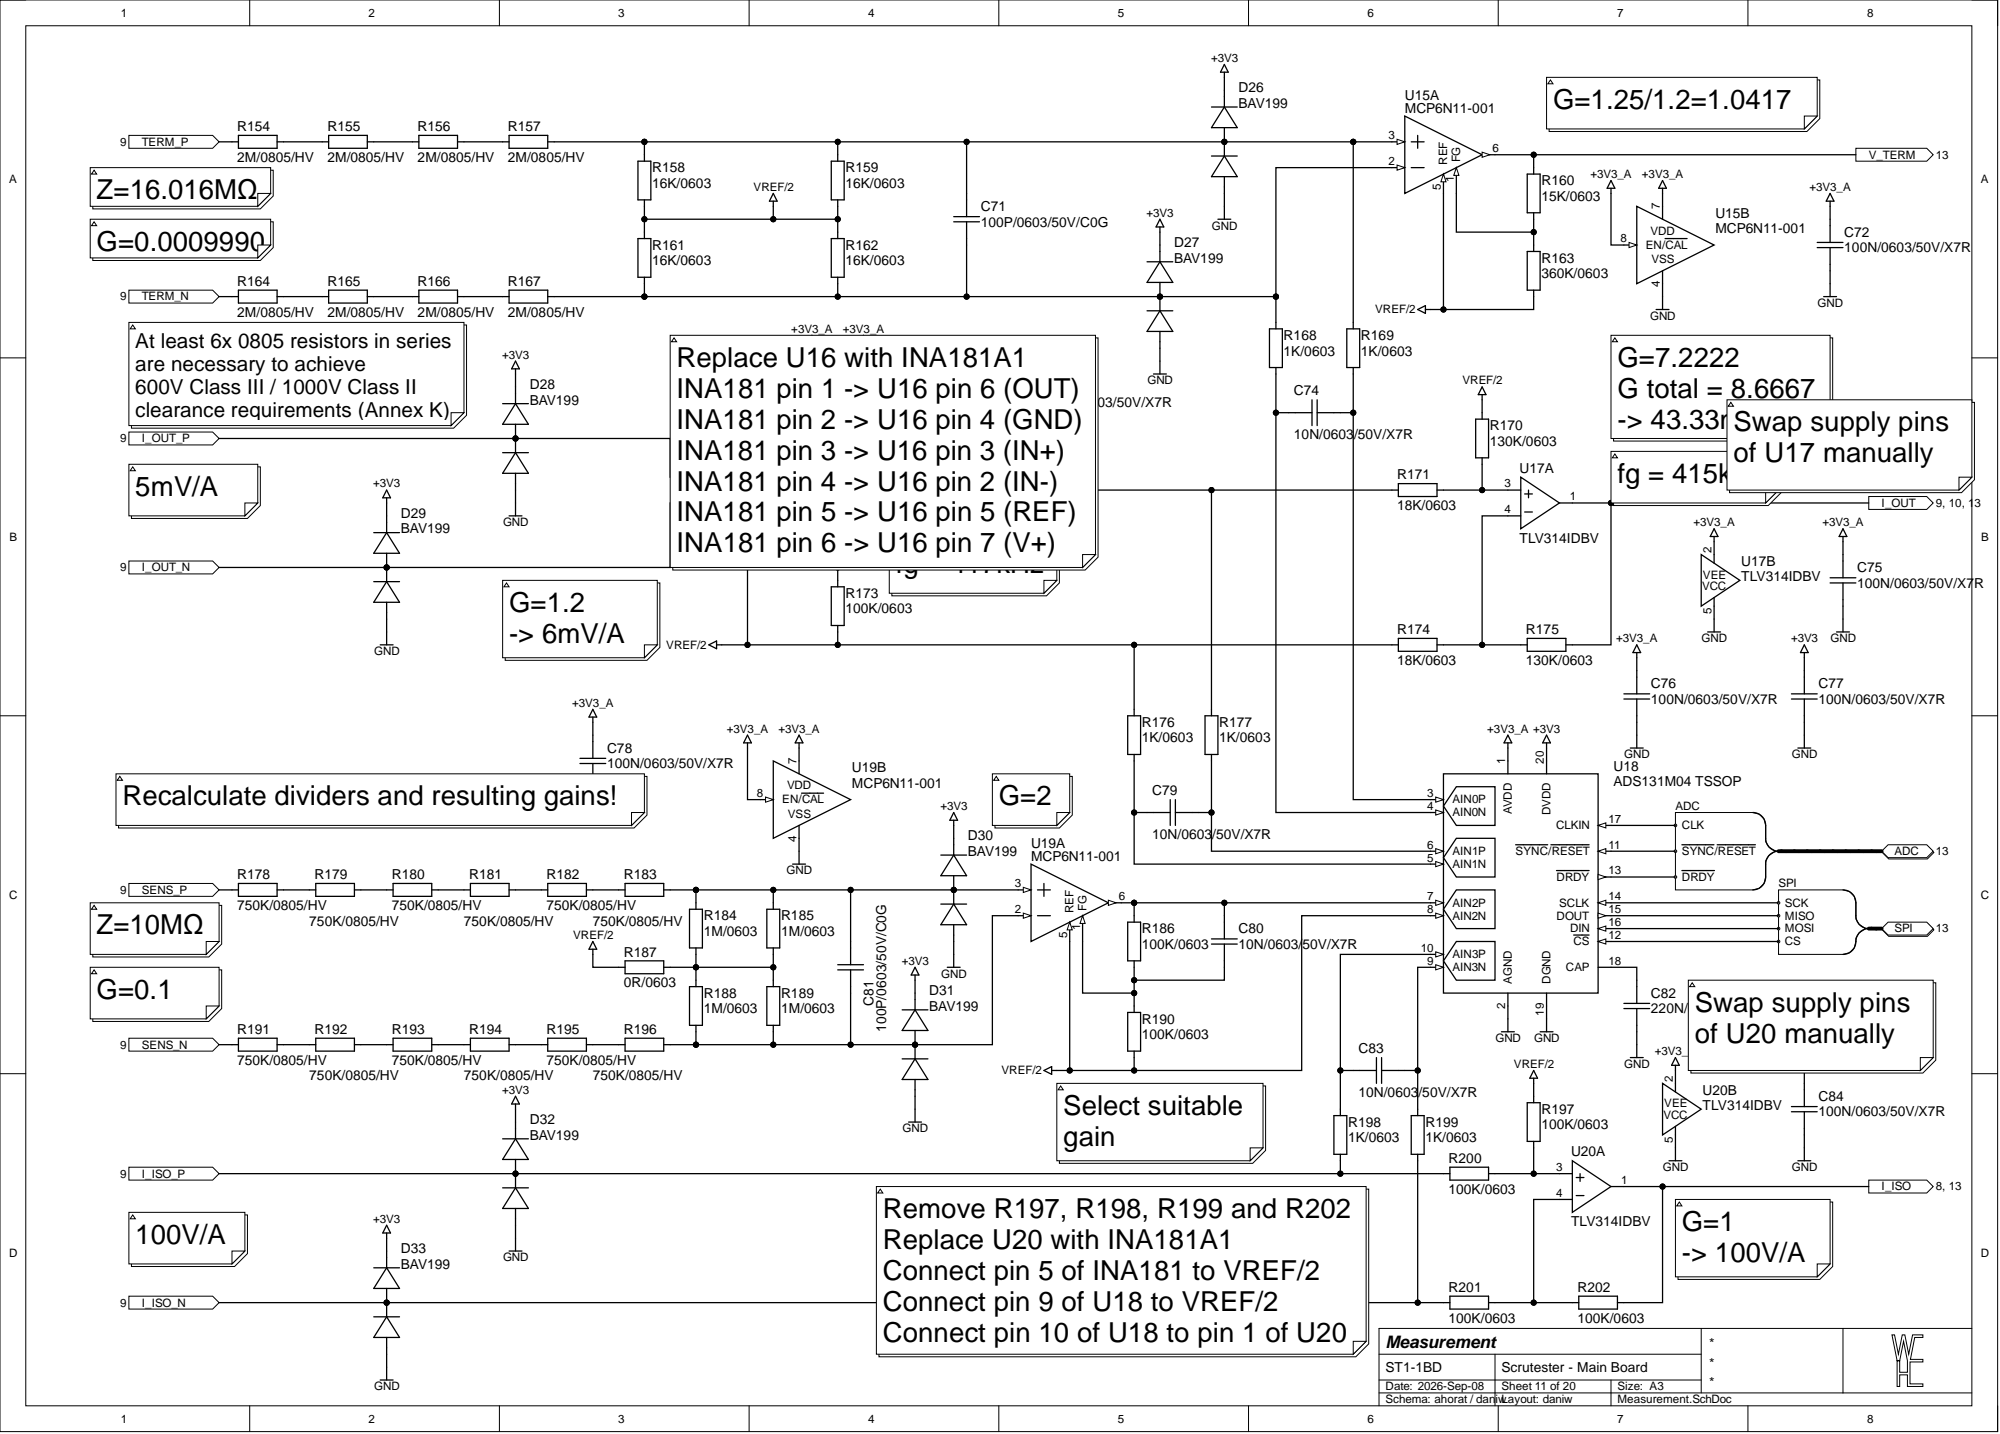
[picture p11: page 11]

At least 6x 0805 resistors in series
are necessary to achieve
600V Class III / 1000V Class II
clearance requirements (Annex K)

Remove R197, R198, R199 and R202
Replace U20 with INA181A1
Connect pin 5 of INA181 to VREF/2
Connect pin 9 of U18 to VREF/2
Connect pin 10 of U18 to pin 1 of U20

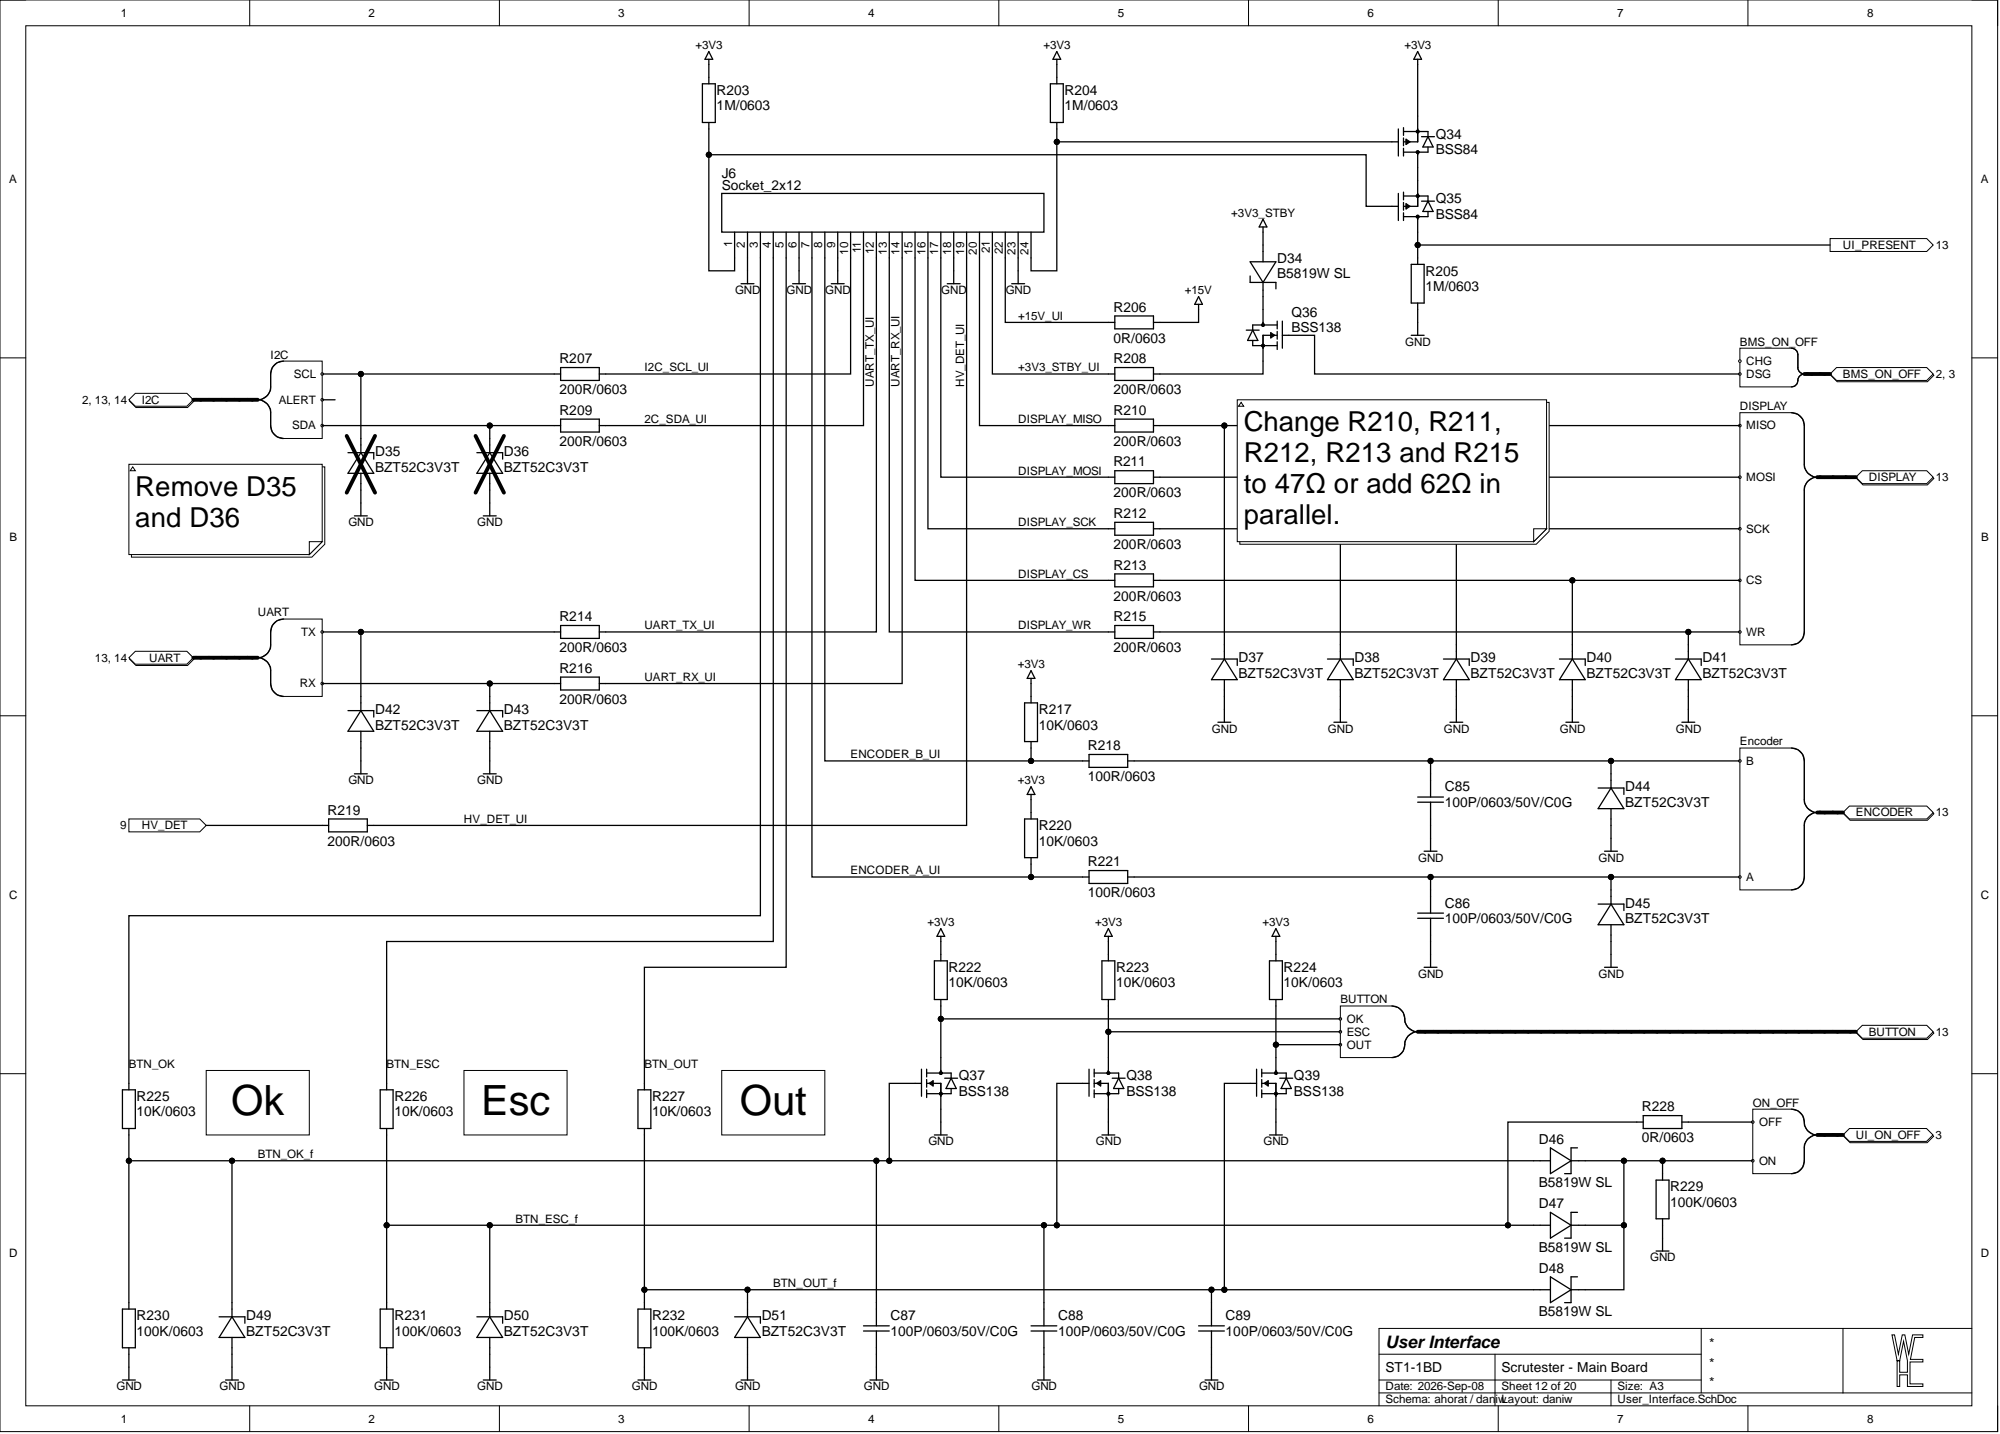
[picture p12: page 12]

R207 | | I2C_SCL_UI

2C_SDA_UI | | | | DISPLAY_MISO

Change R210, R211,
R212, R213 and R215
to 47Ω or add 62Ω in

UART_TX_UI | | | DISPLAY_MOSI

DISPLAY_SCK | | | parallel.

DISPLAY_CS

DISPLAY_WR

UART_RX_UI | | | | | +3V3

ENCODER_B_UI


Crystal 32.768 kHz HC-49/US


8 | UART.TX
9 | BOOT0
10 | RESET/







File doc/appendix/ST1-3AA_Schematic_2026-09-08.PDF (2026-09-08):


UART Netze sind benannt entsprechend
bat_source. Die Kreuzung geschieht im Stecker
zum Programmer.

Muss auf Gegenseite bestückt werden!

Header_1x2

Header_2x7


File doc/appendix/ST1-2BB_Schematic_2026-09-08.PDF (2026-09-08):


2026-Sep-08
Schema: ahorat / daniwLayout: daniw



Schema: ahorat / daniwLayout: daniw




Schema: ahorat / daniwLayout: daniw




Adding additional transformers
be necessary due to isolation
requirements

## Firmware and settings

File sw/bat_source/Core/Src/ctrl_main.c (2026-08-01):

/*
 * ctrl_main.c
 *
 *  Created on: Jul 30, 2025
 *      Author: ahorat
 */

#include "ctrl_main.h"
#include "ctrl_param.h"
#include "ctrl_PID_control.h"
#include "adc.h"
#include "hrtim.h"
#include <stdio.h>
#include "aux_io_ctrl.h"
#include "config_store.h"
#include "bq76905.h"
#include "mode_table.h"

extern BQ76905_handle bms;

ctrl_main_t ctrl_main_handle;
PID_controller_t ctrl_pi_voltage_buck;
PID_controller_t ctrl_pi_voltage_boost;
PID_controller_t ctrl_pi_current;
PID_controller_t ctrl_pi_boost_iout_limit;
PID_controller_t ctrl_pi_charge_current;
PID_controller_t ctrl_pi_charge_voltage;
PID_controller_t ctrl_pi_voltage_hv;
PID_controller_t ctrl_pi_hv_iout_limit;

const uint16_t ctrl_main_iso_values[4] = { 125, 250, 500, 1000 };

// CLI setPI IDs are positional: 0=Buck,1=Boost,2=Current,3=BoostIoutLimit,4=ChargeCurrent.
const ctrl_pid_entry_t ctrl_pid_table[CTRL_PID_TABLE_LEN] = {
	{ &ctrl_pi_voltage_buck,     &config_store.calibration.voltage_buck_p,     &config_store.calibration.voltage_buck_i,
	  CTRL_PARAM_VOLTAGE_BUCK_P,       CTRL_PARAM_VOLTAGE_BUCK_I,
	  CTRL_PARAM_VOLTAGE_BUCK_DUTY_SAT_HIGH,  CTRL_PARAM_VOLTAGE_BUCK_DUTY_SAT_LOW,  "Buck" },
	{ &ctrl_pi_voltage_boost,    &config_store.calibration.voltage_boost_p,    &config_store.calibration.voltage_boost_i,
	  CTRL_PARAM_VOLTAGE_BOOST_P,      CTRL_PARAM_VOLTAGE_BOOST_I,
	  CTRL_PARAM_VOLTAGE_BOOST_DUTY_SAT_HIGH, CTRL_PARAM_VOLTAGE_BOOST_DUTY_SAT_LOW, "Boost" },
	{ &ctrl_pi_current,          &config_store.calibration.current_p,          &config_store.calibration.current_i,
	  CTRL_PARAM_CURRENT_P,            CTRL_PARAM_CURRENT_I,
	  CTRL_PARAM_CURRENT_DUTY_SAT_HIGH,       CTRL_PARAM_CURRENT_DUTY_SAT_LOW,       "Current" },
	{ &ctrl_pi_boost_iout_limit, &config_store.calibration.boost_iout_limit_p, &config_store.calibration.boost_iout_limit_i,
	  CTRL_PARAM_BOOST_IOUT_LIMIT_P,   CTRL_PARAM_BOOST_IOUT_LIMIT_I,
	  CTRL_PARAM_VOLTAGE_BOOST_DUTY_SAT_HIGH, CTRL_PARAM_VOLTAGE_BOOST_DUTY_SAT_LOW, "BoostIoutLimit" },
	{ &ctrl_pi_charge_current,   &config_store.calibration.charge_current_p,   &config_store.calibration.charge_current_i,
	  CTRL_PARAM_CHARGE_CURRENT_P,     CTRL_PARAM_CHARGE_CURRENT_I,
	  CTRL_PARAM_CHARGE_CURRENT_DUTY_SAT_HIGH, CTRL_PARAM_CHARGE_CURRENT_DUTY_SAT_LOW, "ChargeCurrent" },
	{ &ctrl_pi_charge_voltage,   &config_store.calibration.charge_voltage_p,   &config_store.calibration.charge_voltage_i,
	  CTRL_PARAM_CHARGE_VOLTAGE_P,     CTRL_PARAM_CHARGE_VOLTAGE_I,
	  CTRL_PARAM_CHARGE_VOLTAGE_DUTY_SAT_HIGH, CTRL_PARAM_CHARGE_VOLTAGE_DUTY_SAT_LOW, "ChargeVoltage" },
	{ &ctrl_pi_voltage_hv,   &config_store.calibration.voltage_hv_p,   &config_store.calibration.voltage_hv_i,
	  CTRL_PARAM_HV_VOLTAGE_P,     CTRL_PARAM_HV_VOLTAGE_I,
	  CTRL_PARAM_HV_VOLTAGE_DUTY_SAT_HIGH, CTRL_PARAM_HV_VOLTAGE_DUTY_SAT_LOW, "HVVoltage" },
	{ &ctrl_pi_hv_iout_limit,   &config_store.calibration.flyback_current_p,   &config_store.calibration.flyback_current_i,
	  CTRL_PARAM_HV_CURRENT_P,     CTRL_PARAM_HV_CURRENT_I,
	  CTRL_PARAM_HV_VOLTAGE_DUTY_SAT_HIGH, CTRL_PARAM_HV_VOLTAGE_DUTY_SAT_LOW, "HVCurrent" },
};

/******************* Function Prototypes **************************/
void ctrl_main_ctrl_voltage_buck(uint32_t voltage_meas_mV,
		int32_t voltage_meas_accurate);
void ctrl_main_ctrl_voltage_boost(uint32_t voltage_meas_mV,
		int32_t voltage_meas_accurate, int32_t current_meas_ext_mA);
void ctrl_main_ctrl_current(int16_t current_meas_mA,
		int16_t current_meas_accurate);
void ctrl_main_ctrl_charge_current(int16_t current_meas_mA,
		int16_t current_meas_accurate);
void ctrl_main_ctrl_charge_voltage(uint32_t voltage_meas_mV,
		int32_t voltage_meas_accurate_mV);
void ctrl_main_ctrl_voltage_hv(uint32_t voltage_meas_mV,
		int32_t voltage_meas_accurate_mV, int32_t current_meas_iso_uA);

/**
 * Initializes the controllers
 */
void ctrl_main_init(void) {

	// P/I gains come from config_store, which is loaded from EEPROM (or
	// defaulted to the CTRL_PARAM_* constants) before ctrl_main_init() runs -
	// see config_store_init() in main(). Duty saturation limits stay as
	// hardcoded safety limits rather than field-tunable values.
	for (int i = 0; i < CTRL_PID_TABLE_LEN; i++) {
		const ctrl_pid_entry_t *e = &ctrl_pid_table[i];
		ctrl_PID_controller_init(e->ctrl, *e->cal_p, *e->cal_i, 0, e->sat_high, e->sat_low);
	}

	ctrl_pi_boost_iout_limit.ref = CTRL_PARAM_BOOST_IOUT_LIMIT_mA / 1000.0F;
	ctrl_pi_hv_iout_limit.ref = CTRL_PARAM_HV_IOUT_LIMIT_mA / 1000.0F;
}

/**
 * Maps a statemachine_modes_t to its ctrl_mode_t counterpart, via a
 * mode_table[] lookup - see mode_table.h/.c. The two enums are positionally
 * identical only up through ISOMETER and diverge after that
 * (STATEMACHINE_MODE_VOLTMETER=6 vs CTRL_MODE_CHARGE=6) - callers must go
 * through this instead of passing statemachine_handle.current_mode directly
 * to ctrl_main_start_ctrl(). Modes with no ctrl_mode_t counterpart
 * (AMPMETER, VOLTMETER, SETTINGS, SHUTDOWN, IDLE) correctly map to
 * CTRL_MODE_OFF, since none of them drive the control loop.
 * @param mode statemachine mode to translate.
 * @return the matching ctrl_mode_t, or CTRL_MODE_OFF if none applies (also
 *   the out-of-range/mode >= STATEMACHINE_MODE_RESERVED fallback).
 */
ctrl_mode_t statemachine_mode_to_ctrl_mode(statemachine_modes_t mode) {
	if (mode >= STATEMACHINE_MODE_RESERVED) {
		return CTRL_MODE_OFF;
	}
	return mode_table[mode].ctrl_mode;
}

void ctrl_main_start_ctrl(ctrl_mode_t mode) {
	switch (mode) {

	case CTRL_MODE_CHARGE:
		ctrl_main_apply_reference(mode, 0);
		ctrl_PID_reset(&ctrl_pi_voltage_buck);
		ctrl_PID_reset(&ctrl_pi_charge_current);
		ctrl_PID_reset(&ctrl_pi_charge_voltage);
		ctrl_main_handle.charge_cv_phase = 0;
		// Preload for smoother turn on
		ctrl_pi_charge_current.prev_I_action = CTRL_PARAM_CHARGE_CURRENT_DUTY_SAT_HIGH;
		hrtim_set_freq(HRTIM_CHANNEL_PRIM, CTRL_PARAM_SW_FREQ_LOW);
		hrtim_set_freq(HRTIM_CHANNEL_SEK, CTRL_PARAM_SW_FREQ_HIGH);
		hrtim_set_duty(HRTIM_CHANNEL_PRIM, CTRL_PARAM_CONST_DUTY_HIGH);
		hrtim_set_duty(HRTIM_CHANNEL_SEK, CTRL_PARAM_CONST_DUTY_LOW);
		hrtim_enable(HRTIM_CHANNEL_PRIM);
		hrtim_enable(HRTIM_CHANNEL_SEK);
		break;
	case CTRL_MODE_60V:
		ctrl_PID_reset(&ctrl_pi_voltage_boost);
		ctrl_PID_reset(&ctrl_pi_boost_iout_limit);
		hrtim_set_freq(HRTIM_CHANNEL_PRIM, CTRL_PARAM_SW_FREQ_LOW);
		hrtim_set_freq(HRTIM_CHANNEL_SEK, CTRL_PARAM_SW_FREQ_HIGH);
		// This is set to low, because it is part of the voltage ramp.
		hrtim_set_duty(HRTIM_CHANNEL_PRIM, CTRL_PARAM_CONST_DUTY_LOW);
		hrtim_set_duty(HRTIM_CHANNEL_SEK, CTRL_PARAM_CONST_DUTY_LOW);
		hrtim_enable(HRTIM_CHANNEL_PRIM);
		hrtim_enable(HRTIM_CHANNEL_SEK);
		break;
	case CTRL_MODE_RESISTANCE_1A:
	case CTRL_MODE_RESISTANCE_1mA:
		ctrl_main_apply_reference(mode, 0);
	case CTRL_MODE_10A:
		ctrl_PID_reset(&ctrl_pi_voltage_buck);
		ctrl_PID_reset(&ctrl_pi_current);
		hrtim_set_freq(HRTIM_CHANNEL_PRIM, CTRL_PARAM_SW_FREQ_HIGH);
		hrtim_set_freq(HRTIM_CHANNEL_SEK, CTRL_PARAM_SW_FREQ_LOW);
		hrtim_set_duty(HRTIM_CHANNEL_SEK, CTRL_PARAM_CONST_DUTY_LOW); // Needs to be low!!
		hrtim_set_duty(HRTIM_CHANNEL_PRIM, 0);
		hrtim_enable(HRTIM_CHANNEL_PRIM);
		hrtim_enable(HRTIM_CHANNEL_SEK);
		break;
	case CTRL_MODE_ISOMETER:
		ctrl_PID_reset(&ctrl_pi_voltage_hv);
		ctrl_PID_reset(&ctrl_pi_hv_iout_limit);
		hrtim_set_freq(HRTIM_CHANNEL_HV, CTRL_PARAM_SW_FREQ_HV);
		hrtim_set_duty(HRTIM_CHANNEL_HV, 0);
		hrtim_enable(HRTIM_CHANNEL_HV);
		break;

	case CTRL_MODE_OFF:
	default:
		break;
	}
	ctrl_main_handle.ramp = 0.2F;
	ctrl_main_handle.mode = mode;
}

/*
 * The order of the two statements below is load-bearing, as is the fact that
 * ctrl_main_start_ctrl() assigns ctrl_main_handle.mode last.
 *
 * Both functions run in main context from statemachine_step() (TIM2 tick,
 * IRQ_PRIO_AUX), while ctrl_main_ctrl() runs from the ADC control-loop
 * interrupt at IRQ_PRIO_CTRL_LOOP -- which is higher, so it can preempt them
 * part-way through. Clearing mode first here means a preempting control-loop
 * tick sees CTRL_MODE_OFF and writes no duty, rather than driving a converter
 * whose PWM is about to be disabled underneath it. Setting mode last in
 * start_ctrl() is the mirror image: the loop only starts acting once the
 * frequencies, duties and PID state are fully set up.
 *
 * Before the interrupt priorities were split, TIM2 and the ADC DMA interrupt
 * shared priority 0 and could not preempt each other, so this ordering was
 * merely tidy. It is now what keeps the two contexts consistent -- do not
 * reorder either function's tail without re-checking that.
 */
void ctrl_main_stop_control(void) {
	ctrl_main_handle.mode = CTRL_MODE_OFF;
	hrtim_disable(HRTIM_CHANNEL_ALL);
}

/**
 * Main control task
 */
/*
 * Takes the converted measurements directly rather than the whole
 * ADC_MEAS_DATA. The caller (HAL_ADC_ConvCpltCallback() in adc.c) hands over
 * an ISR-private set of freshly converted values whose enclosing struct has
 * no populated raw/calibration members, so narrowing the parameter here makes
 * reaching for one a compile error instead of a silent read of zeros in the
 * control loop.
 */
void ctrl_main_ctrl(const ADC_CONVERTED_DATA *meas) {
	switch (ctrl_main_handle.mode) {

	case CTRL_MODE_60V:
		ctrl_main_ctrl_voltage_boost(meas->v_out,
				meas->v_term_ext_mv, meas->i_out_ext_mA);
		break;
	case CTRL_MODE_RESISTANCE_1A:
	case CTRL_MODE_RESISTANCE_1mA:
		ctrl_main_ctrl_voltage_buck(meas->v_out,
				meas->v_out);
		break;
	case CTRL_MODE_10A:
		ctrl_main_ctrl_current(meas->i_out,
				meas->i_out_ext_mA);

		break;
	case CTRL_MODE_ISOMETER:
		ctrl_main_ctrl_voltage_hv(meas->v_hv,
				meas->v_term_ext_mv,
				meas->i_iso_ext_uA);
		break;
	case CTRL_MODE_CHARGE:
		uint16_t stack_mV = bms.VoltageRegisters.StackVoltage;
		uint8_t stack_valid = (stack_mV >= CTRL_PARAM_STACK_VOLTAGE_MIN_VALID_mV)
				&& (stack_mV <= CTRL_PARAM_STACK_VOLTAGE_MAX_VALID_mV);

		if (!ctrl_main_handle.charge_cv_phase && stack_valid
				&& stack_mV >= CTRL_PARAM_CHARGE_END_VOLTAGE_mV) {
			ctrl_main_handle.charge_cv_phase = 1;
			ctrl_pi_charge_voltage.prev_I_action = ctrl_pi_charge_current.action;
		}

		if (!ctrl_main_handle.charge_cv_phase)
			ctrl_main_ctrl_charge_current(-meas->i_out,
					-meas->i_out_ext_mA);
		else
			ctrl_main_ctrl_charge_voltage(meas->v_in,
					bms.VoltageRegisters.StackVoltage);
		break;

	case CTRL_MODE_OFF:
	default:
		break;
	}


}

/**
 * Computes the reference value for the given (target) mode from the poti
 * count. Takes mode explicitly rather than reading ctrl_main_handle.mode, so
 * it can be called continuously from statemachine.c to keep the reference
 * live-computed for whichever screen is showing, even before
 * ctrl_main_start_ctrl() has actually activated the control loop.
 * @param mode Target control mode to compute the reference for.
 * @param reference_poti_count Reference value of the poti (in count)
 */
void ctrl_main_apply_reference(ctrl_mode_t mode, uint16_t reference_poti_count) {
	switch (mode) {

	case CTRL_MODE_60V:
		ctrl_main_handle.voltage_reference_mV = reference_poti_count * 500; // 500mV Resolution, Max range 63V
		break;
	case CTRL_MODE_10A:
		ctrl_main_handle.current_reference_mA = reference_poti_count * 100; // 100mA Resolution, Max Range 10A
		break;
	case CTRL_MODE_RESISTANCE_1A:
		ctrl_main_handle.voltage_reference_mV = CTRL_PARAM_IDLE_VOLTAGE_1A_mV;
		break;
	case CTRL_MODE_RESISTANCE_1mA:
		ctrl_main_handle.voltage_reference_mV = CTRL_PARAM_IDLE_VOLTAGE_1mA_mV;
		break;
	case CTRL_MODE_ISOMETER:
		ctrl_main_handle.voltage_iso_reference_V =
				ctrl_main_iso_values[reference_poti_count & 0x3];
		break;
	case CTRL_MODE_CHARGE:
		ctrl_main_handle.current_reference_mA = CTRL_PARAM_CHARGE_CURRENT_mA;
		ctrl_main_handle.voltage_reference_mV = CTRL_PARAM_CHARGE_END_VOLTAGE_mV;
		break;

	case CTRL_MODE_OFF:
	default:
		ctrl_main_handle.voltage_reference_mV = 0;
		ctrl_main_handle.current_reference_mA = 0;
		ctrl_main_handle.voltage_iso_reference_V = 0;
		break;
	}

}

/*
 * Startup ramp shared by every ctrl_main_ctrl_*() control loop below.
 *
 * ctrl_main_handle.ramp is a SINGLE field, not one per controller: it is
 * zeroed once by ctrl_main_start_ctrl() and from then on incremented by
 * whichever ctrl_main_ctrl_*() function ctrl_main_ctrl()'s switch calls that
 * tick. Exactly one of those functions runs per control-loop tick, so a
 * shared counter is correct -- do NOT change this into a per-controller
 * ramp, and do not call this helper more than once per tick.
 *
 * Returns the multiplier just applied to `target` (1.0F once the ramp has
 * saturated past 1.0F, otherwise the freshly-incremented
 * ctrl_main_handle.ramp), so a caller that needs to ramp something else in
 * lockstep with the reference -- currently only
 * ctrl_main_ctrl_voltage_boost()'s PRIM duty -- can reuse the exact value
 * instead of re-deriving it from ctrl_main_handle.ramp after the fact.
 */
static float ctrl_apply_ramped_ref(PID_controller_t *c, float target, float div) {
	float multiplier;
	if (ctrl_main_handle.ramp > 1.0F) {
		multiplier = 1.0F;
		c->ref = target;
		ctrl_main_handle.ramp = 1.1F;
	} else {
		ctrl_main_handle.ramp += (div / CTRL_FREQ);
		multiplier = ctrl_main_handle.ramp;
		c->ref = target * multiplier;
	}
	return multiplier;
}

// Hard duty ceiling on the SEK channel (see ctrl_apply_inverted_sek_duty()
// below). No rationale beyond "hard limit" was recorded when this was
// originally written inline in ctrl_main_ctrl_charge_current()/
// ctrl_main_ctrl_charge_voltage(); preserved verbatim as a named constant.
#define CTRL_MAIN_SEK_DUTY_CEILING 0.5F

/*
 * Shared tail of CHARGE's CC and CV loops: HRTIM_CHANNEL_SEK is driven
 * inverted (see comment at each call site), clamped to
 * CTRL_MAIN_SEK_DUTY_CEILING.
 *
 * ctrl_main_handle.duty (the display's telemetry field) is intentionally
 * assigned the UNCLAMPED value even on the branch where the duty actually
 * written to HRTIM_CHANNEL_SEK was clamped -- that mismatch is what the
 * pre-refactor code did and what the display currently shows, so it is kept
 * as-is here rather than "fixed".
 */
static void ctrl_apply_inverted_sek_duty(float action) {
	if ((CTRL_PARAM_CONST_DUTY_HIGH - action) > CTRL_MAIN_SEK_DUTY_CEILING)
		hrtim_set_duty(HRTIM_CHANNEL_SEK, CTRL_MAIN_SEK_DUTY_CEILING);
	else
		hrtim_set_duty(HRTIM_CHANNEL_SEK, CTRL_PARAM_CONST_DUTY_HIGH - action);
	ctrl_main_handle.duty = (CTRL_PARAM_CONST_DUTY_HIGH - action) * 1000;
}

void ctrl_main_ctrl_voltage_buck(uint32_t voltage_meas_mV,
		int32_t voltage_meas_accurate_mV) {
	ctrl_apply_ramped_ref(&ctrl_pi_voltage_buck,
			ctrl_main_handle.voltage_reference_mV / 1000.0F, 10.0F);

	ctrl_PID_controller_execute(&ctrl_pi_voltage_buck, voltage_meas_mV / 1000.0F,
			voltage_meas_accurate_mV / 1000.0F, 0);

	// Apply Duty
	hrtim_set_duty(HRTIM_CHANNEL_PRIM, ctrl_pi_voltage_buck.action);
	ctrl_main_handle.duty = ctrl_pi_voltage_buck.action*1000;
}


void ctrl_main_ctrl_voltage_boost(uint32_t voltage_meas_mV,
		int32_t voltage_meas_accurate_mV, int32_t current_meas_ext_mA) {
	// Boost also ramps HRTIM_CHANNEL_PRIM's duty in lockstep with the
	// voltage reference (fixed at CTRL_PARAM_CONST_DUTY_HIGH once the ramp
	// has saturated, otherwise scaled by the same in-flight ramp
	// multiplier) -- reuse the multiplier ctrl_apply_ramped_ref() just
	// applied to the ref rather than re-deriving it.
	float ramp_multiplier = ctrl_apply_ramped_ref(&ctrl_pi_voltage_boost,
			ctrl_main_handle.voltage_reference_mV / 1000.0F, 10.0F);
	hrtim_set_duty(HRTIM_CHANNEL_PRIM, CTRL_PARAM_CONST_DUTY_HIGH * ramp_multiplier);

	ctrl_PID_controller_execute(&ctrl_pi_voltage_boost, voltage_meas_mV / 1000.0F,
			voltage_meas_accurate_mV / 1000.0F, 0);

	ctrl_PID_controller_execute(&ctrl_pi_boost_iout_limit,
			current_meas_ext_mA / 1000.0F, current_meas_ext_mA / 1000.0F, 0);

	float duty_limited = ctrl_pi_voltage_boost.action;
	if (ctrl_pi_boost_iout_limit.action < duty_limited)
		duty_limited = ctrl_pi_boost_iout_limit.action;

	// Apply Duty
	hrtim_set_duty(HRTIM_CHANNEL_SEK, duty_limited);
	ctrl_main_handle.duty = duty_limited*1000;
}

void ctrl_main_ctrl_current(int16_t current_meas_mA,
		int16_t current_meas_accurate) {

	ctrl_apply_ramped_ref(&ctrl_pi_current,
			ctrl_main_handle.current_reference_mA / 1000.0F, 10.0F);

	ctrl_PID_controller_execute(&ctrl_pi_current, current_meas_mA / 1000.0F,
			current_meas_accurate / 1000.0F, 0);

	hrtim_set_duty(HRTIM_CHANNEL_PRIM, ctrl_pi_current.action);
	ctrl_main_handle.duty = ctrl_pi_current.action*1000;

}

void ctrl_main_ctrl_charge_current(int16_t current_meas_mA,
		int16_t current_meas_accurate) {

	ctrl_apply_ramped_ref(&ctrl_pi_charge_current,
			ctrl_main_handle.current_reference_mA / 1000.0F, 0.5F);

	ctrl_PID_controller_execute(&ctrl_pi_charge_current, current_meas_mA / 1000.0F,
			current_meas_accurate / 1000.0F, 0);

	// Apply Duty inverted, as the secondary Duty is inversed
	ctrl_apply_inverted_sek_duty(ctrl_pi_charge_current.action);

}

/**
 * CV tail of the charge cycle: P-term from the fast internal ADC
 * (voltage_meas_mV), I-term from the accurate but slow (~1Hz) BMS
 * StackVoltage reading (voltage_meas_accurate_mV) - the PID just holds the
 * last value between BMS refreshes, same as elsewhere in this file.
 */
void ctrl_main_ctrl_charge_voltage(uint32_t voltage_meas_mV,
		int32_t voltage_meas_accurate_mV) {

	ctrl_apply_ramped_ref(&ctrl_pi_charge_voltage,
			ctrl_main_handle.voltage_reference_mV / 1000.0F, 10.0F);

	ctrl_PID_controller_execute(&ctrl_pi_charge_voltage, voltage_meas_mV / 1000.0F,
			voltage_meas_accurate_mV / 1000.0F, 0);

	// Apply Duty inverted, as the secondary Duty is inversed
	ctrl_apply_inverted_sek_duty(ctrl_pi_charge_voltage.action);

}

void ctrl_main_ctrl_voltage_hv(uint32_t voltage_meas_mV,
		int32_t voltage_meas_accurate_mV, int32_t current_meas_iso_uA) {

	ctrl_apply_ramped_ref(&ctrl_pi_voltage_hv,
			ctrl_main_handle.voltage_iso_reference_V, 10.0F);

	ctrl_PID_controller_execute(&ctrl_pi_voltage_hv,
			voltage_meas_mV / 1000.0F, voltage_meas_accurate_mV / 1000.0F, 0);


	ctrl_PID_controller_execute(&ctrl_pi_hv_iout_limit,
			current_meas_iso_uA / 1000000.0F, current_meas_iso_uA / 1000000.0F, 0);

	float duty_limited = ctrl_pi_voltage_hv.action;
	if (ctrl_pi_hv_iout_limit.action < duty_limited)
		duty_limited = ctrl_pi_hv_iout_limit.action;

	// Apply Duty
	hrtim_set_duty(HRTIM_CHANNEL_HV, duty_limited);
	ctrl_main_handle.duty = duty_limited * 1000;

}

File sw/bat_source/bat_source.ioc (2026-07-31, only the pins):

Mcu.UserName=STM32G474VETx
PA0.GPIO_Label=I_OUT
PA0.Signal=ADC1_IN1
PA1.GPIO_Label=V_TERM
PA1.Signal=ADC2_IN2
PA10.GPIO_Label=CONV_CTRL.PRIM_L
PA10.Signal=HRTIM1_CHB1
PA11.GPIO_Label=CONV_CTRL.PRIM_H
PA11.Signal=HRTIM1_CHB2
PA12.GPIO_Label=ADC.CLK
PA12.Signal=S_TIM16_CH1
PA13.GPIO_Label=SWD.SWDAT
PA13.Signal=SYS_JTMS-SWDIO
PA14.GPIO_Label=SWD.SWCLK
PA14.Signal=SYS_JTCK-SWCLK
PA15.GPIO_Label=SPI.CS
PA15.Signal=GPIO_Output
PA2.GPIO_Label=QSPI.CS/
PA2.Signal=QUADSPI1_BK1_NCS
PA3.GPIO_Label=QSPI.CLK
PA3.Signal=QUADSPI1_CLK
PA4.GPIO_Label=VREF/2_UC
PA4.Signal=COMP_DAC11_group
PA5.GPIO_Label=I_1A_REF
PA5.Signal=COMP_DAC12_group
PA6.GPIO_Label=QSPI.IO3
PA6.Signal=QUADSPI1_BK1_IO3
PA7.GPIO_Label=QSPI.IO2
PA7.Signal=QUADSPI1_BK1_IO2
PA8.GPIO_Label=BMS_CTRL.I_BAT
PA8.Signal=ADC5_IN1
PA9.GPIO_Label=I_ISO
PA9.Signal=ADC5_IN2
PB0.GPIO_Label=QSPI.IO1
PB0.Signal=QUADSPI1_BK1_IO1
PB1.GPIO_Label=QSPI.IO0
PB1.Signal=QUADSPI1_BK1_IO0
PB10.GPIO_Label=RESTRICT\: No toggle (REFBUF)
PB10.Signal=GPIO_Analog
PB11.GPIO_Label=RESTRICT\: No toggle (REFBUF)
PB11.Signal=GPIO_Analog
PB12.GPIO_Label=HV_CTRL.PRIM
PB12.Signal=HRTIM1_CHC1
PB13.GPIO_Label=RESTRICT\: No toggle (REFBUF)
PB13.Signal=GPIO_Analog
PB14.GPIO_Label=RESTRICT\: No toggle (REFBUF)
PB14.Signal=GPIO_Analog
PB15.GPIO_Label=V_HV
PB15.Signal=ADC4_IN5
PB2.GPIO_Label=HV_CTRL.EN
PB2.Signal=GPIO_Output
PB3.GPIO_Label=SWD.SWO
PB3.Signal=SYS_JTDO-SWO
PB5.GPIO_Label=UI_PRESENT
PB5.Signal=GPIO_Input
PB6.GPIO_Label=ENCODER.B
PB6.Signal=S_TIM4_CH1
PB7.GPIO_Label=ENCODER.A
PB7.Signal=S_TIM4_CH2
PB8-BOOT0.GPIO_Label=BOOT0
PB8-BOOT0.Signal=GPIO_Input
PB9.GPIO_Label=BUTTON.OUT
PB9.Signal=GPIO_Input
PC0.GPIO_Label=SHUNT_EN
PC0.Signal=GPIO_Output
PC1.GPIO_Label=OUT_SEL_HV
PC1.Signal=GPIO_Output
PC10.GPIO_Label=SPI.SCK
PC10.Signal=SPI3_SCK
PC11.GPIO_Label=SPI.MISO
PC11.Signal=SPI3_MISO
PC12.GPIO_Label=SPI.MOSI
PC12.Signal=SPI3_MOSI
PC13.GPIO_Label=RESTRICT\: No toggle (LSE)
PC13.Signal=GPIO_Analog
PC14-OSC32_IN.Signal=RCC_OSC32_IN
PC15-OSC32_OUT.Signal=RCC_OSC32_OUT
PC2.GPIO_Label=OVP_RESET
PC2.Signal=GPIO_Output
PC3.GPIO_Label=OVP_N
PC3.Signal=GPIO_Input
PC4.GPIO_Label=OCP_N
PC4.Signal=GPIO_Input
PC5.GPIO_Label=DISCHARGE_N
PC5.Signal=GPIO_Output
PC6.GPIO_Label=I2C.SCL
PC6.Signal=I2C4_SCL
PC7.GPIO_Label=I2C.SDA
PC7.Signal=I2C4_SDA
PC8.GPIO_Label=CONV_CTRL.SEC_L
PC8.Signal=HRTIM1_CHE1
PC9.GPIO_Label=CONV_CTRL.SEC_H
PC9.Signal=HRTIM1_CHE2
PD0.GPIO_Label=ADC.SYNC/RESET_N
PD0.Signal=GPIO_Output
PD10.GPIO_Label=CONV_CTRL.TEMP_SEC
PD10.Signal=ADC5_IN7
PD11.GPIO_Label=V_3V3_A
PD11.Signal=ADC5_IN8
PD12.GPIO_Label=CONV_CTRL.TEMP_TRAFO
PD12.Signal=ADC5_IN9
PD13.GPIO_Label=SHUNT_ISO_EN
PD13.Signal=GPIO_Output
PD14.GPIO_Label=RESTRICT\: No toggle (REFBUF)
PD14.Signal=GPIO_Analog
PD15.GPIO_Label=I2C.ALERT
PD15.Signal=GPIO_Input
PD2.GPIO_Label=ADC.DRDY_N
PD2.Signal=GPXTI2
PD4.GPIO_Label=BUTTON.ESC
PD4.Signal=GPIO_Input
PD5.GPIO_Label=UART.TX
PD5.Signal=USART2_TX
PD6.GPIO_Label=UART.RX
PD6.Signal=USART2_RX
PD8.GPIO_Label=TEMP_CURRENT
PD8.Signal=ADC5_IN12
PD9.GPIO_Label=CONV_CTRL.TEMP_PRIM
PD9.Signal=ADC5_IN13
PE1.GPIO_Label=BUTTON.OK
PE1.Signal=GPIO_Input
PE10.GPIO_Label=V_15V
PE10.Signal=ADC5_IN14
PE11.GPIO_Label=V_VCC
PE11.Signal=ADC5_IN15
PE12.GPIO_Label=V_5V
PE12.Signal=ADC5_IN16
PE13.GPIO_Label=V_IN
PE13.Signal=ADC3_IN3
PE14.GPIO_Label=OUT_SEL_ISO
PE14.Signal=GPIO_Output
PE15.GPIO_Label=V_OUT
PE15.Signal=ADC4_IN2
PE2.GPIO_Label=DISPLAY.SCK
PE2.Signal=SPI4_SCK
PE3.GPIO_Label=DISPLAY.WR
PE3.Signal=GPIO_Output
PE4.GPIO_Label=DISPLAY.CS
PE4.Signal=GPIO_Output
PE5.GPIO_Label=DISPLAY.MISO
PE5.Signal=SPI4_MISO
PE6.GPIO_Label=DISPLAY.MOSI
PE6.Signal=SPI4_MOSI
PE7.GPIO_Label=CONV_CTRL.EN
PE7.Signal=GPIO_Output
PE8.GPIO_Label=V_3V3
PE8.Signal=ADC5_IN6
PE9.GPIO_Label=ON_REQ
PE9.Signal=GPIO_Output
PF9.GPIO_Label=BMS_CTRL.WAKEUP
PF9.Signal=GPIO_Output

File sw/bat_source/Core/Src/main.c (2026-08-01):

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
/* Includes ------------------------------------------------------------------*/
#include "main.h"
#include "adc.h"
#include "dac.h"
#include "dma.h"
#include "hrtim.h"
#include "i2c.h"
#include "quadspi.h"
#include "rtc.h"
#include "spi.h"
#include "tim.h"
#include "usart.h"
#include "gpio.h"

/* USER CODE BEGIN Includes */
#include "driver_pca9554.h"
#include "aux_io_ctrl.h"
#include "bq76905.h"
#include "bq76905_config.h"
#include "ctrl_main.h"
#include "timer.h"
#include "display.h"
#include "opt3004.h"
#include "lp581x.h"
#include "ui_ctrl.h"
#include "statemachine.h"
#include "cli.h"
#include "config_store.h"
#include <stdio.h>
#include "stdint.h"
#include "lcd.h"
#include "w25n01gv.h"
#include "icon_store.h"
#include "ads131m04.h"
#include "protection.h"
/* USER CODE END Includes */


/* USER CODE BEGIN PV */
BQ76905_handle bms;
ADC_MEAS_DATA adc_data;
ADS131M04_handle ext_adc;
w25n01gv_handle flash;
w25n01gv_status_t flash_status = W25N01GV_OK;

/* USER CODE END PV */

void SystemClock_Config(void);
/**
  * @brief  The application entry point.
  * @retval int
  */
int main(void)
{

  /* USER CODE BEGIN 1 */
	EVENT_STRUCT e;
  /* USER CODE END 1 */

  /* MCU Configuration--------------------------------------------------------*/

  /* Reset of all peripherals, Initializes the Flash interface and the Systick. */
  HAL_Init();

  /* Configure the system clock */
  SystemClock_Config();

  /* Initialize all configured peripherals */
  MX_GPIO_Init();
  MX_DMA_Init();
  MX_HRTIM1_Init();
  MX_QUADSPI1_Init();
  MX_SPI4_Init();
  MX_ADC1_Init();
  MX_ADC2_Init();
  MX_ADC3_Init();
  MX_ADC4_Init();
  MX_ADC5_Init();
  MX_DAC1_Init();
  MX_SPI3_Init();
  MX_I2C4_Init();
  MX_TIM4_Init();
  MX_TIM16_Init();
  MX_USART2_UART_Init();
  MX_RTC_Init();
  MX_TIM2_Init();
  MX_TIM6_Init();
  /* USER CODE BEGIN 2 */
  /*
   * Init the event and error queues. Must run before timer_init()/
   * timer_start(), since the timer interrupt is the first thing that can
   * post an event via event_Add(), and before anything that can call
   * error_Add() (e.g. i2c_Add() below).
   */
  event_Init();
  error_Init();

  /*
   * Setup internal timer structure
   */
  timer_init();

  /*
   * DAC test setup
   */
  dac_setValueRef2(2048);

  /*
   * CLI Setup
   */
  cli_init(&huart2);

  /*
   * Init UI control (LEDs)
   */
  ui_ctrl_init();


  /*
   * Load calibration / ID data from EEPROM (or default it, on first
   * boot / missing chip). Must run before adc_init() and
   * ctrl_main_init() so both see the loaded calibration.
   */
  config_store_init();

  /*
   * ADC Init
   */
  adc_init(ext_adc.channelData);
  ADS131M04_init(&ext_adc, &hspi3, SPI_CS_GPIO_Port, SPI_CS_Pin, ADC_SYNC_RESET_N_GPIO_Port, ADC_SYNC_RESET_N_Pin);
  adc_configure_mode(STATEMACHINE_MODE_10A_OUT);
  adc_start();
  /*
   * Wakeup BMS and configure if necessary
   */
  GPIO_SET_BMS_CTRL_WAKEUP(1);
  HAL_Delay(100);
  GPIO_SET_BMS_CTRL_WAKEUP(0);
  BQ76905_init(&bms, BQ76905_I2C_ADDRESS);
  bms.battery_capacity_mAs = config_store.calibration.battery_capacity_mAs;


  /*
   * PWM Init
   */
  hrtim_set_freq(HRTIM_CHANNEL_PRIM, 50000);
  hrtim_set_freq(HRTIM_CHANNEL_SEK, 150000);
  hrtim_set_duty(HRTIM_CHANNEL_PRIM, 0.985);

  hrtim_start_timer();
  timer_start();

  /*
   * QSPI flash memory init
   */
  flash_status = w25n01gv_init(&flash, &hqspi1, 1000);
  if (flash_status != W25N01GV_OK) {
    printf("Flash initialisation failed!\r\n");
  }
  icon_store_init(); // safe even if flash init failed above -- just reports unavailable

  gpio_turnOn();

  LCD_init();

  protection_init();
  ctrl_main_init();
  statemachine_init();


  /* USER CODE END 2 */

  /* Infinite loop */
  /* USER CODE BEGIN WHILE */
  while (1)
  {

	  cli_loop();

	  e = event_Get();
	  switch(e.event){
		case EVENT_VOID:
		case EVENT_INIT:
			break;
		case EVENT_IIC_RX:
		case EVENT_IIC_TX:
			if(e.callback != 0)
				e.callback(e.argument);
			break;
		case EVENT_IIC_ERROR:
			if(e.callback != 0)
				e.callback(e.argument);
			break;
		case EVENT_EEPROM_READ:
			break;
		case EVENT_EEPROM_TIMEOUT:
			break;
		case EVENT_SM_STEP:
			statemachine_step();
			break;
		case EVENT_BMS_TIMER:
			BQ76905_readAllValuesAsync(&bms);
			break;
		case EVENT_EVENT:
		default:
			break;

	  }


	  /*
	   * Loop delay
	   */
	  HAL_Delay(1);

    /* USER CODE END WHILE */

    /* USER CODE BEGIN 3 */
  }
  /* USER CODE END 3 */
}

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
/* USER CODE BEGIN 4 */
/**
 * External ADC finished SPI communication
 */
void HAL_SPI_TxRxCpltCallback(SPI_HandleTypeDef *hspi) {
	ADS131M04_handleSPIComplete(&ext_adc);
}


/**
 * Interrupt for external ADC
 */
void HAL_GPIO_EXTI_Callback(uint16_t GPIO_Pin) {
	if (GPIO_Pin == ADC_DRDY_N_Pin) {
		ADS131M04_handleDRDYInterrupt(&ext_adc);
	} else {
		// __NOP();
	}
}
/* USER CODE END 4 */
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


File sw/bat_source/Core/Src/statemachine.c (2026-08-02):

/*
 * statemachine.c
 *
 *  Created on: Aug 9, 2025
 *      Author: ahorat
 */

#include "statemachine.h"
#include "aux_io_ctrl.h"
#include "display.h"
#include "menu.h"
#include "input.h"
#include "timer.h"
#include "ctrl_main.h"
#include "stm32g4xx_hal.h"
#include "adc.h"
#include "ui_ctrl.h"
#include "tim.h"
#include "gpio.h"
#include "hrtim.h"
#include "bq76905.h"
#include "ctrl_param.h"
#include "calibration.h"
#include "protection.h"
#include "balancing.h"
#include "dac.h"
#include "config_store.h"
#include "mode_table.h"

statemachine_t statemachine_handle;
uint16_t ok_button_pressed;
uint16_t esc_button_pressed;
uint16_t out_button_pressed;
extern ctrl_main_t ctrl_main_handle;
extern ADC_MEAS_DATA adc_data;
extern BQ76905_handle bms;

/* Remembers protection_get_error_mask() while a protection fault is forcing
 * the converter off, so that if CHARGE is ultimately left because of it (see
 * the protection_forced_output_off recovery branch in statemachine_step()),
 * the debug print below can still report which source(s) caused it -- by
 * the time the fault actually clears and the mode transition happens, the
 * live mask has already gone back to 0. */
static uint16_t charge_protection_exit_mask;

void statemachine_switchfromIdle(statemachine_modes_t mode);
void statemachine_switchtoIdle(void);
static void statemachine_apply_encoder_setpoint(void);
static void statemachine_step_calibration(void);
static void statemachine_enter_mode_generic(statemachine_modes_t mode);

/* Settings > Calibration sub-UI state -- 0=channel list, 1=zero step,
 * 2=optional gain step (see display_calibration_enter/update()). */
static uint8_t calibration_ui_state = 0;
static calibration_channel_t calibration_selected_channel = CAL_CH_V_TERM;

/* Encoder-dialed reference value step per channel (in the channel's native
 * unit) for the optional gain calibration step. V_TERM/I_OUT reuse the same
 * per-detent scale already used for their live setpoints (ctrl_main.c's
 * CTRL_MODE_60V/CTRL_MODE_10A); the others are new, sized to give a sensible
 * dial range for typical reference values on that channel. */
static const float CALIBRATION_REFERENCE_STEP[CAL_CH_COUNT] = {
		[CAL_CH_V_TERM] = 500.0f,   // mV/detent, max ~63V
		[CAL_CH_V_SENS] = 50000.0f, // uV/detent, max ~6.3V
		[CAL_CH_V_OUT] = 500.0f,    // mV/detent, max ~63V
		[CAL_CH_V_HV] = 10000.0f,   // mV/detent, max ~1270V
		[CAL_CH_I_OUT] = 100.0f,    // mA/detent, max ~12.7A
		[CAL_CH_I_ISO] = 100.0f,    // uA/detent, max ~12.7mA
		[CAL_CH_V_IN] = 500.0f,     // mV/detent, max ~63V (battery stack
		                            // rail, nominal ~14V, ADC full scale
		                            // ~51V per ADC_VIN_GAIN_MV)
};

void statemachine_init(void) {
	statemachine_handle.output_on = 0;
	statemachine_handle.current_mode = STATEMACHINE_IDLE;
	statemachine_handle.current_menu_index = 0;
	statemachine_handle.settings_mode = STATEMACHINE_SETTINGS_MODE_MENU;
	ok_button_pressed = 0;
	esc_button_pressed = 0;
	statemachine_handle.protection_forced_output_off = 0;

	input_init();
	input_encoder_reset(62);
	display_init();

	timer_add(STATEMACHINE_STEP_PERIOD_mS, TIMER_TYPE_TICK, EVENT_SM_STEP, 0);
	statemachine_switchtoIdle();
}

/* Feeds the live encoder value into ctrl_main's poti_reference and
 * immediately recomputes the derived reference (voltage/current/iso target)
 * for whichever mode is currently showing -- this runs every tick regardless
 * of whether OUT is held, so the reference is already correct and ready the
 * moment the controller actually starts, not just eventually once the ADC
 * ISR happens to catch up. */
static void statemachine_apply_encoder_setpoint(void) {
	ctrl_main_handle.poti_reference = input_encoder_read();
	ctrl_main_apply_reference(statemachine_mode_to_ctrl_mode(statemachine_handle.current_mode),
			ctrl_main_handle.poti_reference);
}
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

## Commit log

2026-07-25 SW: Fix icon store seed order to match menu_order after Charge move
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2026-07-25 SW: Dedicated charge-current controller, EEPROM-adaptable SoC tracking, PID registry
    - New ctrl_pi_charge_current PID loop, separate from the shared current
    controller, so retuning one no longer detunes the other
    - ctrl_pid_table[] drives ctrl_main_init()/setPI/saveEEPROM/readEEPROM
    instead of per-controller hand-written code; dropped dead flyback loops
    - Fixed BMS safety-fault check silently becoming a no-op, missing
    injected-ADC re-arm/routing for I_BAT, a duty telemetry overwrite, and
    charge auto-restart chattering at the end-voltage boundary
    - charge_percentage moved out of the BQ76905 PASSQ-mirrored struct (wasn't
    part of the actual 12-byte register) and is now computed from a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
    [adc.c, bq76905.c, cli.c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]
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2026-07-25 Fix SectorErase() address bug in the QSPI NAND external loader
    SectorErase() multiplied an already-correct byte offset by
    W25N01GV_PAGES_PER_BLOCK, inflating erase addresses up to 64x too large
    and causing STM32_Programmer_CLI writes to hang. Also adapts the
    "External Loader" build config's post-build .stldr copy step to Linux
    (was a Windows-only cmd.exe command) and rebuilds the .stldr with the fix.
    [Loader_Src.c]
2026-07-31 SW: Fix button hold-delay and encoder double-click
    Buttons were sampled at only 10Hz with zero debounce, so a normal tap
    could land entirely between samples and get missed. Encoder's TIM4
    input-capture filter was disabled, letting quadrature bounce cancel
    counts. Raises the statemachine tick to 50Hz/20ms (TIMER_FREQ + TIM2
    period, kept in lockstep - timer_add() silently no-ops if load rounds
    to 0), adds 2-sample debounce to the HW button reads in input.c, and
    enables TIM4's IC1/IC2 digital filter at max strength.
    [input.c, tim.c, ui_ctrl.c]
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2026-07-31 SW: Filter milliohm reading, gate to 1A pulse's on-phase
    r_mOhmx10/r_Ohmx10 now only recompute during the pulsed 1A
    reference's "high" half and hold through "low", with a ~2Hz one-pole
    low-pass on r_mOhmx10 in RESISTANCE_1A mode. Also restarts ADC5's DMA
    scan after every mode switch (was never restarted, killing
    temperatures/v_3v3/etc. after the first mode change), and widens
    v_in/v_hv/v_out to int32_t to fix an unsigned wraparound when the
    calibrated offset exceeds the raw reading.
    [adc.c, adc.h]
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2026-07-31 SW: Mask OCP to ISOMETER mode, latch it like every other protection fault
    protection_update() now takes the current mode, only evaluating OCP_N
    while ISOMETER is active (OVP stays unconditional). The generic
    protection interlock resume path was rewritten: it drives whichever
    enable GPIO the current mode actually uses (GPIO_HV_CTRL_EN for
    ISOMETER, GPIO_CONV_CTRL_EN otherwise) instead of always both, and now
    requires the OUT button to be seen released before a subsequent press
    can resume - previously a press already held down when the fault
    cleared resumed instantly, and protection_forced_output_off was reset
    every tick regardless of whether resume actually happened.
    [protection.c, protection.h, statemachine.c]
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2026-07-31 Add compile gate: -Wall -Wextra syntax check with a warnings baseline
    tools/check.sh syntax-compiles every Core/Src/*.c with the ARM toolchain
    bundled in STM32CubeIDE (globbed, so it survives IDE updates; overridable
    via CC) using the same flags as .cproject, and diffs the diagnostics
    against tools/warnings.baseline. New warnings fail; resolved ones are
    reported as progress.
    Deliberately -fsyntax-only: no build dir, linker script or CubeIDE
    workspace needed, so it runs in a second as a per-change gate. Link-time
    properties (section sizes, stack headroom) still need a full build.
    Baseline records the 26 diagnostics present today, several of which are
    real defects rather than noise -- notabl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
2026-07-31 SW: Default PID gains from ctrl_pid_table instead of by hand
    config_store_setDefaults() memsets the store and then hand-assigned
    every calibration field - but only 12 of the 16 PID gain fields.
    voltage_hv_p/i and flyback_current_p/i were never assigned, so they
    stayed 0 on a blank EEPROM, a missing EEPROM, or any calibration CRC
    mismatch.
    That left ctrl_pi_voltage_hv and ctrl_pi_hv_iout_limit initialised with
    P=0 and I=0, so their action stayed 0, duty_limited in
    ctrl_main_ctrl_voltage_hv() was min(0,0), and the HV flyback never
    produced output: ISOMETER ran but measured nothing.
    Loop over ctrl_pid_table[] instead, using its default_p/default_i
    fields - present since the table was introduc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
    [config_store.c]
2026-07-31 SW: Gate the resistance OVER indication per mode
    update_resistance() renders both resistance modes but tested
    r_mOhmx10 > 5000 regardless of which one was active. r_mOhmx10 is the
    milliohm reading; in Ohmmeter mode (RESISTANCE_1mA) any load above
    ~0.5 ohm satisfied it, so the Ohmmeter displayed OVER for essentially
    every real measurement.
    Compute over_range per mode: milliohm mode tests r_mOhmx10, ohm mode
    tests r_Ohmx10's zero-current sentinel. Replace the bare 5000 with
    ADC_R_MOHMX10_MAX_VALUE so this gate and adc_convert_data()'s clamp
    cannot drift apart.
    The threshold test is kept for milliohm mode deliberately: adc.c's
    clamp is keyed on adc_injected_mode, which calibration.c can retar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
    [display.c]
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2026-07-31 Make the warning baseline insensitive to line numbers
    The baseline recorded file:line:col for each diagnostic, so any edit that
    grew or shrank code above an existing warning shifted its line number and
    was reported as a new warning plus a resolved one.
    That is worse than noise: it pressures whoever is editing the tree to
    reshape source purely to keep line numbers stable. That already happened
    once in practice, with comments compacted to land a pre-existing warning
    back on its original line. The gate should constrain the diagnostics, not
    the layout.
    Compare on (file, diagnostic text) instead. Duplicates are preserved and
    comm does a multiset difference on sorted input, so a second instance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
2026-07-31 SW: Validate HRTIM channel and clamp period, fix enPWM channel mapping
    hrtim_set_freq() wrote 0x98968000/freq straight into PERxR, a 16-bit
    register. Any freq below ~39 kHz overflowed and truncated to an
    arbitrary period - i.e. the converter running at a switching frequency
    nobody asked for - and freq==0 divided by zero. Clamp the period to the
    same [0x60, 0xFFDF] window hrtim_set_duty() already enforces, and refuse
    freq==0 outright rather than inventing a substitute. All current call
    sites (50 kHz, 150 kHz, 350 kHz, 1 MHz) produce periods well inside the
    window, so register writes are unchanged today.
    HRTIM_CHANNEL_ALL was 0, which is also Timer A's valid sTimerxRegs[]
    index. hrtim_disable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
    [cli.c, hrtim.c]
2026-07-31 SW: Close the adc_data race between the ADC ISR and main context
    adc_data is written from interrupt context (adc_convert_fast_data() and
    the injected-conversion callback) and by DMA, while main context reads
    the same fields from adc_convert_data(), protection_update(), every
    display_* function and most CLI commands. Nothing protected either side.
    Two separate problems:
    adc_data.raw is a DMA destination but its members were plain uint16_t.
    The project builds at -Os, so the compiler was free to hoist a raw.*
    read out of a loop and never observe a DMA update. Mark them volatile.
    adc_data.converted is written field by field in the ISR, so a main
    context reader could mix values from two differ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
    [adc.c, adc.h, ctrl_main.c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]
2026-07-31 SW: Guard the event, error and I2C queues against their producers
    Three related races in the queue layer.
    event_Add() advanced head via CAS and only then wrote the slot's event,
    callback and argument, so the consumer could see a published-but-empty
    entry -- and main() dispatches EVENT_IIC_RX/TX by calling e.callback as
    a function pointer. Filling the slot before publishing does not fix it
    either: reading head and filling the slot are separate steps, so a
    producer preempted between them can resume and overwrite a slot a second
    producer has already filled and published, losing that event and
    delivering its own twice. Reserve, fill and publish as one indivisible
    step under a PRIMASK-saving cri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
    [error.c, event.c, i2c.c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]
2026-07-31 SW: Give the ADC control loop priority over everything else
    Every peripheral interrupt was registered at preemption priority 0, so
    nothing could preempt anything: the 25 kHz ADC control loop that updates
    the converter duty cycle could be held off by a whole I2C transfer, an
    LCD SPI transfer, or the TIM2 tick that dispatches the entire state
    machine. On a switching converter that is control-loop jitter.
    Add Core/Inc/irq_priority.h with three named tiers and use it at every
    HAL_NVIC_SetPriority() call site instead of bare numbers:
    0 CTRL_LOOP DMA1_Channel2 only -- hdma_adc1.Instance is DMA1_Channel2
    and HAL_ADC_ConvCpltCallback() only runs the control step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
    [ads131m04.c, ctrl_main.c, dac.c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]
2026-07-31 SW: Drive per-mode behaviour from one descriptor table
    Mode data was spread across four hand-maintained switches that had to be
    kept in lockstep: statemachine_switchfromIdle()'s ~100-line entry switch,
    statemachine_mode_to_ctrl_mode(), adc_configure_mode()'s shared trigger
    assignment, and aux_io_ctrl_mode_config[]. Adding or changing a mode meant
    editing all four, and two live bugs already come from exactly that
    omission pattern.
    mode_table[] now carries ctrl_mode, aux_io_mask, enable_gpio, entry flags
    and adc_trigger per mode. statemachine_switchfromIdle() is a generic
    sequence plus three real special cases (IDLE redirect, AMPMETER's voltage
    refusal, SETTINGS' submenu setup); the other thr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
    [adc.c, aux_io_ctrl.c, ctrl_main.c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]
2026-07-31 SW: Small correctness fixes across the CLI and display
    cli_printFloat() dropped the sign for values between -1 and 0, because
    (int32_t)(-0.5f) is 0 and the sign lived only in the integer part. Track
    it separately.
    cmd_printBMS() printed the int64_t charge accumulator with %ld. The
    compiler had been flagging this all along - it was in the warning
    baseline. Use %lld and drop the two "(low bytes)/(high bytes)" lines that
    existed to work around it.
    setPI's usage string hand-listed five controller IDs; the table has eight
    since ChargeVoltage, HVVoltage and HVCurrent were added. Generate the list
    from ctrl_pid_table[].name at help time so it cannot go stale again.
    display.c wrote a shared 48-by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
    [cli.c, display.c, ui_ctrl.c]
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2026-07-31 Move architecture.md into this repo and bring it up to date
    It lived in the older bat_Source checkout, where it could not travel with
    the code it describes.
    Corrected against the source: the state machine ticks at 20 ms, not
    100 ms; the control loop runs from ADC1's DMA-complete callback decimated
    by two, not directly from HRTIM; CTRL_FREQ is 25 kHz, not 50; the charge
    end voltage is 14200 mV (3550x4), not 14600; Settings has five sub-modes,
    not two; AMPMETER exists; and all operating modes are implemented, so the
    "most modes not implemented" item is gone.
    Added: the mode descriptor table, the interrupt priority policy and the
    ordering constraint it imposes on ctrl_main, the adc_data snaps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
2026-07-31 SW: Make V_IN a calibratable channel
    *** REQUIRES RECALIBRATION - see the PSVN note below ***
    V_IN was the only measurement channel with no calibration: converted with
    two fixed compile-time constants, ADC_VIN_OFFSET_MV and ADC_VIN_GAIN_MV,
    with no v_in_gain field existing at all. That matters because v_in is the
    CV-phase feedback in ctrl_main_ctrl_charge_voltage(), so an uncalibrated
    gain biases the voltage a pack is actually held at.
    Add CAL_CH_V_IN as a seventh calibratable channel, following V_OUT's
    pattern (internal voltage channel, uint16 offset + float gain, no
    external-ADC counterpart). Appended after the existing six so their
    channel numbers - which are user-facing CLI arguments -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
    [adc.c, adc.h, calibration.c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]
2026-07-31 Mirror the interrupt priorities and stack size into the .ioc
    The HAL_NVIC_SetPriority() calls that carry the priority policy sit in
    CubeMX GENERATED regions of dma.c, spi.c, i2c.c, tim.c, dac.c and gpio.c -
    that is just where CubeMX emits them, there is no USER CODE block to put
    them in. So did the _Min_Stack_Size raise, which lives in the generated
    linker scripts. Regenerating from the .ioc would have rewritten all of it
    and flattened every interrupt back to priority 0, undoing exactly what the
    policy exists to fix, with nothing in a source diff to show why.
    Set the 17 NVIC.<IRQn> preemption priorities in the .ioc to match the
    IRQ_PRIO_* tiers, and ProjectManager.StackSize to 0x1000. Cross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
    [bat_source.ioc]
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2026-08-01 SW: Coalesce EVENT_SM_STEP so only one can sit in the event queue
    Prevents a slow tick consumer from letting periodic SM_STEP ticks
    pile up and starve I2C/EEPROM/BMS events out of the 64-slot queue.
    [event.c]
2026-08-01 SW: Balance cells during the CV tail of a charge cycle
    Uses the BQ76905's built-in per-cell bleed FETs (BQ76905_EnableBalancing,
    already present but never called). Enabled only while
    CTRL_MODE_CHARGE && charge_cv_phase, with 30/20mV start/stop
    hysteresis per cell against the pack minimum. balancing_update() runs
    unconditionally every statemachine tick so the mask is guaranteed back
    to 0 the instant charging stops, for any reason.
    Charge screen: replaced the duty debug readout with a CC/CV phase
    indicator and per-cell balancing color on the cell-voltage line.
    [display.c, statemachine.c]
2026-08-01 SW: Run the protection interlock before the mode switch; fold ISOMETER into the shared button case
    Interlock now evaluated at the top of statemachine_step(), before any
    mode-specific button/output handling runs for that tick, instead of
    after. ISOMETER's out-button handling merged into the shared
    60V_OUT/10A_OUT case via mode_table[].enable_gpio instead of a
    hand-duplicated GPIO_HV_CTRL_EN block. SHUTDOWN entry moved into
    statemachine_switchfromIdle(); CHARGE's duplicate end-voltage reset
    folded into the single completion condition; calibration channel
    selection no longer halves encoder sensitivity.
    [mode_table.c, statemachine.c]
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2026-08-01 SW: About-screen credit line, calibration list cursor spacing fix
    Cursor and selected/unselected label indentation were off by a
    column; ">" now reserves the same width whether or not a row is
    selected.
    [display.c]
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2026-08-01 SW: Print which condition and values caused a CHARGE-mode exit
    Covers all three exit paths: the CC/CV completion check (each
    sub-condition reported independently), ESC press, and the protection
    interlock's recovery-triggered exit (remembers the error mask from
    when the fault first forced output off, since it's already cleared by
    the time CHARGE is actually left).
    [statemachine.c]
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2026-08-02 SW: Added Conv CTRL_EN when shorting secondary side Halfbridge for AMPMETER Mode.
    [mode_table.c, statemachine.c]
2026-08-02 SW: Fixed Line break in Ambient light by reducing line length, fixed lost-index issue, to restore the correct menu item, that was selected before.
    [display.c, statemachine.c]
2026-08-02 SW: Fixed Error, that Isolation mode breaks voltage measurement and return to menu does not fix it
    [adc.c, mode_table.c, statemachine.c]
2026-08-02 SW: up/down arrows swapped in cli control
    [cli.c]
2026-08-02 SW: cli error message on failed to enter current measurement mode due to residual voltage
    [statemachine.c]
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2026-08-09 SW: Fix ISOMETER ADC trigger routing (HRTIM TRG2 not wired to ADC1)
    ADC_TRIGGER_HRTIM_HV moved from HRTIM TRG2 to TRG5, and ADC3's own
    trigger from TRG2 to TRG1, so v_hv (and everything else gated on
    ADC1's conversion-complete callback) actually updates in ISOMETER
    mode instead of appearing frozen.
    [adc.c, adc.h, bat_source.ioc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]
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2026-08-18 SW: Isolation measurement display value corrected
    [display.c]
2026-08-19 SW: BMS coulomb counter value corrected (0.25 userAsec)
    [bq76905.c, cli.c, display.c]
2026-08-21 HW: High voltage relay coil polarity correction
    [Output_Terminals.SchDoc, PS1-1BC.PrjPcb]
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2026-08-24 SW: BMS passed Q corrected
    [cli.c, display.c]
2026-08-24 SW: Charging: ramped reference replaced with stepped reference, highest cell voltage used for precise feedback in CV charging, output of adc values on cli during charging
    [ctrl_main.c, statemachine.c]
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2026-09-08 HW: New project name applied to PCBs, no longer used PCBs removed
    [Backlight_Driver.SchDoc, Battery_BMS.SchDoc, Connector.SchDoc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]
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2026-09-20 SW: Add hidden Tetris game, started by holding OK on Settings > About
    Self-contained in tetris.c/tetris.h: encoder moves, OK rotates, OUT soft
    drops, ESC quits. Uses nothing but input.h and the LCD, so no mode,
    mode_table, menu or display entry is needed - a new settings sub-mode would
    have shown up in the visible settings list and needed a SETTINGS_ITEMS name
    to avoid a NULL deref. The hook in statemachine_step() returns before the
    shared ESC tail, otherwise the ESC that quits the game would drop the
    device to IDLE in the same tick.
    Runs one frame per 20 ms statemachine tick instead of a loop of its own, so
    cli_loop(), the event queue, the BMS poll, the backlight fade and
    protection_update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
    [statemachine.c]
2026-09-21 SW: Restore LCD SPI4 write clock to the configured 40 MHz
    SPI_PRESCALER_LCD_WRITE (lcd.h) had been left at 16 (10 MHz) since the
    very first "getting the LCD running" bring-up commit (317ef30) - a
    quarter of the 4/40 MHz that spi.c's static MX_SPI4_Init() and
    bat_source.ioc (SPI4.CalculateBaudRate=40.0 MBits/s) already agree on.
    The define's own trailing "//4 // 40MHz" was that commit's leftover
    note of the value actually wanted; nothing documents 16 as an
    intentional fallback (no known-issues entry, no signal-integrity
    comment).
    It matters past boot: LCD_ReadCmd() (only reached from LCD_init()'s
    four panel-ID reads) is what leaves SPI4 at this rate afterwards, so
    every draw for the rest of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
2026-09-21 DOC: Correct SPI4/LCD "bit-banged" claim in architecture.md and firmware.tex
    Both docs called SPI4 "software bit-bang due to a PCB layout constraint".
    The code says otherwise: spi.c's MX_SPI4_Init() configures SPI4 as an
    ordinary hardware SPI peripheral, lcd.c drives bulk transfers via
    HAL_SPI_Transmit_DMA, and bat_source.ioc maps PE2/PE5/PE6 to the SPI4
    SCK/MISO/MOSI peripheral pins. Only PE3 (DISPLAY.WR, the D/C line) and
    PE4 (DISPLAY.CS) are plain GPIO outputs toggled by hand around each
    transfer (LCD_DC/LCD_CS in lcd.h) - the usual wiring for an SPI LCD, not
    bit-banging.
    Found while investigating the LCD write-speed bug in the previous
    commit; nothing in the repo documents an actual PCB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
2026-09-22 SW: Multi-phase CHARGE start to fix inrush, single-step bench test, CHARGE_DEBUG flag
    Precharges the converter output open-loop with the output relay open,
    closes the relay only once it is near the charger voltage, hands the
    current loop over at the zero-current duty, then ramps charge current
    slowly instead of starting near the maximum-current duty. Adds a
    CLI-driven single-step test mode (chargeStep/chargeNext) and moves all
    of the bench printouts and those two commands behind a CHARGE_DEBUG
    flag (off by default) so none of it is in a normal build. Also fixes
    the wired-cell-count loop, moves the charge debug print out of the
    control ISR, only marks the pack full on true completion, and add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
    [adc.c, cli.c, ctrl_main.c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]
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2026-09-23 SW: Deep-discharge charging: recover a BMS-undervoltage pack without opening K1
    CUV latches the BMS's DSG FET open, leaving the device powered only through
    K1 (normally closed) feeding the charger into OUT_LV. statemachine_switchtoIdle()
    now keeps K1 closed whenever CUV is latched, covering every CHARGE exit path
    (fault, stuck-open, ESC, boot) through one chokepoint. IDLE auto-entry gets a
    second branch that starts a reduced-current CC_RAMP directly
    (statemachine_enter_charge_low_current(), charge_seq_init_low_current_recovery()),
    skipping PRECHARGE since V_IN reads ~0 with the battery-side FET open;
    recovery current reaches the pack through the separate charge FET and the
    DSG FET's body dio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
    [aux_io_ctrl.c, ctrl_main.c, ctrl_param.h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]
2026-09-23 SW: Show red error banner when AMPMETER entry is refused, splash title capitalization fix
    statemachine.c refused AMPMETER entry (voltage present at terminals) with
    only a CLI printf, no on-screen feedback. New display_show_idle_error()
    draws a red single-line message in the black space between the status bar
    and the icon carousel; cleared for free the next time the encoder moves the
    carousel or by whatever the next OK press does (success leaves idle, a
    repeat refusal just redraws the same message).
    splash.c: "Scrutester" -> "ScruTester", matching the UI rename.
    [display.c, statemachine.c]
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2026-09-23 SW: Battery icon now redraws automatically when charge_percentage changes
    The status-bar battery icon was only refreshed by scattered per-mode
    update_*() calls, missed entirely by several screens (idle, the settings
    list/detail pages, calibration), so it stayed stale there. Replaced with
    display_refresh_battery_icon(): a single change-gated redraw called
    unconditionally once per tick from statemachine_step(), covering every
    screen uniformly. No added overhead -- it only writes to the LCD when
    bms.charge_percentage actually differs from what was last drawn, which
    itself can't happen faster than the BMS's own ~1 Hz poll.
    [display.c, statemachine.c]
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2026-09-23 SW: Fix wrong index selected when returning from a settings submenu
    input_encoder_reset() read settings_mode (the submenu being left) after it
    had already been overwritten to STATEMACHINE_SETTINGS_MODE_MENU, so it
    always reset to the same wrong value instead of the submenu just exited.
    The list briefly showed the correct highlighted entry (current_menu_index
    was still correct), then snapped away from it on the very next tick once
    the wrongly-reset encoder was re-read. Reordered so the encoder read happens
    before settings_mode is overwritten.
    [statemachine.c]
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2026-09-23 SW: Tetris sim: model 1 encoder count per detent, stricter self-play check
    After ENC_PER_STEP went to 1 the simulator's knob (2 counts per detent)
    moved the piece two columns per turn, so self-play collapsed to 2 lines in
    40000 frames (71 game-overs, was 154 lines) - and still reported "ok",
    because the check only demanded a single cleared line. The knob is now
    SIM_COUNTS_PER_DETENT (1), and self-play must clear at least frames/1000
    lines, so a mismatch between the simulator and tetris.c fails instead of
    passing by luck. Self-play is back to 154 lines / level 16.
    tetris.c: only the ENC_PER_STEP comment changed. input.h still documents
    2 counts per detent, which the bench result contradicts;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

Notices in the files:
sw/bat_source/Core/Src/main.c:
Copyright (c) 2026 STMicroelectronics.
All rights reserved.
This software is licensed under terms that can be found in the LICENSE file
